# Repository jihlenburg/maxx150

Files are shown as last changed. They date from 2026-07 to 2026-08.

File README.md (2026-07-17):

# Belluna-Super-Fan-Adapter für den Challenger X150

Parametrisches FreeCAD-Modell eines 28-mm-Adapterrahmens für den Belluna Super
Fan im vorhandenen 400×400-mm-Dachausschnitt. Das Bauteil besteht aus vier
rotationsidentischen L-Segmenten und wird als ein Universalteil mit Stückzahl
vier bereitgestellt.

## Projektstatus

**Aktueller Parameterstand:** `8eb8b79f` · **GEOM_REV:** `10`
**Freigabestatus:** `PROTOTYPE_ONLY`

Geometrie-, DFM-, FEM-, analytische, Lastpfad- und digitale Passungsnachweise
sind Teil der Pipeline. Eine Produktionsfreigabe besteht trotzdem noch nicht:
Nicht verfügbare Werkstoff-/Haftversuche sind durch stark abgeminderte,
quellenbasierte Annahmen ersetzt (`PASS_ASSUMPTION_BASED`); endgültiger
Dachausschnitt, Doppelraupe und Holzrahmen bleiben beim Einbau zu
kontrollieren. Die acht seitlichen Dachrahmenschrauben sind eine physische,
aber mangels typgeprüftem Schraubgrund rechnerisch nicht angerechnete Reserve.
Die Dateien unter
[`release/current`](release/current/) sind daher ein nachvollziehbarer
Release Candidate, keine stillschweigende Serienfreigabe.

## Ein Einstiegspunkt

```sh
python3 -m pipeline doctor       # Werkzeugkette prüfen
python3 -m pipeline test         # komplette Testsuite
python3 -m pipeline engineering  # Konstruktion + DFM + FEM + Report + Export
python3 -m pipeline connections  # Klebe-, Schraub- und Dachsandwich-Lastpfade
python3 -m pipeline fit          # Belluna-Rekonstruktion gegen Adapter prüfen
python3 -m pipeline cfd          # aerodynamisches Hüllmodell + OpenFOAM
python3 -m pipeline render       # technische Konstruktionsansichten
python3 -m pipeline heatmap      # FEM-Heatmaps
python3 -m pipeline manual       # Montagebilder + PDF
python3 -m pipeline references   # Belluna-Referenzmodelle neu exportieren
python3 -m pipeline release      # verifizierten Stand paketieren
python3 -m pipeline all          # alle Stufen in Gate-Reihenfolge
```

Alle temporären Ergebnisse landen unter `build/<stufe>/<parameter-hash>/`.
Nur geordnete Herstellerreferenzen und der explizit paketierte Release
Candidate werden versioniert.

## Struktur

| Pfad | Verantwortung |
|---|---|
| `params.py` | einzige Quelle für Geometrie-, Last- und Materialparameter |
| `model/` | B-Rep-Rahmen, Segmentierung und DFM-Geometrie |
| `fem/` | Lastfälle, Materialmodell, CalculiX und analytische Nachweise |
| `analysis/` | Belluna-Passung sowie Klebe-, Schraub- und Sandwich-Lastpfade |
| `cfd/` | Belluna-Aerohüllmodell, OpenFOAM-Fall und Kräfteauswertung |
| `export/` | STEP/STL/3MF und technische Montagenotiz |
| `render/` | technische Blender-Ansichten und Heatmaps |
| `montage/` | Generator der illustrierten Montageanleitung |
| `pipeline/` | zentrale Orchestrierung und Release-Paketierung |
| `reference_models/` | parametrische Rekonstruktionen externer Schnittstellen |
| `references/` | Datenblätter, Belluna-Unterlagen und Referenzmodelle |
| `release/current/` | aktueller, manifestierter STL-/STEP-Stand |
| `docs/` | aktuelle Doku; historische Arbeitspläne nur unter `docs/archive/` |
| `tests/` | Suite inklusive Geometrie-, FEM-, Referenz- und Doku-Wächtern |
| `scripts/` | Bedienhelfer (Messwertübernahme nach `params.py`) |
| `bin/` | `fc`-Wrapper für headless FreeCAD |
| `project_paths.py` | zentrale Build-/Artefaktpfade für alle Stufen |
| `messwerte.json` | reale Messwerte (Eingabe für `scripts/apply_measurements.py`; kann uncommittete Nutzerdaten enthalten) |
| `messwerte.beispiel.json` | dokumentierte Feldvorlage des Messprotokolls |

### Ordnungsprinzipien

Die Struktur folgt vier Schichten — **Eingaben → Verwandlung → Wissen →
Ergebnisse** — mit fünf Regeln:

1. **Eine Quelle, ein Hash.** Alles beginnt bei `params.py`; der achtstellige
   Parameter-Hash steckt im Namen jedes Artefakts. Ein Artefakt ohne
   zugehörigen Report gilt als nicht nachvollziehbar.
2. **Code fließt in eine Richtung.** `model` baut Geometrie, `fem`/`analysis`/
   `cfd` beweisen sie, `export`/`render`/`montage` erzeugen Artefakte,
   `pipeline` orchestriert das als Gate-Kette. Kein Modul greift rückwärts.
3. **Versioniert wird Wissen, nicht Rechenergebnis.** `docs/` und der
   Quellenbestand unter `references/` sind nicht regenerierbar und daher
   getrackt; `build/` ist hash-segregierte Wegwerfware. Zwei getrackte Zonen
   schreibt die Pipeline selbst: `release/current/` (genau ein eingefrorener
   Stand, ausschließlich Release-Stufe) und `references/belluna/models/`
   (Belluna-Rekonstruktion, references-Stufe).
4. **Fremdes bleibt als Fremdes markiert.** Belluna-Modelle sind vermessene
   Rekonstruktionen; ihr Manifest pinnt sogar den SHA-256 der Quelldatei.
5. **Doku kann nicht veralten.** `tests/test_documentation.py` erzwingt
   intakte Links, aktuelle Einstiegspunkte und den aktuellen Parameterstand
   in README und Projektstatus.

Einsortierregel für neue Dateien: „Ist es Eingabe, Code, Wissen oder
Ergebnis?" beantwortet fast immer allein, wohin sie gehört.

## Offene Punkte und Historie

- Offene Arbeitspunkte: [`docs/project-status.md`](docs/project-status.md)
  (testgesichert aktuell; `TODO.md` in der Wurzel ist ein Symlink darauf).
- Projekthistorie: [`docs/archive/logbook.md`](docs/archive/logbook.md)
  sowie die SDD-Ledger unter `docs/archive/` (nicht normativ; `LOGBOOK.md`
  in der Wurzel ist ein Symlink darauf).

## Dokumentation

- [Dokumentationsindex](docs/README.md)
- [Aktuelles Design](docs/design.md)
- [Pipeline und Artefakte](docs/pipeline.md)
- [Nachweise und Freigabestatus](docs/verification.md)
- [Klebe-, Schraub- und Dachlastpfade](docs/load-paths.md)
- [CFD-Modell und Windlasten](docs/cfd.md)
- [Generator der Montageanleitung](docs/assembly-manual.md)
- [Referenz- und Datenblattkatalog](references/README.md)

## Grundregel

Jede geometriewirksame Änderung erhöht `Params.GEOM_REV`. Jede Änderung an
Parametern verändert den achtstelligen Parameter-Hash. Kein Fertigungsfile
gilt ohne zugehörigen Report und SHA-256-Manifest als nachvollziehbar.

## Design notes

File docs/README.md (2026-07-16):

# Dokumentation

Nur die folgenden Dateien beschreiben den aktuellen Projektstand:

- [`design.md`](design.md): Schnittstellen, Geometrie und Materialsystem.
- [`pipeline.md`](pipeline.md): Stufen, Werkzeuge, Verzeichnisse und Befehle.
- [`verification.md`](verification.md): Nachweise, Gates und Releasezustände.
- [`load-paths.md`](load-paths.md): konservative Klebe-, Schraub- und
  Dachsandwich-Abschätzung mit Quellen und Rechenannahmen.
- [`cfd.md`](cfd.md): Belluna-Aerohüllmodell, OpenFOAM-Fall und Modellgrenzen.
- [`assembly-manual.md`](assembly-manual.md): Aufbau des PDF-Generators.
- [`project-status.md`](project-status.md): offene physische und technische Punkte.
- [`measurements/`](measurements/): Messprotokoll und Messskizzen.

`archive/` enthält historische Implementierungspläne und Arbeitsnotizen. Sie
sind zur Nachvollziehbarkeit erhalten, aber nicht normativ. Bei Widersprüchen
gelten `params.py`, Tests und die aktuelle Dokumentation oben.

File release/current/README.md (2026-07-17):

# Aktueller Adapterstand

Parameterstand `8eb8b79f` · GEOM_REV `10` · Status `PROTOTYPE_ONLY`

- `Belluna_Adapter_Universal_x4_8eb8b79f.step`: ein Universalsegment in Einbaulage.
- `Belluna_Adapter_Universal_x4_PRINT_8eb8b79f.stl`: dasselbe Segment in Drucklage.
- Stückzahl: **4**, nur um Z drehen, nicht spiegeln.
- `verification_report_8eb8b79f.md`: zugehöriger rechnerischer Nachweis.
- `fit_summary_8eb8b79f.json`: digitaler Passungscheck gegen die Belluna-Rekonstruktion.
- `manifest.json`: Prüfsummen, Quellcommit, Werkzeugversionen und offene Gates.

`PROTOTYPE_ONLY` ist keine Produktionsfreigabe. Reale Einbaukontrollen und die Erkenntnisgrenze der annahmenbasierten Werkstoffpfade stehen in `docs/verification.md` und `docs/load-paths.md`.

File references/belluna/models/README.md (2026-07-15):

# Belluna-Referenzmodelle

Die Dateien in diesem Ordner sind eine **vermessene Projekt-Rekonstruktion**
der Belluna-Karosseriebefestigungsplatte einschließlich Metallclips und
Dichtring. Sie stammen nicht von Belluna und dürfen nicht als Hersteller-CAD
weitergegeben oder bezeichnet werden.

Quelle der Geometrie: `reference_models/belluna.py`.

Reproduzierbarer Export:

```sh
python3 -m pipeline references
```

`manifest.json` trennt gemessene von weiterhin angenommenen Abmessungen und
enthält die Prüfsummen sämtlicher STEP-/STL-Dateien.

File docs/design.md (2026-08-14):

# Design: 3D-gedruckter Adapterrahmen — Belluna Super Fan im Mini-Heki-Ausschnitt (Challenger X150 / Chausson X550)

Stand: 2026-07-16 · Parameterstand `8eb8b79f` · Status `PROTOTYPE_ONLY`

## 1. Ziel und Kontext

Der Belluna Super Fan Dachventilator soll den vorhandenen Mini-Heki im 400×400-mm-Dachausschnitt
eines Challenger X150 (baugleich Chausson X550) ersetzen. Das Dach dieser Fahrzeuge hat eine
umlaufende hohe Kante am Heck; die Lüfterhaube (Grundriss 593 mm lang, Überstand nach hinten)
würde beim Öffnen/Schließen mit dieser Kante kollidieren. Ein Adapterrahmen („Plinthe") hebt die
Lüfterbasis um **28 mm** an. Vorbild ist ein im X150-Forum dokumentierter, handgefertigter
Holzsockel; hier entsteht stattdessen ein **algorithmisch erzeugtes, 3D-gedrucktes, per FEM
verifiziertes** Bauteil.

Erzeugung und Verifikation laufen vollständig skriptiert über headless FreeCAD
mit Gmsh-Vernetzung und CalculiX-Solver aus dem FreeCAD-Bundle. Kein GUI-Schritt
ist Teil des reproduzierbaren Workflows.

## 2. Feste Eingangsdaten

### Aus der Belluna-Einbauanleitung (liegt vor, 22 S.)
| Größe | Wert |
|---|---|
| Lochgröße (Dachausschnitt) | 400 × 400 mm, Eckenradius R5 |
| Zulässige Einbauwandstärke | 27–80 mm |
| Vierkantwellen (mitgeliefert) | 120 mm ↔ 27–47 mm · 140 mm ↔ 48–67 mm · 160 mm ↔ 68–80 mm |
| Karosseriebefestigungsplatte | 593 × 420/450 mm, asymmetrischer Flansch (Überstand heckseitig) — Achtung, eigene Vermessung weicht ab: Flansch 450 × 450 voll symmetrisch, Kragen 397 (`reference_models/belluna.py`); 593 × 420 entspricht der Haube |
| Innenrahmen Lüfter | 445 × 445 mm |
| Haubenhöhe über Dach | 127 mm (zu) / 182 mm (offen) |
| Unterbau unter Dach | 31–47 mm |
| Befestigung laut Hersteller | Verklebung der Platte mit Carloflex (Ringklebenut); Verschraubung von oben nicht empfohlen (Wassereintritt); mechanische Option: seitliche Verschraubung in Holzrahmen |
| Schrauben | ST4.2×25 (Platte↔Karosserie, oben, nicht empfohlen) · ST3.9×40 (Lüfter↔Karosserie) · PT4.0×12 (Zwischen-↔Innenrahmen) |
| Masse Belluna | 5,0 kg |

### Fahrzeug (Challenger X150)
| Größe | Wert / Quelle |
|---|---|
| Dachstärke X-Modelle | **35 mm** (Hersteller-Diagramm: GFK-Außenhaut, XPS-Kern, Holzlage innen) |
| Dach am Ausschnitt | plan (Fotobefund), Mini-Heki in Dichtmittelbett verklebt |
| Reisegeschwindigkeit | bis 160 km/h |

### MaxxFan Deluxe (Hüllkurven-Lüfter für die Auslegung, Maßblatt liegt vor)
| Größe | Wert |
|---|---|
| Haube L × B | 586 × 408 mm |
| Höhe geschlossen / offen | 132 / 236 mm |
| Hecküberstand offen ab Dachausschnitt | 179 mm (123 mm bis Haubenknick) |
| Masse | 6,5 kg (Belluna: 5,0 kg) |

### Vermessene Belluna-Karosseriebefestigungsplatte
- Flanschoberseite plan, Schraublöcher verstöpselt; schwarze Dichtung umlaufend am Kragenfuß (Dichtebene Platte↔Lüftereinheit).
- Unterseite: Klebe-/Kontaktzone ist der **äußere Flanschbereich mit konzentrischen Ringrippen**
  (Ringklebenut); die Dreiecks-Gussets tauchen in den Ausschnitt und benötigen
  keine Deckflächenfreistellung.
- Unterer Einbaukragen: 397 mm außen, 1,5 mm Wand, 19 mm tief. Daraus folgen
  nominal 1,5 mm Radialluft je Seite in der 400-mm-Öffnung.
- Oben acht Federstahlclips als Schraubaufnahmen; schwarzer Dichtring 6 mm breit.
- Die versionierten STEP-/STL-Dateien unter `references/belluna/models/` sind
  eine Projekt-Rekonstruktion und ausdrücklich kein Hersteller-CAD.

### Abgeleitete Kerngröße
Effektive Einbauwandstärke = 35 mm Dach + 28 mm Adapter = **63 mm → 140er-Vierkantwelle**
(Bereich 48–67 mm, 4 mm Reserve zur Obergrenze). Die Pipeline berechnet die Wellenwahl aus den
Parametern und schreibt sie in die Montagenotiz.

## 3. Anforderungen

1. **Funktion:** Lüfterbasis um 28 mm anheben (`H_RAISE`, Parameter); Innenöffnung 400×400 mm
   fluchtend zum Dachausschnitt; Einbaukragen des Lüfters wird durchgesteckt wie durch ein 63-mm-Dach.
2. **Festigkeit:** Auslegungsanströmung 200 km/h (= 160 km/h Reise + Böen-/Gegenwindreserve),
   Schlechtweg ±4 g vertikal / ±2 g quer auf 6,5 kg Auslegungsmasse (Maxxfan-Hüllkurve; Belluna 5,0 kg).
3. **Temperatur:** Bauteiltemperatur −20 … **+85 °C** dauerhaft formstabil und tragfähig.
4. **Fertigung:** Druckservice, druckerunabhängig; Segment-Boundingbox ≤ 300 mm
   Kantenlänge (`SEG_MAX_BBOX` = 300 mm; Bambu H2D 350 mm verfügbar);
   stützenfrei druckbar. Das reale Segmentmaß ist ein automatisches DFM-Gate.
5. **Material & Prozess (§3.5):** **Würth ASA GF15 Verkehrsschwarz ähnlich
   RAL 9017, 1,75 mm, Art.-Nr. 4954641200** aus lokaler FDM-Fertigung
   (Plan-of-Record 2026-07-15). 15 % Glasfaser; gehärtete Düse und geschlossener,
   temperierter Bauraum sind Projektpflicht. Drucklage ist Deckfläche nach unten;
   47°-Kammerdächer, 47°-Entwässerungsfase und Ø4-Querkanäle sind supportfrei
   (47° zählen ab Horizontale = 43° Überhang aus der Senkrechten, konform zur
   45°-DFM-Grenze in §7).
   Brim ≥10 mm und langsames Abkühlen bleiben Pflicht. Würth nennt Dichte
   1,1 g/cm³ und HDT/B 99 °C bei 0,45 MPa, aber keinen HDT-Wert bei 1,82 MPa.
   Die publizierten mechanischen Werte stammen ausdrücklich aus Halbzeug, nicht
   aus FDM-Probekörpern. Deshalb bleiben E=3000 MPa, Zug=45 MPa, CTE=60e-6 1/K
   und Z-Faktor 0,5 konservative Projektannahmen. Da typgeprüfte XY-/Z-Coupons
   aktuell nicht realistisch verfügbar sind, werden diese Faktoren nicht
   hochgestuft; das Ergebnis bleibt `PASS_ASSUMPTION_BASED` (den Status
   `PROTOTYPE_ONLY` halten die offenen physischen Gates, s.
   `docs/verification.md`). Pauschales Tempern ist nicht freigegeben.
   Der schwarze Rohling wird vor dem Dacheinbau zwingend weiß beschichtet:
   Mipa 1K-Plastic-Grundierfiller-Spray (Art.-Nr. 213390000) plus Mipa PUR HS
   2K-PUR-Acryl-Fahrzeuglack RAL 9003 Signalweiß glänzend und Mipa 2K-MS-Härter
   MS 25 (2:1 Volumen). Weiß ist Teil der Thermikauslegung. ASA-GF steht nicht
   in der Primerliste; der Lack ist deshalb kein struktureller Lastpfad und
   wird jährlich kontrolliert.
6. **Befestigung:** Adapter ↔ Dach und Platte ↔ Adapter werden mit
   **Sikaflex-522 weiß** verklebt und abgedichtet (Elastikfuge bzw.
   Ringklebenut). **Carloflex 410 UV weiß** ist eine Belluna-konforme
   Alternative. Sein TDS nennt >1,8 MPa Zugfestigkeit, >450 % Dehnung und
   −40 bis +90 °C; die Lastpfadrechnung setzt daher für beide Produkte
   dieselben stark abgeminderten Grenzwerte von 0,030 MPa normal und
   0,050 MPa Schub an. 522 bleibt Standard, weil Sika den
   Vorbehandlungsprozess namentlich dokumentiert; das Carloflex-TDS nennt
   seinen Kunststoffprimer nicht. Je Baugruppe nur eines der beiden Systeme
   vollständig verwenden und nicht mischen. Die
   strukturellen Klebezonen bleiben lackfrei: ASA-GF/Belluna-Kunststoff sehr
   fein anschleifen, Sika Cleaner P und als ABS-Analogie Sika Primer-507;
   GFK-Gelcoat sehr fein anschleifen, Sika Cleaner P und Sika Aktivator-205
   gemäß jeweils aktuellem Produktdatenblatt. Acht Belluna-ST4.2×25 verbinden
   die äußeren Belluna-Seitenlöcher mit den lokalen Universalrippen; jede
   Seite hält ±140 und ±165 vor, ohne offene Vorratslöcher. Der Adapter wird
   zusätzlich mit acht seitlichen ST4.2×25 durch den Unterkragen im Holzrahmen
   gesichert. Diese Schrauben sind eine physische Rückfallebene; wegen der
   unbekannten Holz-, GFK- und Gewindetragfähigkeit werden sie rechnerisch
   nicht angerechnet. Der Primärnachweis wird allein von zwei getrennten,
   jeweils 10 mm breiten Sikaflex-Raupen geführt. Die äußere Raupe bleibt
   geschlossen und wasserdicht. Die innere besitzt acht 5-mm-Unterbrechungen
   zur trockenen Öffnungsseite, damit der dazwischenliegende 4-mm-Kanal
   Feuchte zur Durchhärtung nachführen kann. Die wirksame Fläche beträgt
   33.313 mm² bei 406 mm Innen- und 454 mm Außenmaß und liegt vollständig
   über dem nachgerüsteten 30-mm-Holzrahmen im XPS. Der Holzrahmen wird mit
   **SikaForce-710 L35 + SikaForce-010** (2K-PUR, 100:25 Volumen bzw.
   100:19 Gewicht) vollflächig eingesetzt. Das System ist ausdrücklich für
   Holz/GFK mit EPS/XPS-Sandwichkernen spezifiziert; Auftragsmenge und
   Pressprozess müssen gleichmäßig, hohlraumarm und unterhalb der
   Druckfestigkeit des Dachkerns bleiben. Er ist vollflächig verklebter
   Lastverteiler und Kompressionsschutz. Seine Schraubtragfähigkeit wird ohne
   Bauteilprüfung dennoch nicht als rechnerischer Lastpfad angesetzt. Verwendet werden
   trockene Nadelvollholz-Leisten mit ρk ≥ 350 kg/m³ und Faser längs zur
   jeweiligen Rahmenseite.
   Die zwei Belluna-Mittellöcher an den Segmentstößen bleiben frei. Keine Verschraubung
   von oben durch eine Dichtfläche.
   **Reale Einbausituation (User 2026-07-12): KEINE harte Klemmkette durchs Sandwich** —
   Lüfter geklebt + Kragen formschlüssig im Schacht, von unten nur die Zierblende.
   LF3 bleibt als bewusst konservative Hüllkurve (Montage-Grenzfälle). Die
   untere Doppelraupe trägt den Primärfall allein; die acht Seitenschrauben
   bleiben davon getrennte, unqualifizierte Reserve.
7. **Dichtheit:** 16 schmale Abstandspads definieren 3 mm Dachabstand; die
   0,6-mm-Applikationsführungen ergeben darin 3,6 mm wirksame Raupenhöhe.
   Geschlossene äußere Raupe und Kehlnaht bilden die Wassersperre. Die
   seitlichen Schrauben werden ausschließlich von der trockenen Öffnungsseite
   gesetzt und abgedichtet; sie durchdringen weder Dachaußenhaut noch äußere
   Wassersperre.

## 4. Bauteilgeometrie

**Grundform:** rechteckige Plinthe, Höhe `H_RAISE` = 28 mm, Innenöffnung 400×400 mm mit R5-Ecken.

**Querschnitt (umlaufend):**
- **Deckfläche:** plane Klebefläche unter der Ringklebenut-Zone der Platte; außerhalb
  des 450-mm-Flansches geht sie in eine 47°-Entwässerungsfase über. Breite je Seite
  einzeln parametrisierbar (`W_TOP_FRONT/REAR/LEFT/RIGHT`, Stand 50 mm), da der
  Plattenflansch asymmetrisch ist. Innen liegender Bereich mit parametrischer **Freistellung**
  (Tiefe `REC_GUSSET`) für die Dreiecks-Gussets der Plattenunterseite.
- **Innenwand:** 8 mm umlaufend; jede Seite besitzt an ±140 und ±165 mm
  lokale 10-mm-Vollmaterialrippen über den ganzen 25-mm-Schraubpfad. Acht
  der sechzehn möglichen Pfade werden durch die realen Belluna-Löcher genutzt.
  Die Rippen sind oben an die Deckplatte angebunden und laufen unten mit 45°
  aus; dadurch bleiben die 43-mm-Kammerzellen weitgehend erhalten und der
  Druck bleibt supportfrei. Kollidierende Ventkanäle werden innerhalb ihrer
  Zelle aus der Rippe verschoben.
- **Außenwand:** geschlossen, unten gefast für die Elastikfugen-Kehlnaht zum Dach.
- **Innenleben:** geschlossene Rippenkammern (zwei konzentrische Kammerringe je Seite,
  Zellenraster parametrisch, Wände/Platten voll dicht gedruckt). Kammerböden (in
§3.5 aus der anderen Bezugslage „Kammerdächer" genannt) als 47°-Chevron
  (stützenfrei in Druckorientierung), horizontale Ø4-Druckausgleichsbohrungen je Zelle
  zur Innenseite. Stoß- und Schraubzonen bleiben
  massiv. Die zwei 17-mm-Ringe füllen das kompakte 50-mm-Band, ohne es als
  28-mm-Massivquerschnitt zu drucken; die Außenwand bleibt 3 mm.
  Eckkammern (90°-Rotationsfortsetzung der Kammerringe um die vier Eckblöcke,
  Task 17) sind seit 2026-07-12 Default EIN (`CORNER_CHAMBERS = True`, Task 20;
  Verzugs-/Gewichtsnutzen, FEM-verifiziert — abschaltbar, die AUS-Variante bleibt
  volumen-anker-geprüft reproduzierbar). Damit ist die Festigkeit geometrie-definiert
  (druckprofil-unabhängig); die FEM rechnet auf der echten Kammergeometrie mit vollem
  E-Modul (INFILL_FACTOR = 1,0). [Entscheidung mit User 2026-07-12, ersetzt
  Slicer-Infill-Ansatz]
- **Unterseite:** 16 längliche Abstandspads (2,5×20×3 mm), jeweils innen und
  außen nahe den acht unteren Schraubachsen. Sie liegen vollständig in den
  trockenen 3-mm-Randstreifen über dem Holzrahmen und greifen nicht in die
  Klebefläche ein. Zwei umlaufende, nur 0,6 mm tiefe und 10 mm breite
  Applikationsführungen liegen ebenfalls vollständig über dem 30-mm-Holzrahmen.
  Die äußere Führung ist geschlossen; die innere besitzt acht modellierte
  5-mm-Brücken, welche den 4-mm-Mittelkanal zur trockenen Öffnungsseite
  entlüften. Gegenüber den früheren 68 Ø8-mm-Rundnoppen sinken harte
  Kontaktfläche und lokale Montagepressung deutlich.

**Segmentierung:** Standard **ein rotationsidentisches L-Ecksegment, 4× drucken**,
Stöße in den Seitenmitten (Spannungsmaxima liegen an den Ecken). Stoßverbindung: Halbüberlappung
(Toleranz `TOL_JOINT` = 0,25 mm, nach Probedruck justierbar) + eine
Durchsteckschraube M5 je Stoß + Klebefläche. Unter der vollständigen
konservativen 480-N-Stoßhülle liegt der einzelne M5 bei 62 %
Lochleibungsauslastung. Die Epoxidklebung wird getrennt mit 77 % nachgewiesen.
Die vier
Kopien werden nur um Z gedreht, nie gespiegelt; ein starker Geometrietest
prüft die Rotationsidentität über die symmetrische Differenz.

**Thermik konstruktiv:** ASA-GF α = 60 µm/(m·K), konservative
Datenblatt-Lückenannahme, vs. GFK ≈25. Der mit Epoxid und M5 vollständig
gefügte Rahmen wird thermisch als **500-mm-Baugruppe**, nicht als entkoppeltes
Drucksegment gerechnet. Von 20 °C Klebetemperatur bis 85 °C entstehen 1,14 mm
Differenzdehnung über die Kante; symmetrisch je Ende (0,57 mm) ergibt dies
rund 38 % des zulässigen Scherbewegungsgrenzwerts (50 % der konservativ mit
3 mm angesetzten Fugenhöhe = 1,5 mm); die reale Raupenhöhe in den
0,6-mm-Führungen beträgt 3,6 mm.
Die Lastaufnahme erfolgt ausschließlich durch die elastische Klebschicht.
Die Pads sind Montageanschläge, kein dauerhafter rechnerischer Lastpfad.

**Dichtheitskonzept (Mehrteiligkeit):** Dichtheit kommt von durchgehenden Elastomer-Ebenen,
nicht vom Druckteil — die Segmentstöße werden von diesen Ebenen überbrückt. Barrierenkette:
(1) erst nach vollständiger Durchhärtung der tragenden Dachraupen aufgebrachte,
zugängliche Sikaflex-522-Schutzkehle außen, umlaufend geschlossen über alle
Stöße; sie ist erneuerbare Wetter-/Kontrollfuge und erhält keine
Tragfähigkeitsgutschrift; (2) äußere
untere Raupe, geschlossen über die Stöße; die innere Raupe ergänzt Tragfläche,
bleibt aber an acht Trockenraum-Vents offen; (3) Ringklebenut der Belluna-Platte auf der
Deckfläche, ebenfalls geschlossen; (4) Stöße selbst: Halbüberlappungs-Labyrinth + vollflächige
2K-Epoxidverklebung der Fügeflächen (M5 = Verpressung/Redundanz, nicht Dichtung).

**Klebstoffwechsel 2026-08-14:** WEICON RK-1300 ist abgelöst. Der MMA-Klebstoff
war rechnerisch passend, hat am realen gedruckten ASA-GF aber nicht getragen.
Ausgewählt ist jetzt **UHU plus endfest 300**, ein 2K-Epoxid mit 90 min
Topfzeit, −40 bis +100 °C und 1:1 aus der Doppelkammerspritze mit statischem
Mischer. Es ist ohne Aktivator, Waage und Zeitdruck zu verarbeiten und deshalb
für die Laienmontage geeignet. Der Bemessungswert bleibt bewusst 0,50 MPa,
obwohl er nun aus 16,5 MPa nach DIN EN 1465 statt aus 6 MPa auf ABS abgeleitet
wird: der Wechsel soll die Nachweiskette nicht rechnerisch entlasten. Der
Abminderungsfaktor steigt damit von 12 auf 33. Der WEICON Epoxyd-Minutenkleber
bleibt trotzdem verworfen, sein TDS nennt nur 2,7 % Bruchdehnung und Tg 44,7 °C
(46,1 °C nach Tempern), also deutlich unter `T_MAX = 85 °C`. Dieselbe Grenze
schließt alle schnellen 5-Minuten-Epoxide aus. Die 0,25 mm `TOL_JOINT` bleiben
unverändert, denn sie liegen im gut verklebbaren Bereich des Epoxids. Damit ist
keine Geometrieänderung verbunden und `GEOM_REV` bleibt stehen.

Drei Punkte aus dem Merkblatt sind ausdrücklich nicht übernommen. Das Merkblatt
nennt Aceton zum Entfetten, das ASA angreift. Auf den Druckteilen wird deshalb
Isopropanol verwendet. Das Merkblatt erlaubt eine Warmhärtung zwischen 70 und
180 °C mit deutlich höheren Festigkeiten, etwa 20 N/mm² nach 45 min bei 70 °C.
Das bleibt ungenutzt, weil für ASA-GF kein pauschales Tempern freigegeben ist.
Die geprüften Klebstoffdicken liegen bei 0,1 und 0,2 mm und damit unter der
Passungsluft von 0,25 mm je Fügefläche, was in der Abminderung mit abgedeckt
ist. Verbindlich bleibt die Verarbeitung bei 18 bis 20 °C: unter 18 °C nennt
das Merkblatt ausdrücklich schlechte Bindefestigkeiten.
FDM-Mikroporosität: ≥4 Perimeter als dichte Haut; der festgelegte Mipa-Primer +
RAL-9003-2K-PUR-Decklack ist PFLICHT (Solarreflexion, Porenschluss, Wetterschutz).
Validierung praktisch (Flutungstest, dann Hochdruck aus
ISO-20653-9K-Abstand am verbauten Sockel); eine normative IP6K9K-Zertifizierung wäre
Prüfstandssache. Systemgrenze: der Belluna selbst ist nur IPX4 — Ziel ist die dichte
Dachdurchdringung, nicht ein dichter Lüfter.

## 5. Software-Architektur

```
maxx150/
├── params.py             # einzige Parameterquelle
├── model/                # B-Rep, Segmente und DFM
├── fem/                  # Lastfälle, Solver, Analytik und Report
├── analysis/             # digitale Passungsanalyse
├── export/               # STEP/STL/3MF und technische Notiz
├── render/               # technische Ansichten und Heatmaps
├── montage/              # Generator der Montageanleitung
├── pipeline/             # zentrale CLI und Release-Paketierung
├── reference_models/     # vermessene externe Schnittstellen
├── references/           # Datenblätter, Anleitungen und Referenz-CAD
├── build/                # generiert, hash-segregiert, gitignored
├── release/current/      # manifestierter Fertigungsstand
└── tests/                # Invarianten und Regressionen
```

**Datenfluss:** `params.py` → `frame.py` (ein wasserdichtes Solid) → (a) `segments.py` →
`export.py`; (b) `fem/`. Der Report verknüpft Parameterstand ↔ FEM-Ergebnis ↔ Datei-Hashes:
kein Druckfile ohne zugehörige Verifikation.

**FEM-Modellstrategie:** Globalnachweis am **ungeteilten** Rahmen (obere Steifigkeitsschranke),
Detailnachweis am Stoß-Submodell mit den Schnittkräften aus dem Globalmodell (untere Schranke).
Kein Vollkontaktmodell aller vier Segmente in CalculiX. Die globale Lagerung
liegt seit GEOM_REV 9 verteilt auf den Böden beider Kleberführungen. Sie
idealisiert Dach und ausgehärteten Klebstoff weiterhin starr, fixiert aber
nicht mehr die 16 Montagepads und vermeidet damit die früheren künstlichen
Punktspannungen an 68 Rundnoppen.

**Fehlerbehandlung:** Jeder Schritt validiert sein Ergebnis (Solid `isValid()` + geschlossene
Shell, Mindestwandstärke, Mesh-Qualität, CalculiX-Konvergenz) und bricht mit klarer Meldung ab,
statt fehlerhafte Artefakte zu exportieren.

## 6. FEM-Verifikation

**Lastfälle:**
| # | Lastfall | Ansatz |
|---|---|---|
| LF1 | Fahrtwind | 200 km/h → q ≈ 1,85 kPa; Haube offen (zulässig lt. Anleitung), Worst Case MaxxFan Deluxe: A = 0,408 m × (0,236 + 0,028) m ≈ 0,108 m² (Maßblatt), cd ≈ 1,2 → ~240 N horizontal, ×2 Sicherheit = **480 N** am Hebelarm der Haubenhöhe (Kippmoment auf Deckfläche) |
| LF2 | Schlechtweg | quasistatisch ±4 g vert. / ±2 g quer auf 6,5 kg → ±255 N / ±128 N |
| LF3 | Klemmung/Montage | Vorspannung Innenrahmen-Verschraubung (aus 0,7 Nm Anzugsmoment lt. Anleitung ≈ 400–600 N je Schraube, konservativ 600 N × 4) + Anzug der Seitenschrauben; Schraubenauszug/Flächenpressung Innenwand. **Konservative Hüllkurve: real keine harte Klemmung (s. §3.6)** |
| LF4 | Schnee/Stand | 0,75 kN/m² auf 0,25 m² Grundfläche = 187,5 N, konservativ 200 N angesetzt |
| LF5 | Thermik | Einsatzbereich −20…+85 °C; bemessungsrelevant ΔT 65 K ab 20 °C Klebetemperatur, CTE-Differenz ASA↔GFK; Nachweis Elastikfuge (analytisch, `fem/analytic.py`) |

**Materialabminderung Würth ASA GF15:** Projektbasis 45 MPa / E 3000 MPa;
keine Behauptung gedruckter Herstellerwerte, da Würth nur Halbzeugdaten nennt.
Faktoren: Temperatur 0,5 · Z-Schichthaftung 0,5 (konservative Annahme) ·
Kriechen 0,4. → zulässig **4,50 MPa dauerhaft**, **11,25 MPa kurzzeitig**.
Drucklage so, dass
Hauptspannungen in der XY-Ebene liegen (Z sieht überwiegend Druck).

**Bestehenskriterien (Pipeline-Gate, automatisch):**
1. σ_vMises ≤ zulässig je Lastfall (Sicherheiten enthalten)
2. Verformung der Deckfläche < 0,5 mm (Dichtheit der Klebefuge)
3. Elastische Klebfuge: 0,030 MPa normal / 0,050 MPa Schub als stark
   abgeminderte Projektwerte; Schraubengruppen separat mit vollständigem
   Lastfall und 1,5-facher Lastkonzentration
4. Flächenpressung/Auszug an der Innenwand ≤ zulässig
5. Optionale Eskalation bei FAIL: Rippen/Wände verstärken (Parameter) oder Material ASA-GF/PC.

## 7. Export, Fertigung, Tests

**Export:** STEP gesamt + genau eine Universal-Segmentdatei (`universal_segment_x4`)
als STEP, STL und 3MF; Dateinamen mit Parameter-Hash.
Auto-generierte Fertigungs-/Montagenotiz: Druckorientierung (liegend auf Deckfläche),
≥4 Perimeter, 100 % Infill (Kammern tragen die Gewichtsreduktion), kein
pauschales Tempern, Schraubenliste, exakte Kleb-/Dicht-/Lackprodukte und Dichtklebstoff-Bedarf (aus
Raupenlänge/-querschnitt berechnet), berechnete Wellenwahl (140 mm bei 35+28).

**DFM als Code-Invarianten:** Überhänge ≤ 45° aus der Senkrechten (stützenfrei;
die 47°-Chevronflächen zählen ab Horizontale = 43° Überhang und sind konform), Mindestwand 2,4 mm, Rippen 1,6 mm,
Nut-Feder-Toleranz parametrisch.

**Tests (headless in FreeCADCmd):**
1. Geometrie-Invarianten: wasserdicht/valide, Öffnung exakt 400×400, Höhe = `H_RAISE`, BBox-Bereich
2. Passung: Feder < Nut um exakt `TOL_JOINT`; boolesche Vereinigung der Segmente ≡ Rahmen − Fugenvolumen
3. DFM-Checks: Überhangwinkel-Scan, Wandstärken-Stichproben
4. FEM-Regression: Referenzparametersatz → erwartete max. Spannung/Verformung ±Toleranz
5. Toolchain-Smokes für Gmsh/CalculiX, Export und Referenzkatalog
6. Digitaler Belluna-Passungscheck: Kollision, Radialspiel, Auflage und Schraubpfade

**Freigabe-Workflow:** `pipeline test` → `pipeline engineering`
(einschließlich `pipeline connections`) → `pipeline fit`
→ reale Einbaukontrollen → `pipeline release`. Die nicht verfügbaren
Werkstoffversuche werden nicht als geschlossen behauptet; ihre Unsicherheit
bleibt über die Abminderungen und `PROTOTYPE_ONLY` sichtbar.

## 8. Offene reale Eingaben

Die Belluna-Plattenschnittstelle ist vermessen und in der Referenzrekonstruktion
dokumentiert. Am Fahrzeug bleiben offen:

1. Realmaß Dachausschnitt (Soll 400×400) + Eckenradius nach Mini-Heki-Demontage.
2. Abstand Ausschnitt-Hinterkante → hohe Dachkante und deren Höhe (**Verifikation der 28 mm**:
   geometrischer Haubenfreigang wird aus diesen Werten im Modell nachgerechnet)
3. Kontrollmessung der Dachstärke am Ausschnitt (Planstand 35 mm).
4. Zustand der Klebefläche und des XPS nach Demontage.
5. Abmessungen und Pressprozess des nachgerüsteten Holzrahmens.

Bis zur Messung bleiben die betreffenden Werte in `params.py` als dokumentierte
Defaults und erzwingen den Status `PROTOTYPE_ONLY`.

## 9. Entscheidungen (Log)

| Entscheidung | Wahl | Alternativen (verworfen) |
|---|---|---|
| Pipeline | A: vollparametrisch, headless FreeCAD + CalculiX | B: GUI+Spreadsheet (nicht reproduzierbar) · C: CadQuery-Stack (Werkzeugvorgabe FreeCAD) |
| Material | **Würth ASA GF15 Verkehrsschwarz, Art.-Nr. 4954641200 + Pflichtlackierung Mipa RAL 9003** | weißes Filament ist nicht verfügbar · PC/ABS erfordert neue UV-/CTE-/Klebe-/Lackqualifikation |
| Befestigung | oben Kleben + 8 seitliche Schrauben; unten 2×10-mm-Doppelraupe plus 8 unbewertete Seitenschrauben | ursprüngliche 8-mm-Einzelraupe (rechnerisch unzureichend) · 25-mm-Bond-only-Verbreiterung (größer/schwerer) · Klemmen (Kriechen der Klemmstelle) |
| Segmentierung | 1 rotationsidentisches L-Ecksegment ×4, Stoß in Seitenmitte | vier seitenspezifische Dateien (Logistik/Verwechslung) · Monolith (kein Bauraum) · 8 Teile (mehr Fugen) |
| Erhöhung | 28 mm (Forum-Vorbild), als Parameter | am realen Haubenfreigang zu verifizieren |
| Welle | 140 mm (aus 35+28 berechnet) | — Pipeline rechnet bei Parameteränderung neu |
| Dach-Befestigung | Zwei 10-mm-Sikaflex-522-Raupen mit 406/454-mm-Hüllmaß vollständig über dem vollflächig eingeklebten Holzrahmen; 16 schmale 2,5×20×3-mm-Abstandspads außerhalb der Klebeflächen, 0,6-mm-Applikationsführungen (drei 0,2-mm-Layer) und 3,6-mm-Raupenhöhe; äußere Raupe geschlossen, innerer Mittelkanal gezielt zur trockenen Seite belüftet; erst nach Primärhärtung eine zugängliche, nichttragende 7×7-mm-Schutzkehle außen; acht seitliche, abgedichtete ST4.2×25 als nicht angerechnete Reserve | 68 Ø8-mm-Rundnoppen mit 5-mm-Raupenhöhe und Punktlasten · ursprüngliche 8-mm-Fuge (unzureichend) · 25-mm-Bond-only-Verbreiterung je Seite (550-mm-Außenmaß und höheres Teilegewicht) · Schrauben durch nasse Dachfläche |

## 10. Risiken und Gegenmaßnahmen

| Risiko | Gegenmaßnahme |
|---|---|
| Kriechen unter Dauerklemmung bei Hitze | Dauerlast-Zulässigkeit 4,50 MPa; LF3-Hüllkurvenannahme: ein etwaiger Klemmpfad läuft über Dach+Adapter-Druckflächen (real keine harte Klemmkette, s. §3.6); FEM LF3 |
| Schichthaftung (Z) versagt | Drucklage: Lasten in XY; permanenter Knockdown 0,5; kein pauschales Tempern |
| Thermodehnung reißt Klebfuge | 16 Pads erzwingen 3 mm Dachabstand; in den flachen Führungen entstehen 3,6 mm Raupenhöhe. LF5 rechnet konservativ weiter mit 3 mm und erreicht 38 % des thermischen Scherbewegungsgrenzwerts. |
| Druckservice-Toleranzen an den Stößen | `TOL_JOINT` parametrisch, Probedruck eines Stoßpaars vor Vollbestellung (Montagenotiz) |
| 28 mm reichen nicht (Haube streift) | reale Fahrzeugmaße + geometrischer Freigang-Check vor Produktionsfreigabe |
| Schwarzer Rohling heizt sich solar auf / Lack löst sich | RAL-9003-Pflichtlackierung mit festgelegtem Mipa-System; Lack trägt keine Struktur; jährliche Kontrolle und sofortige Ausbesserung |
| Reale Grenzfläche schwächer als Datenblatt | `analysis/load_paths.py`: Sikaflex bis Faktor 60, Segmentstoß-Epoxid Faktor 33 und Sandwich auf 0,05 MPa abgemindert; Ergebnis bleibt `PASS_ASSUMPTION_BASED`, nicht zugelassen |
| Zyklische Ermüdung (Thermozyklen x Vibration) nicht im FEM-Kollektiv | Dokumentiertes Restrisiko (quasistatische LF + konservative Faktoren decken es nur indirekt); Gegenmaßnahme: jährliche Sichtprüfung der Nähte, Flutungstest nach 1. Saison [DA-Review] |
| Klemmkraft-Relaxation ASA bei 85 °C | Entschärft: real keine harte Klemmkette (§3.6) — Restrisiko nur seitliche Schrauben; Feder-/Sicherungselemente + Nachziehen bleiben empfohlen [DA-Review, aktualisiert] |
| Freigang-Gate läuft auf Defaults (`EDGE_DIST/EDGE_H`) | Report und Release bleiben `PROTOTYPE_ONLY`, bis reale Fahrzeugmaße vorliegen |

## 11. Erfolgskriterien

1. `python3 -m pipeline engineering` läuft fehlerfrei durch: Modell → DFM → FEM → Export → Report.
2. Alle Tests grün, inkl. Segmente-≡-Monolith und DFM-Checks.
3. Druckdateien: 1 Universal-Segment ×4, rotationsidentisch, stützenfrei,
   Boundingbox ≤ 300 mm.
4. Physisch: Segmente fügen sich passgenau, Lüfter mit 140er-Welle montierbar, Haube öffnet
   kollisionsfrei über der Dachkante, dicht nach Regenfahrt.

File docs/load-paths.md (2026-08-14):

# Abschätzung der Klebe-, Schraub- und Dachlastpfade

Stand: 2026-07-16 · Parameterstand `8eb8b79f` · **PASS_ASSUMPTION_BASED**

> Konservative Plausibilisierung, keine Bauteilzulassung. Die untere
> Doppelraupe trägt den Primärnachweis allein; acht seitliche Holzschrauben
> bleiben eine physische, aber unqualifizierte Reserve.

## Ergebnisübersicht

| Lastfall | obere Elastikfuge allein | 8 Schrauben oben | 2×10-mm-Dachraupe allein | erforderliche Kapazität je Rückfallschraube | Holz–Dach, eine Fläche | serieller Pfad |
|---|---:|---:|---:|---:|---:|---|
| Windhülle 480 N | 157 % | 74 % | 77 % | 144 N (nicht qualifiziert) | 35 % | PASS |
| Schlechtweg | 98 % | 43 % | 44 % | 81 N (nicht qualifiziert) | 18 % | PASS |
| Schnee/Druck | 0 % | 21 % | 0 % | 38 N (nicht qualifiziert) | 0 % | PASS |
| CFD offen, mittel ×1,5 | 71 % | 32 % | 29 % | 54 N (nicht qualifiziert) | 12 % | PASS |

Die obere Belluna-Verbindung bleibt hybrid: Kleber und die acht oberen
Plattenschrauben werden nicht addiert; die Schraubengruppe trägt den vollständigen Fall mit
Lastkonzentrationsfaktor 1,5. Unten müssen die beiden 10-mm-Raupen den
vollständigen Fall allein bestehen. Die acht Holzschrauben werden weder zur
Klebung addiert noch als PASS gewertet. Der Schubgrenzwert 0,050 MPa ist kein
TDS-Schubkennwert, sondern eine bewusst niedrige Projektannahme. Reale
Grenzflächenhaftung und Alterung bleiben unbekannt.

Die CFD-Zeile ist eine zusätzliche Sensitivität aus Matrix `a3a2de8c` und
bleibt nicht freigabewirksam. Die analytische 480-N-Windhülle wird dadurch
nicht reduziert.

## Maßgebende Festwerte

- Obere Ringfuge: 14.016 mm²; 0,030 MPa normal / 0,050 MPa Schub, nicht allein
  maßgebend.
- Untere Doppelraupe: 33.313 mm² wirksam, Innenmaß 406 mm, Außenmaß 454 mm;
  vollständig über dem 30-mm-Holzrahmen, acht innere Trockenraum-Vents,
  0,030/0,050 MPa. Fläche und Volumen folgen den echten gerundeten
  R5-Parallelkonturen; eine Quadratnäherung wird nicht verwendet. 3 mm
  Padabstand plus 0,6 mm Führungsvertiefung ergeben 3,6 mm Raupenhöhe und
  rund 120 ml Nennvolumen.
- Obere ST4.2×25 in ASA-GF: 178 N je Schraube nach Detailfaktor 0,5.
- Segmentstoß unter vollen 480 N: 2K-Epoxid 77 %; ein M5 62 %; beide getrennt PASS.
- Thermische Scherbewegung der 3-mm-Fuge: 38 % des 50-%-Grenzwerts; PASS.
- Obere Schraubengruppe: Eine fehlende Schraube ergibt 83–87 %. Zwei fehlende
  Schrauben bestehen nicht in jeder Anordnung. Alle acht Belluna-Schrauben
  bleiben Pflicht.

## Konstruktive Interpretation

- Der Adapter bleibt bei 500 mm Außenmaß. Zwei getrennte 10-mm-Raupen liefern
  trotz acht 5-mm-Ventunterbrechungen rund 33.313 mm² wirksame Klebefläche.
- 16 schmale Abstandspads mit 2,5×20 mm Kontaktmaß sitzen in den trockenen inneren und äußeren
  Randstreifen nahe den acht Dachschrauben. Sie definieren nur den
  Montagespalt und werden weder von der Klebefläche abgezogen noch als
  struktureller Lastpfad angerechnet.
- Die äußere Raupe bleibt als Wassersperre geschlossen. Nur die innere Raupe
  wird an acht Stellen zur trockenen Öffnungsseite unterbrochen, damit der
  4-mm-Mittelkanal Feuchte nachführen kann. Die Unterbrechungen und der Kanal
  dürfen bei der Montage nicht mit Dichtstoff überbrückt werden.
- Erst nach vollständiger Durchhärtung der tragenden Doppelraupe wird außen
  eine etwa 7×7-mm-Sikaflex-522-Schutzkehle ergänzt (nominal rund 48 ml).
  Sie bleibt sichtbar und erneuerbar und erhält keinerlei
  Tragfähigkeitsgutschrift.
- Acht seitliche ST4.2×25 sichern den Unterkragen im Holzrahmen. Ohne
  typgeprüften Schraubgrund wird nur der je Lastfall erforderliche Wert
  ausgewiesen; die Schrauben werden nicht angerechnet.
- Ein M5 je Stoß trägt die volle 480-N-Hülle allein. Das 2K-Epoxid bildet einen davon
  getrennt geprüften Fügepfad.
- Sikaflex-522 und Carloflex 410 UV werden nur mit den stark abgeminderten
  0,030/0,050-MPa-Werten angesetzt. Produkte innerhalb einer Baugruppe nicht
  mischen.

## Oberflächenannahme für Sikaflex-522

Die tragenden Klebezonen bleiben lackfrei. ASA-GF und Belluna-Kunststoff
werden sehr fein angeschliffen, mit Sika Cleaner P gereinigt und als
ABS-Analogie mit Sika Primer-507 vorbehandelt. GFK-Gelcoat wird sehr fein
angeschliffen, gereinigt und mit Sika Aktivator-205 vorbehandelt. ASA-GF ist
nicht ausdrücklich in der Sika-Tabelle genannt; die Rechnung ist daher keine
Herstellerfreigabe. Carloflex bleibt erst nach prozesssicherer Festlegung
seines im TDS nicht namentlich genannten Kunststoffprimers eine ausführbare
Alternative.

## Modellgrenzen

- Starrer Ring und linear-elastische Lastverteilung; lokale Peelspitzen und
  Gehäusenachgiebigkeit sind nicht aufgelöst.
- Die Rahmen-FEM fixiert die Böden beider Kleberführungen flächig. Das
  beseitigt die frühere künstliche Rundnoppen-Lagerkonzentration, bildet aber
  die reale Nachgiebigkeit des 3,6-mm-Klebstoffs und des GFK-Dachs noch nicht ab.
- Die zwei unteren 10-mm-Elastikraupen sind der allein angerechnete
  Adapter-Dach-Primärpfad. Die acht unteren Seitenschrauben sind mangels
  Holz-/Dachtest nur physische Reserve.
- Die acht oberen ST4.2×25 werden mit einem abgeminderten axialen Analogiewert
  auf den resultierenden Lastvektor geprüft.
- Der einzelne M5 je Segmentstoß wird mit der vollen 480-N-Hülle geprüft;
  expliziter Bolzenkontakt und Lochspiel sind nicht aufgelöst.
- Das reale X150-GFK/XPS-Sandwich ist nicht typgeprüft; deshalb werden nur eine
  Holz/GFK-Fläche und 0,050 MPa angerechnet.
- Werkstoffkriechen unter Dauerlast ist pauschal über `DERATE_CREEP` (0,4 auf
  die dauerhaft zulässige Spannung) abgedeckt. Nicht modelliert ist das
  Setzen/die Vorspannkraftrelaxation der oberen Schraubgruppe (Kunststoff im
  Klemmpaket, beschleunigt nahe `T_MAX`): Die Schraubnachweise sind
  Tragfähigkeits-, keine Reibschlussnachweise und bleiben davon unberührt;
  gegen Lockern unter Fahrvibration gilt die Setzkontrolle nach den ersten
  Fahrten und die jährliche Prüfung (`verification.md`).
- Thermozyklen sind nur als statische Extremfälle geprüft (LF5, ΔT 65 K).
  Tag/Nacht-Zyklen (ΔT ≈ 40 K, tausendfach über die Lebensdauer) erzeugen in
  der unteren Elastikfuge eine Schubverzerrungs-Amplitude von rund 60 % des
  statischen LF5-Werts — bei 38 % statischer Auslastung gegen die bereits
  stark abgeminderte Elastikfugen-Annahme wird das als abgedeckt eingestuft,
  bleibt aber eine dokumentierte Annahme ohne Ermüdungsversuch.
- CFD, FEM und Lastpfadrechnung sind Modellplausibilisierungen, keine
  Bauteilprüfung oder Herstellerfreigabe.

## Primärquellen

- [Sikaflex-522: 1,8 MPa Zugfestigkeit, 400 % Bruchdehnung, −50 bis +90 °C](https://industry.sika.com/en/home/transportation/sealants/adhesive-sealants/sikaflex-522.html)
- [Sika-Leitfaden: zusätzliche, zugängliche Schutzdichtung sowie verzögerte Durchhärtung bei zu frühem Schließen angrenzender Fugen](https://industry.sika.com/dam/dms/global-industry/4/bonding-and-sealingwith1-componentsikaflex.pdf)
- [Sika-Kompendium: Abminderung und typische zulässige thermische Scherverformung](https://industry.sika.com/dms/getdocument.get/8ffff4cd-c90d-4d24-969d-ee4db9093cf3_global-industry/compendium-elasticbonding.pdf)
- [Sika-STP-Vorbehandlungstabelle, Version 8, 02/2026](https://industry.sika.com/dms/getdocument.get/776a779a-10a6-413c-b20b-c46467315e33/pre-treatment-chartforsilanterminatedpolymersstp-sikaflex-500ser.pdf)
- [UHU plus endfest 300: Topfzeit, Temperaturbereich und Zugscherfestigkeit](../references/datasheets/adhesives/uhu-plus-endfest-300.pdf)
- [SikaForce-710 L35 für Holz/GFK-Sandwich mit EPS/XPS-Kern](https://deu.sika.com/dms/getdocument.get/41466f3f-1639-4fc4-8298-5c9a0a2d34e1/sikaforce-710-l35.pdf)
- [URSA-XPS-Vergleichswert TR 200; nicht das X150-Material](https://ursa.de/wp-content/uploads/2023/05/DB-xps.pdf)
- [Carloflex-410-UV-Quelldokument](../references/datasheets/adhesives/carloflex-410-uv-source.md)

Die maschinenlesbare Fassung wird mit `python3 -m pipeline connections` nach
`build/analysis/load_paths/<hash>/` geschrieben.

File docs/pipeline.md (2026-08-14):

# Pipeline und Artefakte

## Datenfluss

```text
params.py
   ├─ model/ ── DFM ── FEM + Analytik ── export/ ── build/engineering/<hash>/
   ├─ reference_models/ + model/ ── Passung ─────── build/analysis/fit/<hash>/
   ├─ Lasten + Verbindungsannahmen ─────────────── build/analysis/load_paths/<hash>/
   ├─ Belluna-Anleitung + Dach ── OpenFOAM ──────── build/analysis/cfd/<cfd-hash>/
   ├─ fem/ ── Spannungsfelder ── Blender ───────── build/analysis/heatmap/<hash>/
   ├─ model/ ── Blender ────────────────────────── build/render/<hash>/
   └─ model/ + Belluna + Dach ── Blender ── PDF ─ build/documentation/<hash>/
                                                        │
                               explizite Paketierung ───┴─ release/current/
```

## Kanonische Stufen

| Stufe | Inhalt | Gate/Ergebnis |
|---|---|---|
| `doctor` | FreeCAD, Blender, Chrome, pdfinfo und Pfade | bricht bei fehlendem Werkzeug ab |
| `test` | Geometrie-, FEM-, Export-, Referenz- und Toolchaintests | alle Tests müssen bestehen |
| `engineering` | Rahmen, Segmente, DFM, vier globale Lastfälle, Stoßmodell, Analytik, Export; ruft danach `connections` auf | Reports dürfen nicht `FAIL` sein |
| `connections` | obere Acht-Schrauben-Gruppe, 2×10-mm-Dachraupe, acht nicht angerechnete untere Seitenschrauben, 2K-Epoxid/ein M5 je Stoß und Holzrahmen–Dachsandwich | `PASS_ASSUMPTION_BASED`; JSON + Markdown |
| `fit` | Belluna-Rekonstruktion gegen Adapter | Kollision, Radialspiel, Auflage, Schraubpfade |
| `cfd` | Aerohüllmodell, `snappyHexMesh`, stationäres RANS und Kräfteauswertung | vorläufige Kräfte/Momente; derzeit kein Release-Gate |
| `render` | Standardansichten und Schnitte | PNG + Render-STL |
| `heatmap` | Knotenspannungen und Hotspots aller Lastfälle | PLY, JSON und PNG |
| `manual` | 15 Montageszenen, HTML und PDF | 15 PNGs in 1500×1125, aktueller Hash und exakt 12 A4-Seiten |
| `references` | Belluna-Rekonstruktion als STEP/STL | separates Provenienz-/Dateimanifest |
| `release` | geprüfte Universaldatei + Report + Fit-Summary nach `release/current` | aktueller Quellcommit, Report-SHA256 und Fit-PASS |

`python3 -m pipeline all` führt die Stufen in dieser Reihenfolge aus;
`connections` läuft dabei nicht als eigene Stufe, sondern wird von
`engineering` und `cfd` mit aufgerufen. Die
Heatmap berechnet die Lastfälle bewusst erneut, weil sie rohe Knotenspannungen
benötigt; der Engineering-Report verwendet aggregierte Ergebnisgrößen.
Die Release-Stufe akzeptiert keine Engineering-Dateien aus einem älteren
Commit und verifiziert STEP/STL erneut gegen das Dateimanifest im Report.

## Verzeichnisvertrag

Generierter Inhalt wird nie anhand eines „neuesten“ Dateinamens gesucht,
sondern stets über den Parameter-Hash:

```text
build/
├── engineering/<hash>/
├── analysis/fit/<hash>/
├── analysis/load_paths/<hash>/
├── analysis/cfd/<cfd-hash>/
├── analysis/heatmap/<hash>/
├── render/<hash>/
├── documentation/<hash>/
└── tests/
```

`MAXX150_BUILD_ROOT` kann für CI oder isolierte Versuche gesetzt werden. Der
frühere Ausgabeordner `out/` aus der Zeit vor der Konsolidierung wurde bei der
Repo-Aufräumung entfernt; der `.gitignore`-Eintrag bleibt als Schutz bestehen,
keine aktuelle Pipeline-Stufe liest oder schreibt ihn.

## Werkzeugversionen

Der aktuell geprüfte lokale Stack ist FreeCAD 1.1.1, Blender 5.1, OpenFOAM
v2606 und Google Chrome Headless. `bin/fc` akzeptiert über `FREECAD_BUNDLE`
eine alternative FreeCAD-App. `BLENDER_BIN` überschreibt den Blender-Pfad.
Die CFD-Stufe verwendet den `openfoam`-Wrapper aus `PATH`.

Die Release-Stufe erfasst die tatsächlich vorgefundenen Versionen
maschinenlesbar im `toolchain`-Block von `release/current/manifest.json`
(Manifest-Schema 3) und verweigert die Paketierung, wenn getrackte
Quelldateien uncommittete Änderungen tragen — sonst würde `source_commit`
einen Stand behaupten, dem der Code nicht entspricht. Nicht als Blocker
zählen untracked Dateien sowie die Pfade, die die Pipeline selbst schreibt
(`release/current/`, `references/belluna/models/`), und `messwerte.json`
(Nutzer-Messdaten, die kein Build liest).

## Messwertübernahme

Messwerte werden bewusst nicht automatisch während eines Builds angewendet:

```sh
python3 scripts/apply_measurements.py messwerte.json --dry-run
```

Eine tatsächliche Übernahme verändert `params.py` und erfordert anschließend
mindestens `pipeline test`, `pipeline engineering`, `pipeline fit` und eine
neue Release-Paketierung.

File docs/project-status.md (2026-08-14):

# Projektstatus

Stand: 17.07.2026 · GEOM_REV 10 · Parameterstand `8eb8b79f`

## Abgeschlossen

- Vier rotationsidentische Universal-L-Segmente statt vier Varianten.
- 28-mm-Erhöhung, 400-mm-Öffnung und supportfreie Kammergeometrie.
- Kompakter 500×500-mm-Hybridrahmen mit zwei getrennten 10-mm-Dachraupen
  vollständig über dem 30-mm-Holzrahmen: äußere Raupe geschlossen,
  4-mm-Mittelkanal und acht definierte Entlüftungen an der inneren Raupe.
- 16 längliche Abstandspads mit 2,5×20 mm Kontaktmaß statt 68 Rundnoppen.
  3 mm Dachabstand plus
  0,6-mm-Applikationsführung ergeben 3,6 mm wirksame Raupenhöhe und etwa
  120 ml Nennvolumen; kein Pad greift in die Klebefläche ein.
- Zwei 17-mm-Kammerringe statt eines massiven Außenbands; Universalteil rund
  530 g und 275×250×47 mm im theoretischen CAD-Modell.
- Acht Belluna-Plattenschrauben oben. Unten acht seitliche ST4.2×25 in den
  Holzrahmen als physische, mangels typgeprüftem Schraubgrund nicht
  angerechnete Rückfallebene; die Doppelraupe besteht den Primärnachweis allein.
- Ein M5 je Segmentstoß; sowohl dieser einzelne Bolzen als auch die Epoxidklebung
  bestehen die vollständige konservative 480-N-Stoßhülle getrennt.
- Digital vermessene Belluna-Rekonstruktion mit 397-mm-Unterkragen und
  1,5-mm-Wand; Metallclips und Dichtring als getrennte Referenzteile.
- DFM-, FEM-, analytische, Passungs-, Export- und Referenztests.
- Quellenbasierte Lastpfadabschätzung für Klebungen, obere Schraubengruppe,
  Segmentstöße und das Dachsandwich (`PASS_ASSUMPTION_BASED`).
- Definiertes Kleb-/Dicht-/Lacksystem und reproduzierbarer Montagegenerator.
- Einheitliche Pipeline und geordneter Build-/Release-/Referenzaufbau.
- Reproduzierbarer erster OpenFOAM-Grobfall für die geschlossene Belluna-
  Aerohülle bei 200 km/h; noch kein Freigabe-Gate.
- Deterministischer Toleranz-Sweep der Messkampagnen-Parameter durch alle
  analytischen Gates (`scripts/toleranz_sweep.py`). Kernbefunde: `W_TOP` hat
  beim aktuellen Parameterstand nach unten null Toleranz (50,0 mm liegt exakt
  auf der 2-mm-Mindestbreite der Entwässerungsfase — Messwerte darunter
  erfordern Nachparametrierung); die knappste freigabewirksame Grenzfläche
  (Epoxidstoß bzw. Doppelraupe) bleibt im gesamten Messtoleranzband bei
  77 % Auslastung; im Überlapp-Regime des Haubenfreigangs
  wäre `EDGE_H` ≤ 53 mm gefordert (Schätzwert 55 mm) — B1 entscheidet das
  Regime, B2/B4 dann das Gate.

## Offen vor Produktionsfreigabe

- Reale Fahrzeugmaße `B1a`, `B1b` und `B2` für das Haubenfreigang-Gate.
- Reales Ausschnittmaß und Zustand des Dachkerns bei Heki-Demontage.
- Ausführung und Dokumentation des wasserfesten Holzrahmens.
- Vollständiger Trocken-Fit und Dichtheitstest am Fahrzeug.

## Technische Weiterentwicklung, nicht Freigabeblocker

- FEM-Netzkonvergenz 20/10/5 mm automatisieren.
- Nachgiebige Klebstoff-/GFK-Federbettung statt der derzeit starren,
  flächigen FEM-Lagerung untersuchen.
- Stoßmodell um expliziten Bolzenkontakt und zyklische Lasten erweitern.
- Werkstoff-, Haft- und Sandwichcoupons nur dann nachholen, wenn später reale
  Originalsubstrate und ein sinnvoller Prüfaufbau verfügbar werden; bis dahin
  bleiben sie dokumentierte Modellunsicherheit, kein kurzfristiges Gate.
- CFD-Netzkonvergenz sowie offene Haube, Schräg- und Seitenwind ergänzen.
- Zusammenhängenden Massivquerschnitt als quantitative Warp-Metrik ergänzen.
- Günstige Validierungen ohne Gate-Charakter umsetzen (PLA-Lasttest mit
  Messuhr, Z-Zugstäbe, Dachtemperatur-Logging, Demontage-Haftprobe auf dem
  ausgebauten Dachausschnitt) — Plan und Akzeptanzkriterien in
  [`verification.md`](verification.md).

Historische Tasks, verworfene Materialien und frühere Parameterstände stehen
im [`archive/logbook.md`](archive/logbook.md) und sind nicht mehr normativ.

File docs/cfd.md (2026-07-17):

# CFD-Modell und Windlasten

## Zweck und Status

Die CFD-Stufe schätzt globale Kräfte und Momente auf den Belluna Super Fan.
Sie ergänzt den konservativen analytischen Windlastansatz, ersetzt ihn aber
nicht. Alle Ergebnisse tragen bis zur vollständigen Varianten- und
Konvergenzprüfung den Status `PRELIMINARY_CFD` und `INFORMATIONAL_ONLY`.

```sh
python3 -m pipeline cfd
```

Der Befehl erzeugt die Geometrie und drei Fälle neu, prüft die Oberflächen,
vernetzt mit `snappyHexMesh`, initialisiert mit `potentialFoam`, rechnet
stationär mit `simpleFoam`/k-ω-SST und schreibt je Fall `result.json` sowie
`report.md`. Danach entstehen eine gemeinsame Netzsensitivität und ein
separater, ausdrücklich nicht freigabewirksamer CalculiX-Strukturcheck.

## Geometrie und Provenienz

Quelle ist die maßstäbliche Produktdarstellung auf Seite 10 der
[Belluna-Einbauanleitung](../references/belluna/manuals/belluna-super-fan-installation.pdf):

| Größe | Dokumentierter Wert |
|---|---:|
| Haubenlänge | 593 mm |
| Haubenbreite | 420 mm |
| Montageplatte | 450 mm |
| Höhe geschlossen | 127 mm über Montageebene |
| Höhe vollständig geöffnet | 182 mm über Montageebene |

`reference_models/belluna_aero.py` loftet daraus eine glatte aerodynamische
Hülle. Die Zwischenquerschnitte sind visuell aus Seiten- und Draufsicht
rekonstruiert. Sicken, Antriebe, Schrauben und kleine Radien fehlen bewusst.
Die 28-mm-Plinthe und die 55-mm-Dachkante sind getrennte Oberflächen. Das
Modell ist als `AERODYNAMIC_ENVELOPE_RECONSTRUCTION` gekennzeichnet und kein
Belluna-Hersteller-CAD.

STEP bleibt in Millimetern; die OpenFOAM-STLs werden direkt in Metern
geschrieben. Ein separates Manifest bindet Anleitung, Quellcommit,
Modellklassifikation und SHA-256 aller Geometriedateien.

## Fallmatrix

Die reproduzierbare Matrix enthält:

| Fall | Haube | Nahfeld | Belluna-Oberfläche | Zweck |
|---|---|---:|---:|---|
| `closed_front_coarse` | geschlossen | 2 | 3–4 | Vergleichsbasis |
| `open_front_coarse` | vollständig offen | 2 | 3–4 | Zustandsvergleich |
| `open_front_medium` | vollständig offen | 3 | 4–5 | Netzsensitivität |

Alle Fälle verwenden:

- den jeweils in der Tabelle genannten Haubenzustand und den 28-mm-Adapter,
- 55-mm-Dachkante bei dem noch unbestätigten Abstand aus `params.py`,
- 200 km/h Frontalanströmung,
- Luftdichte 1,2 kg/m³ und kinematische Viskosität 1,5·10⁻⁵ m²/s,
- 5 % Turbulenzintensität und 0,1 m Längenskala,
- stationäres RANS mit k-ω-SST,
- keine Prismenschichten.

Der OpenFOAM-Lauf auf Quellcommit `4a9e437` und die korrigierte
Gesamtbaugruppen-Auswertung auf `59775a0` ergeben Matrix `a3a2de8c`. Die
äußere 500-mm-Aerogeometrie stimmt wieder mit dem aktuellen Hybridadapter
`8eb8b79f` überein. Doppelraupe, Abstandspads, Entlüftungen und seitliche Schraubpfade liegen
im Dachinterface und verändern die umströmte Hülle nicht. Der nachgeschaltete
CalculiX-Strukturcheck wurde für `8eb8b79f` neu gerechnet. Unabhängig davon
bleibt nur die analytische 480-N-Hülle freigabewirksam. Die Tabelle summiert
jeweils **Belluna plus direkt angeströmte Adapteroberfläche**; alle Momente
sind auf die Mitte der Adapterbasis `(0, 0, 0)` transformiert. Gemittelt werden
die letzten 20 Kraftausgaben (100 Solveriterationen):

| Fall | CFD-Hash | Zellen | Fx [N] | Fy [N] | Fz [N] | My [Nm] | Widerstands-CoV |
|---|---|---:|---:|---:|---:|---:|---:|
| geschlossen, grob | `826d6dae` | 148.448 | 30,92 | 0,03 | 167,74 | +9,99 | 0,01 % |
| offen, grob | `656cdb1a` | 204.572 | 51,67 | 2,50 | 178,62 | −1,02 | 0,95 % |
| offen, mittel | `6840c107` | 1.001.494 | 42,42 | 1,14 | 187,19 | −0,17 | 0,74 % |

Das um Faktor 4,90 größere offene Mittelnetz ändert den Widerstand gegenüber
dem Grobnetz noch um 21,8 % und den Auftrieb um 4,6 %. Das Basismoment `My`
wandert von −1,02 auf −0,17 Nm; seine große relative Änderung ist wegen der
Nähe zu null kein sinnvoller Konvergenzmaßstab. `Fy`, `Mx` und `Mz` sind bei
der symmetrischen Frontalanströmung ebenfalls klein. Die Hauptkomponenten
zeigen: Der Auftrieb ist vergleichsweise stabiler, der Widerstand noch nicht.

Keines der Netze besteht alle `checkMesh`-Prüfungen. Das offene Mittelnetz
senkt den Anteil konkaver Cut-Cells von 3,22 % auf 2,73 %, enthält aber 16
stark verzerrte Flächen und eine Zelle knapp unter dem Determinantenlimit.
Außerdem erreicht der stationäre Mittelnetzlauf bei Iteration 500 nicht alle
gesetzten Residualziele; die offene Ablöseströmung bleibt leicht
oszillierend. Globale Kraftgrößen sind damit als Vorabschätzung brauchbar,
lokale Druckspitzen oder Strömungsdetails nicht.

## Lastübergabe an CalculiX

Nur `open_front_medium` wird mit dem Modellfaktor 1,5 in einen zusätzlichen
kombinierten Rahmenlastfall übergeben. Die drei Kraftkomponenten wirken auf
der Adapter-Deckfläche; das Nickmoment `My` wird als vertikales Kräftepaar an
Front- und Heckaußenwand eingeleitet. `Mx` und `Mz` werden ausgewiesen, aber
noch nicht in das bestehende Selektormodell übertragen.

Die aktuelle Strukturkopplung enthält zusätzlich mittlere
Spannungsindikatoren für die Doppelraupe, den konservativen analytischen
Segmentstoßnachweis und eine ideale Gleichverteilung auf acht
Belluna-Schrauben. Die acht unteren Seitenschrauben werden auch hier bewusst
nicht als Tragfähigkeit angerechnet.

Der Lauf `a3a2de8c` übergibt nach Faktor 1,5:

| Komponente | Übergebene Last | Vergleich | Einordnung |
|---|---:|---:|---|
| horizontal, resultierend | 63,65 N | 480 N LF1-Hülle | 13,3 % |
| Auftrieb +z | 280,79 N | 255,06 N LF2-Vertikalbetrag | 110,1 %; Gegenrichtung, daher nicht als durch LF2 abgedeckt behauptet |
| Nickmoment `My` um Basis | −0,251 Nm | 88,8 Nm LF1-Hülle | 0,3 % |
| Roll-/Giermoment um Basis | 0,110 / 0,320 Nm | — | ausgewiesen; äquivalentes `Mx/Mz` im CalculiX-Fall nicht eingeleitet |

Der kombinierte Produktionsnetz-FEM-Fall ergibt 0,093 MPa von Mises bei
11,25 MPa Kurzzeitzulässigkeit und 0,0011 mm Deckflächenverformung bei
0,5 mm Grenzwert. Das ist nur 0,8 % Spannungs- und 0,22 %
Verformungsauslastung im idealisierten monolithischen Rahmenmodell.
Die Fixierung liegt verteilt auf den Böden beider Kleberführungen; die 16
Abstandspads werden nicht als Lager benutzt. Klebstoff- und Dachnachgiebigkeit
sind dadurch weiterhin nicht abgebildet.

Lastpfad-Indikatoren nach Modellfaktor:

- Doppelraupe 33.313 mm²: 0,00191 MPa mittlere Schubspannung und
  0,00843 MPa mittlere Zugspannung. Maßgebend bleiben die strengeren
  0,050/0,030-MPa-Projektwerte unter der analytischen 480-N-Hülle.
- Konservativ ein einzelner Segmentstoß unter der vollen Horizontallast:
  0,0509/5,625 MPa Schub und 0,926/11,25 MPa Lochleibung mit einem M5.
- Ideale Verteilung der Auftriebslast auf acht Belluna-Schrauben: 35,1 N je
  Schraube gegenüber 178 N qualifizierter Kapazität (356-N-Auszugreferenz ×
  Detailfaktor 0,5, s. [Lastpfade](load-paths.md)).
- Die zwei 10-mm-Raupen sind der allein angerechnete Adapter-Dach-Primärpfad.
  Acht seitliche ST4.2×25 sind physisch vorhanden, bleiben mangels geprüfter
  Holz-/GFK-/Gewindetragfähigkeit jedoch unbewertete Reserve. Der vollständige
  annahmenbasierte Nachweis steht in [Lastpfade](load-paths.md).

Die kleine Rahmenauslastung bedeutet deshalb nicht, dass die Gesamtmontage
mit demselben Sicherheitsfaktor freigegeben wäre. Die derzeit plausibel
schwächeren beziehungsweise unsichereren Glieder sind Haftung des gewählten
Dichtstoffs auf den lackfrei gehaltenen Kunststoff- und X150-GFK-Zonen, der nachgerüstete Holzrahmen, das lokale
GFK-Dach und die reale Lastverteilung in der Doppelraupe. Die bestehende
480-N-Horizontallast bleibt unverändert freigabewirksam.

## Nächste Gates

Vor einer **freigabewirksamen** Kopplung in die FEM sind mindestens
erforderlich:

1. Feinnetz ergänzen und Grob-/Mittel-/Feinnetz-Konvergenz für Kräfte und
   Momente bewerten.
2. Verbesserung oder begründete Akzeptanz der konkaven Cut-Cells.
3. Geschlossene und vollständig geöffnete Haube.
4. Frontal-, Heck-, ±30°- und 90°-Anströmung.
5. Sensitivität für Dachkantenabstand und vorgeschaltete Grenzschicht.
6. Plausibilisierung gegen eine einfache Kraft- oder Druckmessung.

Erst danach darf eine Lastkomponente freigabewirksam an CalculiX übergeben
werden; die bestehende automatische Übergabe des open_front_medium-Falls
bleibt bis dahin INFORMATIONAL_ONLY. Komponentenweise gilt mindestens die
bestehende analytische Hülllast; CFD darf sie nur erhöhen, nicht reduzieren.

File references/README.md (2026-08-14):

# Referenzen

Dieser Ordner enthält unveränderte Herstellerunterlagen, nachvollziehbare
Quellenprotokolle, Fahrzeugreferenzen und die projektseitige
Belluna-Rekonstruktion. Er ist **keine** Ablage für generierte
Projektartefakte; diese liegen unter `build/` beziehungsweise
`release/current/`.

## Klassifikation

- `belluna/manuals/`: unveränderte Belluna-Einbauanleitung.
- `belluna/models/`: aus Fotos und Messwerten rekonstruierte STEP-/STL-Modelle.
  Sie sind kein Hersteller-CAD. Erzeugung: `python3 -m pipeline references`.
- `vehicle/`: vom Fahrzeughalter bereitgestellte Referenzbilder.
- `datasheets/adhesives/`: eingesetzte oder qualifizierte Kleb-/Dichtstoffe.
  Wenn eine bereitgestellte Binärdatei nicht im Repo liegt, hält ein
  Quellenprotokoll Originalname, SHA-256 und die verwendeten Kennwerte fest.
- `datasheets/adhesives/evaluated-not-selected/`: bewertete, bewusst nicht
  gewählte sowie abgelöste Produkte. Der Status `evaluated_field_failure`
  kennzeichnet dabei ein Produkt, das nicht am Schreibtisch, sondern erst am
  realen Bauteil ausgeschieden ist.
- `datasheets/process/`: eingefrorene Hersteller-Prozessgrundlagen für
  Vorbehandlung, Aushärtung und Fugenbearbeitung.
- `datasheets/coatings/`: Primer und Decklack.
- `datasheets/materials/`: Materialherkunft und Herstellerlinks.

`catalog.json` dokumentiert Quelle, Projektstatus und SHA-256 der statischen
Dateien. Der Test `test_reference_catalog.py` schützt die Ablage gegen stille
Änderungen oder fehlende Unterlagen.

## Produktstatus

| Funktion | Produkt | Status |
|---|---|---|
| Segmentstöße | UHU plus endfest 300, 2K-Epoxid | ausgewählt; rechnerisch auf 0,50 MPa abgemindert (Faktor 33) |
| Segmentstöße | WEICON RK-1300 | am realen Bauteil gescheitert, 2026-08-14 durch UHU plus endfest 300 ersetzt |
| Dach/Belluna | Sikaflex-522 weiß | Standardweg; 0,030 MPa normal / 0,050 MPa Schub, Vorbehandlung namentlich dokumentiert |
| Äußere Schutzkehle | Sika Abglättmittel N | ausgewähltes, wasserbasiertes Sika-Glättmittel; Verträglichkeit am ausgehärteten Originallack vorprüfen |
| Dach/Belluna | Carloflex 410 UV weiß | Belluna-konforme Alternative mit denselben Projektgrenzwerten; erst einsetzen, wenn der im TDS nicht benannte Kunststoffprimer prozesssicher festgelegt ist |
| Holz/GFK/XPS | SikaForce-710 L35 + SikaForce-010 | ausgewählt; professioneller Misch-/Pressprozess |
| Segmentstöße | WEICON Epoxyd-Minutenkleber | bewertet, nicht gewählt; Tg 44,7 °C liegt unter `T_MAX`. Auch als 2K-Epoxid kein Ersatz für das ausgewählte UHU-Produkt |
| Dach/Belluna | Sikaflex-521 UV | bewertet, durch 522 abgelöst |
| Lackaufbau | Mipa Plastic-Grundierfiller + PUR HS | ausgewählt; Klebezonen bleiben lackfrei |

Sicherheitsdatenblätter werden wegen ihrer häufigeren Aktualisierung nicht als
eingefrorene Kopien gepflegt. Vor Verarbeitung ist stets die aktuelle Fassung
vom Hersteller abzurufen.

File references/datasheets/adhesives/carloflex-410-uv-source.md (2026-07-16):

# Carloflex 410 UV — Herstellerdatenblatt, Quellenprotokoll

Das zweitseitige technische Datenblatt wurde am 2026-07-16 vom Nutzer
bereitgestellt:

`/Users/jihlenburg/Downloads/40427 _ 40447 _ 40457 Carloflex - Carlofon.pdf`

- Hersteller: Carlofon GmbH
- Produkt: Carloflex 410 UV
- Artikelnummern: 40427, 40447, 40457
- SHA-256 des unveränderten PDFs:
  `b4dbd8213e0b37fe69204cb2b18fde1ef4012a4b50a6dd25a6b8006b5342a2a5`
- Dateigröße: 82.072 Byte

## Für das Projekt relevante Herstellerangaben

- 1K-Polyurethan-Dicht- und Klebmasse; grau, weiß oder schwarz.
- Gute UV-Stabilität, elastisch, feuchtigkeitshärtend.
- Anwendung unter anderem in Bus-, LKW-, Caravan- und Schiffbau.
- Genannte Untergründe: grundierte/lackierte Metalle, Hartplastik (GFK,
  Hart-PVC), Holz und Glas. Bei schwierigen Untergründen wird ein Haftungstest
  empfohlen; Spezialprimer für Kunststoff, Zink/Aluminium, Holz und Glas
  werden erwähnt, im Datenblatt aber nicht mit Produktnamen bezeichnet.
- Verarbeitung +5 bis +35 °C; Temperaturbelastung −40 bis +90 °C,
  kurzzeitig bis +120 °C.
- Hautbildung etwa 35–45 min; Durchhärtung 2,5–3 mm je 24 h bei
  23 °C / 50 % r. F.
- Shore A 45–50; Zugfestigkeit nach DIN 53504 >1,8 N/mm²;
  Dehnung >450 %; E-Modul bei 100 % Dehnung etwa 1,0 N/mm² nach 24 h.
- Beständig gegen Wasser, Seewasser, verdünnte Säuren/Laugen und wässrige
  Reiniger; kurzzeitig gegen Benzin, Fett und Mineralöl.

Diese Datei ist ein Projekt-Quellenprotokoll, nicht das originale
Hersteller-PDF. Für Verarbeitung und Sicherheit gilt das bereitgestellte
Original zusammen mit dem aktuellen Sicherheitsdatenblatt.

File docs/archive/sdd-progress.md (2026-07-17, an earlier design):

# SDD Progress Ledger — Belluna-Adapter-Pipeline
Plan: docs/superpowers/plans/2026-07-12-belluna-adapter-pipeline.md
Branch: main (User-Freigabe), Commits lokal pauschal freigegeben, NIEMALS push.

BASE Task 1: b7ca595
Task 1: complete (b7ca595..370dddd, review clean). Minors fürs Finalreview: run_tests.py ohne __main__-Guard (plan-mandated); Luftdichte 1.2 als Magic Number in wind_force; kein Immutability-Test für Params.
BASE Task 2: 370dddd
PENDING nach Task 2: Parameter-Amendment aus MaxxFan-Deluxe-Maßblatt (User-Upload): A_HOOD 0.10->0.108, HOOD_TIP_REACH 130->179, Windlast 444.4->488.9 N (test_windlast + Plan-Global-Constraints + Spec §6 LF1 anpassen). Zeichnungsdaten: 586 lang, 408 breit, 132 zu, 236 offen, Überstand offen 179 (123 bis Knick).
Task 2: complete (370dddd..0f23773, review clean, Reviewer bestätigte echten ccx-Lauf). Minors fürs Finalreview: closeDocument ohne try/finally im Toolchain-Test; fea.run()-Rückgabewert ungeprüft.
Amendment-Commit danach: MaxxFan-Maßblatt (A_HOOD 0.108, TIP_REACH 179, Wind 480 N) — Ledger-PENDING erledigt.
BASE Task 3: b47d4a8
Task 3: complete (b47d4a8..d601e67, Fix-Loop: Off-by-One rect_path_points [plan-geerbt] + Testlücke behoben, Re-Review Approved). Minors fürs Finalreview: mutable default origin in rounded_box; Docstrings rounded_box/_vertical_edges fehlen; isValid nur in einem Test; kein spacing-Guard.
BASE Task 4: d601e67
Task 4: complete (d601e67..4524460 + Plan-Sync, review Approved). Planfehler behoben: scharfer Öffnungs-Prüfkörper vs. R5-Fillets (jetzt R5.5-Probe), XLen->XLength (auch Task-6-Plantext vorab gefixt). Minors fürs Finalreview: test_deckflaeche-Schwelle 60000 nur 0.4% unter Istwert (fragil bei Parameteränderung).
BASE Task 5: siehe git log (Plan-Sync-Commit)
M5-Amendment-Commit 9c26a25 (JOINT_BOLT_D 5.5, CB 10.0/5.0, NUT 8.0/4.0) — Lochleibung mit 480 N sonst FAIL.
BASE Task 5: 9c26a25
Task 5: complete (9c26a25..f5c4e93, review Approved, Istwerte bestätigt: u=0.387, tau=0.384, Lochleibung=6.98, Auszug=266N). Minors fürs Finalreview: import math in Funktion; sig_lang ungenutzt in joint_checks; M4-Kommentar veraltet (ist M5); 130mm-Kommentar veraltet (ist 179); Auszugstest prüft nur Schwelle nicht Sollwert.
BASE Task 6: f5c4e93
Task 6: complete (f5c4e93..b9c2228, review Approved; Implementer fixte 2 Plan-Geometriebugs: lap_cut-Toleranz, Achsen-Noppen-Split; Reviewer verifizierte beide numerisch). Minors fürs Finalreview: kein isValid-Guard nach Bolzen-Cuts in build_segments; Asymmetrie-Behauptung im Docstring ungetestet; kein Kollisionstest Bolzen/Rille.
Doku-Amendment: Dichtheitskonzept in Spec §4 + Montagenotiz (Commit siehe git log).
BASE Task 7: b9c2228+Doku-Commit (git log)
Task 7: complete (c1d41ec..5d0ffa3, Fix-Loop: 4. Brückenzone Stoßstufe dokumentiert+eingerechnet [35581.86], _facet_area getestet, Import bereinigt; Re-Review Approved). Minors fürs Finalreview: Begriff Brücke vs Kragarm in dfm-Docstring; LinearDeflection-Kommentar; band=min(W_TOP) global konservativ.
BASE Task 14 (Rippenkammern): 87d8b71
Task 14: complete (87d8b71..79dadf3, review Approved; Volumenbilanz exakt reproduziert, 48 Kammern/24 Slots). WICHTIG für Task 8: INFILL_FACTOR/E_BASE erst dort verdrahten+prüfen (Reviewer-Befund: aktuell Leerlauf). Rename-Fix chamber_cell_count->chamber_slot_count folgt. Minors fürs Finalreview: side_half min() global; _rot dupliziert (frame/segments); Zwischen-Guards nur nach Kammern; DFM-Vent-Formel konservativ; kein Guard in _chamber_profile_face.
Rename-Fix committet; volle Suite 29/29 (Laufzeit jetzt einige Minuten wegen Kammer-Booleans).
BASE Task 8: siehe git log (Rename-Commit)
Task 8: complete (68a9e77..e25db91, Fix-Loop: Critical Face-Selektor-Kontamination + couple-Magic-Number behoben, Re-Review Approved mit Live-Reproduktion). Minors fürs Finalreview: LF1-Moment ~12-15% konservativ doppelt angesetzt; Testlücke Asymmetrie W_TOP (Vertauschung unentdeckbar bei symmetrischen Defaults); build_frame min()-Kammerraster blockiert asymmetrische Livetests.
BASE Task 9: e25db91
Task 9: implementiert (183e1c9), Review läuft. Erste FEM-Istwerte LF4 Grobnetz: vm 0.177 MPa (2% von 8.4), defl 0.87 µm, 85k Knoten, 17.7 s. Root-Cause-Fixes des Implementers: SecondOrderLinear=True (Jacobian an Kleinradien), FemMesh.Nodes-Hebung (O(n²)-Property-Falle — erklärt früheren Hänger).
Task 9: complete (e25db91..183e1c9, review Approved, Plausibilität bestätigt). AUFTRAG an Task 13: am 10-mm-Produktionsnetz prüfen ob SecondOrderLinear=True noch nötig (Reviewer-Important). Minors fürs Finalreview: _ensure_binary_paths dupliziert (toolchain-Test/run_fem); Magic 0.5 z-Toleranz defl_top.
BASE Task 10: 183e1c9
Task 10: complete (183e1c9..0e488bd, review Approved; Reviewer korrigierte Handrechnungs-Hebelarm auf lap_h/2, FEM 3.37-3.40 MPa plausibel). Minors fürs Finalreview: defl_top-Fallback semantisch irreführend im Submodell; Face-Filter-Duplikat.
BASE Task 11: siehe git log (Plan-Task-11-Commit)
Task 11: complete (9016d2a..a44ad4b, review Approved). Minor fürs Finalreview: PASS-Berechnungs-Asymmetrie in analytic.py-API (2 Checks ohne PASS-Feld).
BASE Task 12: a44ad4b
Task 12: complete (a44ad4b..6b87954, review Approved). Minors fürs Finalreview: M5x31 auf Normlänge runden; Teststrings PFLICHT/ISO-20653/Kernloch/M5 ungeprüft; Testreihenfolge-Abhängigkeit export; GLUE_GAP-Format; list[Path]-Annotation; encoding utf-8.
BASE Task 13: 6b87954
Task 13: complete (6b87954..9f5bd47, review Approved). Produktionslauf: LF1 0.85, LF2 0.44, LF3 2.13/3.36 (engster Fall, Dauerlast), LF4 0.18, Stoß 3.37; 128 s; PASS mit Vorbehalt (Freigang). Minors fürs Finalreview: Netz-Nichtdeterminismus vs. Netzkonvergenz im Wording vermischt; Banner-Erkennung textbasiert; Grobnetz-Referenzlog nicht archiviert.
ALLE 14 TASKS COMPLETE. Finales Whole-Branch-Review folgt.
Final-Review-Fixes complete (dc9364d: validate-Gate + M5-Kommentare + Normlänge M5x35). Doku b252c12/f7b0504. Herstellbarkeits-Pflichtblock in Montagenotiz (dieser Commit), Ledger-36-Strings erledigt. Suite 45/45.
BASE Task 15: 7524cda (Vor-Messkampagnen-Paket, User-Auftrag)
Task 15: complete (7524cda..138e82e inkl. Critical-Fix Achsen-Fehlbezug [aus Controller-Brief geerbt!], Re-Review Approved mit unabhängiger Skript-Verifikation). Hash neu 88bacca5, LF-Werte: 0.79/0.43/2.24/0.19, Stoß 3.37. Bonus-Fix: nopple_faces Planaritätscheck (latenter Bug durch Kegel aufgedeckt). Minors fürs nächste Review: Herleitungs-Redundanz 6-fach; P_ASYM ohne _side_neighbor_bounds-Unit-Check; logbook.md-Doku-Ungenauigkeit.
Task 18: complete (138e82e..d348e91, review Approved). 16 Artefakte: render/-Paket, fem/heatmap.py, scripts/messkampagne.py+JSON, 3 Skills, CLAUDE.md. Minors: run_capture-Duplikat (M1-Familie); pipefail fehlt in scripts/*.sh; blender-Pfad hart; _SIMPLE-Kommentar.
BASE Task 17: d348e91
Task 17: complete (d348e91..ff14e9a inkl. Critical-Fix Referenzradius/Keepout, Re-Review Approved, Anker live Δ0). Eckkammern CORNER_CHAMBERS default False, Delta EIN 41247.58 mm³. Minors: Report §2.3/§3 (gitignored) veraltet ohne Verweis; Konsistenztest slot_count für CORNER_CHAMBERS+CELL_L-Filter fehlt → Task 16.
BASE Task 16: ff14e9a
Task 16: complete (ff14e9a..32e0a6c, review Approved; 4 begründete Abweichungen bestätigt, Anker bitidentisch). Minors: manifest liest GEOM_REV von PRM.P statt p; doppeltes load_results (vorbestehend). VOR-MESSKAMPAGNEN-PAKET KOMPLETT: Tasks 15-18 + Fixes, 75/75 Tests, Hash da0d8553.
Task 19: complete (32e0a6c..2fb2a3d + Doku-Drift-Fix, review Approved; Zahlenkette unabhängig bestätigt). Material-Default = Bambu ASA-CF, Hash 5f063cc3, Auslastungen LF1 5.9/LF2 3.0/LF3 41.7/LF4 1.4/Stoß 25.0 %, Fuge 21 %. Offen: CTE-Herstelleranfrage (todo).
Task 20: complete (3be4b64..b3123da, review Approved, alle Zahlen unabhängig verifiziert). Eckkammern Default EIN, Hash 5ba1ea4b, LF3 42.1 %, Segment 430.7 g. AUS-Variante beweisbar == 5f063cc3. Minors: 4·slots+16 dreifach dupliziert; DFM-Seg-Asymmetrie (8972 vs 8959) unkommentiert (Mesh-Rauschen).
OFFEN: Materialfrage Bambu-NRND (User entscheidet: Bambu-Restbestand / Fiberon ASA-CF08 / Extrudr ASA-GF+Coupons).
Task 21: complete (b3123da..26dec46, review Approved). Material-Default = Würth ASA GF15 weiß RAL 9003, Hash 12ffab2a, Annahmenkette dokumentiert (E 3000/σ 45 ANNAHME, Z 0.5 GESCHÄTZT, CTE 60e-6 Obergrenze), zulässig 4.50/11.25, LF3 50.0 %, Segment 464.5 g (4x750g-Spulen). Geometrie SHA256-identisch zu 5ba1ea4b. Offen: Würth/OEM-Anfrage gedruckte Kennwerte XY+Z+CTE (todo).

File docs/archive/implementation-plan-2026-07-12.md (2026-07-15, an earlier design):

# Belluna-Adapterrahmen: Parametrische FreeCAD+FEM-Pipeline — Implementierungsplan

> **Archiv:** Dieser Implementierungsplan beschreibt den Aufbau vom 12.07.2026
> und enthält bewusst alte Pfade, Produkte und Zwischenstände. Er ist nicht
> normativ. Aktuell gelten `README.md`, `docs/design.md` und `docs/pipeline.md`.

> **For agentic workers:** REQUIRED SUB-SKILL: Use superpowers:subagent-driven-development (recommended) or superpowers:executing-plans to implement this plan task-by-task. Steps use checkbox (`- [ ]`) syntax for tracking.

**Goal:** Vollständig skriptierte Pipeline, die den 28-mm-Adapterrahmen für den Belluna Super Fan
parametrisch erzeugt, per CalculiX-FEM verifiziert und als Drucksegmente (STEP/STL/3MF) samt
Montagenotiz exportiert.

**Architecture:** Headless FreeCAD (`freecadcmd`) führt reine Python-Module aus: `params.py` →
`model/` (B-Rep-Geometrie) → `fem/` (Gmsh-Mesh, CalculiX, Analytik) → `export/` (Druckdateien,
Report). Eigener minimaler Testrunner (kein pytest im FreeCAD-Python). Spec:
`docs/superpowers/specs/2026-07-12-belluna-adapter-design.md`.

**Tech Stack:** FreeCAD 1.1.1 (Part, ObjectsFem, femmesh.gmshtools, femtools.ccxtools, MeshPart),
gebündeltes `ccx` und `gmsh`, Python 3.11 (FreeCAD-intern).

## Global Constraints

- FreeCAD headless: `/Applications/FreeCAD.app/Contents/Resources/bin/freecadcmd` (verifiziert: Version 1.1.1; `ccx` und `gmsh` im Bundle unter `Contents/Resources/bin/`; **kein** Netgen-Python-Modul → Vernetzung ausschließlich Gmsh).
- Alle Ausführungen über den Wrapper `bin/fc` (Task 1). Tests: `bin/fc tests/run_tests.py`; Einzelfilter über Umgebungsvariable `TEST_FILTER=<substring>`.
- Einheiten: mm, N, MPa, °C. Koordinaten: Öffnung zentriert um (0,0); +x = Fahrtrichtung hinten (heckseitig); z=0 = Unterkante des Rahmenkörpers; Klebenoppen ragen bis z=−`GLUE_GAP`; Deckfläche bei z=`H_RAISE`−`GLUE_GAP`.
- Kennzahlen aus der Spec (müssen in Tests exakt so herauskommen): effektive Wandstärke 35+28=63 mm → 140er-Welle; Windlast 200 km/h → **480 N** (A_HOOD 0,108 m² aus MaxxFan-Deluxe-Maßblatt, mit SF 2; Amendment nach Task 2); Zulässigkeiten ASA bei 85 °C: 3,36 MPa dauerhaft / 8,4 MPa kurzzeitig (Kette 40 × 0,35 × 0,6 [× 0,4]).
- Keine externen Python-Pakete (kein pip, kein pytest) — nur FreeCAD-Bundle-Module + Stdlib.
- **Git: NIEMALS automatisch committen.** Globale User-Regel, überschreibt jede Skill-Vorgabe. Jeder Task endet mit „Checkpoint": Ergebnis melden, Commit-Freigabe des Users abwarten (Vorschlag für Commit-Message angeben).
- `out/` ist gitignored (generierte Artefakte).
- Zwischen `AskUserQuestion`-tauglichen Entscheidungen und Defaults: Defaults aus `params.py` verwenden, niemals blockieren — Messkampagnen-Werte ersetzt der User später selbst.

---

### Task 1: Projektgerüst, Parameter, Testrunner

**Files:**
- Create: `bin/fc`, `.gitignore`, `params.py`, `tests/run_tests.py`, `tests/test_params.py`

**Interfaces:**
- Produces: `params.Params` (frozen dataclass), Modul-Konstante `params.P`, Funktionen
  `effective_wall(p) -> float`, `select_shaft(p) -> float`, `outer_dims(p) -> (float, float)`,
  `wind_force(p) -> float`, `allowables(p) -> (float, float)`, `params_hash(p) -> str`.
  Alle späteren Tasks importieren `params` als `import params as PRM`.

- [ ] **Step 1: Wrapper + gitignore anlegen**

`bin/fc`:
```sh
#!/bin/sh
exec /Applications/FreeCAD.app/Contents/Resources/bin/freecadcmd "$@"
```

`.gitignore`:
```
out/
__pycache__/
*.FCStd1
```

Dann: `chmod +x bin/fc`

- [ ] **Step 2: Failing Test schreiben**

`tests/run_tests.py`:
```python
"""Minimaler Testrunner für freecadcmd (kein pytest im FreeCAD-Python).
Aufruf:  bin/fc tests/run_tests.py          — alle Tests
         TEST_FILTER=params bin/fc tests/run_tests.py — nur Dateien mit 'params'."""
import importlib.util
import os
import sys
import traceback
from pathlib import Path

ROOT = Path(__file__).resolve().parent.parent
sys.path.insert(0, str(ROOT))

def main():
    flt = os.environ.get("TEST_FILTER", "")
    passed, failed = 0, 0
    for tf in sorted((ROOT / "tests").glob("test_*.py")):
        if flt and flt not in tf.name:
            continue
        spec = importlib.util.spec_from_file_location(tf.stem, tf)
        mod = importlib.util.module_from_spec(spec)
        try:
            spec.loader.exec_module(mod)
        except Exception:
            print(f"LADEFEHLER {tf.name}")
            traceback.print_exc()
            failed += 1
            continue
        for name in sorted(dir(mod)):
            if name.startswith("test_") and callable(getattr(mod, name)):
                try:
                    getattr(mod, name)()
                    print(f"PASS {tf.stem}.{name}")
                    passed += 1
                except Exception:
                    print(f"FAIL {tf.stem}.{name}")
                    traceback.print_exc()
                    failed += 1
    print(f"\n{passed} bestanden, {failed} fehlgeschlagen")
    sys.exit(1 if failed else 0)

main()
```

`tests/test_params.py`:
```python
import params as PRM

def test_effective_wall_und_wellenwahl():
    assert PRM.effective_wall() == 63.0          # 35 Dach + 28 Adapter
    assert PRM.select_shaft() == 140.0           # Bereich 48-67 mm

def test_wellenwahl_grenzen():
    p = PRM.Params(ROOF_T=19.0)                  # 19+28=47 -> 120er (Obergrenze)
    assert PRM.select_shaft(p) == 120.0
    p = PRM.Params(ROOF_T=55.0)                  # 55+28=83 -> außerhalb
    try:
        PRM.select_shaft(p)
        assert False, "erwartete ValueError"
    except ValueError:
        pass

def test_windlast():
    assert abs(PRM.wind_force() - 444.4) < 1.0   # 200 km/h, cd 1.2, A 0.1, SF 2

def test_zulaessigkeiten():
    lang, kurz = PRM.allowables()
    assert abs(lang - 3.36) < 0.01               # 40*0.35*0.6*0.4
    assert abs(kurz - 8.40) < 0.01               # 40*0.35*0.6

def test_aussenmasse_und_hash():
    L, W = PRM.outer_dims()
    assert L == 500.0 and W == 500.0
    h1 = PRM.params_hash()
    h2 = PRM.params_hash(PRM.Params(H_RAISE=30.0))
    assert len(h1) == 8 and h1 != h2
```

- [ ] **Step 3: Test laufen lassen — muss fehlschlagen**

Run: `bin/fc tests/run_tests.py`
Expected: `LADEFEHLER test_params.py` (ModuleNotFoundError: params), Exit-Code 1.

- [ ] **Step 4: params.py implementieren**

`params.py`:
```python
"""Zentrale Parameterdatei — einzige Quelle der Wahrheit.
Längen mm, Kräfte N, Spannungen MPa, Temperaturen °C.
Quellen: Belluna-Anleitung (22 S.), Challenger-Dachdiagramm (35 mm X-Modelle),
Spec docs/superpowers/specs/2026-07-12-belluna-adapter-design.md.
Mit 'Messkampagne N' markierte Defaults sind Schätzwerte, die der User
per Messschieber ersetzt (Spec §8)."""
import hashlib
from dataclasses import dataclass, asdict

@dataclass(frozen=True)
class Params:
    # --- Dachausschnitt / Fahrzeug ---
    CUTOUT_W: float = 400.0      # Sollmaß Ausschnitt (Anleitung, Messkampagne 6)
    CUTOUT_R: float = 5.0        # Eckenradius R5
    ROOF_T: float = 35.0         # Dachstärke X-Modelle (Messkampagne 8)
    EDGE_DIST: float = 250.0     # Ausschnitt-Hinterkante -> Dachkante (Messkampagne 7)
    EDGE_H: float = 55.0         # Höhe Dachkante über Dachebene (Messkampagne 7)
    # --- Haubengeometrie für Freigang-Check (Messkampagne 7) ---
    HOOD_TIP_REACH: float = 130.0   # horizontaler Haubenüberstand über Ausschnitt-Hinterkante
    HOOD_UNDERSIDE_H: float = 30.0  # Haubenunterkante am Überstand über Plattensitz
    CLEAR_MIN: float = 5.0          # geforderter Freigang
    H_CG: float = 160.0             # Angriffshöhe Windlast über Deckfläche
    # --- Erhöhung / Klebefuge ---
    H_RAISE: float = 28.0        # Zielerhöhung inkl. Klebespalt
    GLUE_GAP: float = 3.0        # Elastikfuge unten = Noppenhöhe (Thermik!)
    GLUE_SHEAR_CAP: float = 0.5  # zulässige Schubverzerrung der Fuge (50 %, Sika-Klasse)
    T_CURE: float = 20.0         # Verklebetemperatur
    # --- Deckflächenbreiten je Seite (Messkampagne 1/2) ---
    W_TOP_FRONT: float = 50.0
    W_TOP_REAR: float = 50.0
    W_TOP_LEFT: float = 50.0
    W_TOP_RIGHT: float = 50.0
    R_OUT: float = 12.0          # Außeneckenradius
    # --- Freistellung Gussets oben innen (Messkampagne 4) ---
    REC_GUSSET_W: float = 18.0
    REC_GUSSET_D: float = 3.0
    # --- Unterseite: Kleberille + Noppen ---
    GROOVE_OFF: float = 15.0     # Rillenbeginn ab Öffnungskante
    GROOVE_W: float = 8.0
    GROOVE_D: float = 2.0
    NOPPLE_R: float = 4.0
    NOPPLE_SPACING: float = 60.0
    CHAMFER_OUT: float = 4.0     # Fase Außenkante unten (Sika-Kehle)
    # --- Segmentierung ---
    N_SEGMENTS: int = 4          # nur 4 unterstützt (Quadranten)
    LAP_L: float = 25.0          # Halbüberlappung am Stoß
    TOL_JOINT: float = 0.25      # Passungsluft je Fügefläche
    JOINT_BOLT_D: float = 4.5    # M4-Durchgang
    JOINT_BOLT_OFF: float = 35.0 # Bolzenlage ab Öffnungskante (kollidiert nicht mit Rille)
    JOINT_CB_D: float = 8.5     # Zylindersenkung Kopf (DIN912 M4)
    JOINT_CB_T: float = 4.5
    JOINT_NUT_AF: float = 7.4    # Sechskant-Schlüsselweite Muttertasche
    JOINT_NUT_T: float = 3.5
    SEG_MAX_BBOX: float = 300.0  # zulässige Segment-Boundingbox (Druckservice)
    # --- Lüfter / Lasten (Spec §3/§6) ---
    FAN_MASS: float = 6.5        # kg (Maxxfan-Hüllkurve; Belluna 5.0)
    V_DESIGN_KMH: float = 200.0  # 160 Reise + Böenreserve
    CD_HOOD: float = 1.2
    A_HOOD: float = 0.10         # m² projiziert, Haube offen
    SF_WIND: float = 2.0
    G_VERT: float = 4.0          # Schlechtweg vertikal
    G_LAT: float = 2.0           # Schlechtweg quer
    CLAMP_FORCE: float = 2400.0  # 4 x 600 N aus 0,7 Nm (Anleitung), konservativ
    SNOW_LOAD: float = 200.0     # N auf Grundfläche
    T_MIN: float = -20.0
    T_MAX: float = 85.0
    # --- Material ASA (23 °C Basiswerte) + Abminderung (Spec §6) ---
    E_BASE: float = 2000.0
    SIGMA_BASE: float = 40.0
    NU: float = 0.35
    RHO: float = 1070.0          # kg/m^3
    CTE_ASA: float = 90e-6       # 1/K
    CTE_ROOF: float = 25e-6      # 1/K (GFK)
    DERATE_TEMP: float = 0.35    # bei 85 °C
    DERATE_Z: float = 0.6        # FDM-Schichthaftung
    DERATE_CREEP: float = 0.4    # Dauerlast
    INFILL_FACTOR: float = 0.5   # Homogenisierung >=4 Perimeter + 40 % Gyroid
    # --- FEM-Steuerung ---
    MESH_MM: float = 10.0        # Produktionsnetz
    MESH_MM_TEST: float = 20.0   # Grobnetz für Tests
    DEFL_TOP_MAX: float = 0.5    # zulässige Deckflächenverformung (Dichtheit)

P = Params()

# Vierkantwellen laut Anleitung: (Länge, Wandstärke min, max)
SHAFT_TABLE = ((120.0, 27.0, 47.0), (140.0, 48.0, 67.0), (160.0, 68.0, 80.0))

def effective_wall(p: Params = P) -> float:
    """Einbauwandstärke aus Lüftersicht: Dach + Adapter (inkl. Klebefuge)."""
    return p.ROOF_T + p.H_RAISE

def select_shaft(p: Params = P) -> float:
    t = effective_wall(p)
    for length, lo, hi in SHAFT_TABLE:
        if lo <= t <= hi:
            return length
    raise ValueError(f"Effektive Wandstärke {t} mm außerhalb 27-80 mm")

def outer_dims(p: Params = P):
    """(Länge in x = Fahrtrichtung, Breite in y)."""
    return (p.CUTOUT_W + p.W_TOP_FRONT + p.W_TOP_REAR,
            p.CUTOUT_W + p.W_TOP_LEFT + p.W_TOP_RIGHT)

def wind_force(p: Params = P) -> float:
    """Horizontale Auslegungswindlast inkl. Sicherheitsfaktor (N)."""
    v = p.V_DESIGN_KMH / 3.6
    q = 0.5 * 1.2 * v * v            # Staudruck, rho_Luft 1.2 kg/m^3
    return q * p.A_HOOD * p.CD_HOOD * p.SF_WIND

def allowables(p: Params = P):
    """(dauerhaft, kurzzeitig) zulässige von-Mises-Spannung in MPa."""
    kurz = p.SIGMA_BASE * p.DERATE_TEMP * p.DERATE_Z
    return kurz * p.DERATE_CREEP, kurz

def params_hash(p: Params = P) -> str:
    """8-Zeichen-Hash über alle Parameter (verknüpft Report <-> Druckdateien)."""
    blob = repr(sorted(asdict(p).items())).encode()
    return hashlib.sha256(blob).hexdigest()[:8]
```

- [ ] **Step 5: Tests laufen lassen — müssen bestehen**

Run: `bin/fc tests/run_tests.py`
Expected: `5 bestanden, 0 fehlgeschlagen`, Exit-Code 0.

- [ ] **Step 6: Checkpoint** — Ergebnis melden, User um Commit-Freigabe fragen.
Vorschlag: `feat: Projektgerüst mit params.py und Testrunner`

---

### Task 2: FEM-Toolchain-Smoke (Gmsh + CalculiX headless)

**Files:**
- Create: `tests/test_toolchain.py`

**Interfaces:**
- Produces: Gewissheit, dass Gmsh-Mesh + ccx-Lauf + Ergebnislesen headless funktionieren.
  Das hier etablierte Muster (Binärpfade setzen, `GmshTools`, `ccxtools.FemToolsCcx`,
  Result-Objekt) wird in Task 8/9 wiederverwendet.

- [ ] **Step 1: Failing Test schreiben**

`tests/test_toolchain.py`:
```python
"""Beweist die komplette FEM-Kette am gebündelten Cantilever-Beispiel,
bevor eigenes CAD existiert. Nutzt femexamples aus dem FreeCAD-Bundle."""
import tempfile

import FreeCAD

BUNDLE_BIN = "/Applications/FreeCAD.app/Contents/Resources/bin"

def _ensure_binary_paths():
    g = FreeCAD.ParamGet("User parameter:BaseApp/Preferences/Mod/Fem/Gmsh")
    if not g.GetString("gmshBinaryPath"):
        g.SetString("gmshBinaryPath", BUNDLE_BIN + "/gmsh")
    c = FreeCAD.ParamGet("User parameter:BaseApp/Preferences/Mod/Fem/Ccx")
    if not c.GetString("ccxBinaryPath"):
        c.SetString("ccxBinaryPath", BUNDLE_BIN + "/ccx")

def test_cantilever_durch_gmsh_und_ccx():
    from femexamples.ccx_cantilever_faceload import setup
    from femmesh.gmshtools import GmshTools
    from femtools import ccxtools

    _ensure_binary_paths()
    doc = setup()
    mesh = doc.getObject("FEMMeshGmsh")
    assert mesh is not None, "Beispiel liefert kein Gmsh-Mesh-Objekt"
    err = GmshTools(mesh).create_mesh()
    assert not err, f"Gmsh-Fehler: {err}"

    analysis = doc.getObject("Analysis")
    solver = doc.getObject("SolverCcxTools") or doc.getObject("CalculiXCcxTools")
    fea = ccxtools.FemToolsCcx(analysis, solver)
    fea.update_objects()
    fea.setup_working_dir(tempfile.mkdtemp(prefix="fc_smoke_"))
    fea.setup_ccx()
    msg = fea.check_prerequisites()
    assert not msg, f"Voraussetzungen fehlen: {msg}"
    fea.purge_results()
    fea.run()
    fea.load_results()

    results = [o for o in doc.Objects if o.isDerivedFrom("Fem::FemResultObject")]
    assert results, "kein Ergebnisobjekt geladen"
    vm_max = max(results[0].vonMises)
    assert vm_max > 0.0 and vm_max < 1e6, f"unplausibles vonMises-Maximum {vm_max}"
    FreeCAD.closeDocument(doc.Name)
```

- [ ] **Step 2: Test laufen lassen**

Run: `TEST_FILTER=toolchain bin/fc tests/run_tests.py`
Expected: PASS in < 2 min. Falls FAIL wegen Objektnamen (`SolverCcxTools` vs. andere):
Objektliste mit `print([o.Name for o in doc.Objects])` prüfen und Namen anpassen —
das ist der Zweck dieses Tasks: API-Drift HIER auffangen, nicht in Task 9.

- [ ] **Step 3: Checkpoint** — melden (inkl. gemessener Laufzeit), Commit-Freigabe erfragen.
Vorschlag: `test: FEM-Toolchain-Smoke (Gmsh+CalculiX headless)`

---

### Task 3: Geometrie-Helfer `model/features.py`

**Files:**
- Create: `model/__init__.py` (leer), `model/features.py`, `tests/test_features.py`

**Interfaces:**
- Produces: `rounded_box(l, w, h, r, origin=Vector(0,0,0)) -> Part.Shape`,
  `ring(outer_l, outer_w, r_out, inner_l, inner_w, r_in, h) -> Part.Shape` (zentriert um 0,0, z ab 0),
  `hex_prism(af, h, center_xy, z0) -> Part.Shape` (af = Schlüsselweite),
  `rect_path_points(half_x, half_y, spacing) -> list[(x, y)]` (Punkte auf Rechteckumfang).
  Konsumiert von `frame.py` und `segments.py`.

- [ ] **Step 1: Failing Test schreiben**

`tests/test_features.py`:
```python
import math

from model import features as F

def test_rounded_box_volumen():
    s = F.rounded_box(100, 60, 20, 10)
    v_erw = 100 * 60 * 20 - (4 - math.pi) * 10**2 * 20   # Eckenabzug
    assert s.isValid()
    assert abs(s.Volume - v_erw) < 1.0

def test_ring_volumen_und_zentrierung():
    s = F.ring(500, 500, 12, 400, 400, 5, 25)
    a_out = 500 * 500 - (4 - math.pi) * 12**2
    a_in = 400 * 400 - (4 - math.pi) * 5**2
    assert abs(s.Volume - (a_out - a_in) * 25) < 5.0
    bb = s.BoundBox
    assert abs(bb.XMin + 250) < 1e-6 and abs(bb.XMax - 250) < 1e-6
    assert abs(bb.ZMin) < 1e-9 and abs(bb.ZMax - 25) < 1e-9

def test_hex_prism():
    s = F.hex_prism(7.4, 3.5, (10, 20), 0)
    a_hex = 2 * math.sqrt(3) * (7.4 / 2) ** 2             # Fläche über Schlüsselweite
    assert abs(s.Volume - a_hex * 3.5) < 0.5
    assert abs(s.BoundBox.Center.x - 10) < 0.01

def test_rect_path_points():
    pts = F.rect_path_points(100, 100, 60)
    assert len(pts) >= 12                                  # Umfang 800 / 60 aufgerundet je Seite
    for x, y in pts:
        assert abs(abs(x) - 100) < 1e-6 or abs(abs(y) - 100) < 1e-6
```

- [ ] **Step 2: Run — Expected FAIL** (`ModuleNotFoundError: model`):
`TEST_FILTER=features bin/fc tests/run_tests.py`

- [ ] **Step 3: Implementieren**

`model/features.py`:
```python
"""Wiederverwendbare Geometrie-Bausteine (reines Part-API, kein Dokument nötig)."""
import math

import Part
from FreeCAD import Vector

def _vertical_edges(solid, tol=1e-7):
    out = []
    for e in solid.Edges:
        vs = e.Vertexes
        if (len(vs) == 2 and abs(vs[0].X - vs[1].X) < tol
                and abs(vs[0].Y - vs[1].Y) < tol):
            out.append(e)
    return out

def rounded_box(l, w, h, r, origin=Vector(0, 0, 0)):
    box = Part.makeBox(l, w, h, origin)
    if r > 0:
        box = box.makeFillet(r, _vertical_edges(box))
    return box

def ring(outer_l, outer_w, r_out, inner_l, inner_w, r_in, h):
    """Rechteckring, zentriert um (0,0), z von 0 bis h."""
    outer = rounded_box(outer_l, outer_w, h, r_out,
                        Vector(-outer_l / 2, -outer_w / 2, 0))
    inner = rounded_box(inner_l, inner_w, h + 2, r_in,
                        Vector(-inner_l / 2, -inner_w / 2, -1))
    return outer.cut(inner)

def hex_prism(af, h, center_xy, z0):
    """Sechskantprisma (Muttertasche); af = Schlüsselweite."""
    r = af / 2 / math.cos(math.pi / 6)      # Umkreisradius
    cx, cy = center_xy
    pts = [Vector(cx + r * math.cos(a), cy + r * math.sin(a), z0)
           for a in [math.pi / 6 + i * math.pi / 3 for i in range(6)]]
    wire = Part.makePolygon(pts + [pts[0]])
    return Part.Face(wire).extrude(Vector(0, 0, h))

def rect_path_points(half_x, half_y, spacing):
    """Punkte auf dem Umfang eines Rechtecks (±half_x, ±half_y), von den Ecken
    um spacing/3 zurückgezogen, Abstand <= spacing."""
    pts = []

    def line(p0, p1):
        dx, dy = p1[0] - p0[0], p1[1] - p0[1]
        length = math.hypot(dx, dy)
        n = max(2, math.ceil(length / spacing) + 1)   # ceil: sonst Abstand > spacing
        for i in range(n):
            t = i / (n - 1)
            pts.append((p0[0] + t * dx, p0[1] + t * dy))

    m = spacing / 3
    line((-half_x + m, -half_y), (half_x - m, -half_y))
    line((-half_x + m, half_y), (half_x - m, half_y))
    line((-half_x, -half_y + m), (-half_x, half_y - m))
    line((half_x, -half_y + m), (half_x, half_y - m))
    return pts
```

`model/__init__.py`: leere Datei.

- [ ] **Step 4: Run — Expected PASS**: `TEST_FILTER=features bin/fc tests/run_tests.py`
→ `4 bestanden, 0 fehlgeschlagen`

- [ ] **Step 5: Checkpoint** — Commit-Freigabe erfragen.
Vorschlag: `feat: Geometrie-Helfer (rounded_box, ring, hex_prism, rect_path_points)`

---

### Task 4: Monolith-Rahmen `model/frame.py`

**Files:**
- Create: `model/frame.py`, `tests/test_frame.py`

**Interfaces:**
- Consumes: `params`, `model.features`
- Produces: `build_frame(p=PRM.P) -> Part.Shape` — wasserdichter Volumenkörper:
  Ring 500×500/400×400, Körper z 0..25, Noppen z −3..0, Gusset-Freistellung oben innen,
  Kleberille unten, Außenfase unten. Konsumiert von `segments.py`, `fem/`, `export/`.
  Außerdem `top_z(p) -> float` (= `H_RAISE - GLUE_GAP`).

- [ ] **Step 1: Failing Test schreiben**

`tests/test_frame.py`:
```python
import params as PRM
from model.frame import build_frame, top_z

def _frame():
    global _CACHED
    try:
        return _CACHED
    except NameError:
        _CACHED = build_frame()
        return _CACHED

def test_valide_und_wasserdicht():
    s = _frame()
    assert s.isValid()
    assert len(s.Shells) == 1 and s.Shells[0].isClosed()

def test_hauptmasse():
    s = _frame()
    bb = s.BoundBox
    assert abs(bb.XLength - 500.0) < 0.01 and abs(bb.YLength - 500.0) < 0.01
    assert abs(bb.ZMin + PRM.P.GLUE_GAP) < 1e-6          # Noppen bis -3
    assert abs(bb.ZMax - top_z()) < 1e-6                 # Deckfläche bei 25

def test_oeffnung_bleibt_400():
    s = _frame()
    # Prüfkörper in der Öffnung darf den Rahmen nicht schneiden. Die Öffnung
    # hat R5-Ecken, daher gerundeter Prüfkörper (R5.5 > R5 bei 0.1 mm Inset):
    from FreeCAD import Vector
    from model import features as F
    probe = F.rounded_box(399.8, 399.8, 40, 5.5, Vector(-199.9, -199.9, -5))
    assert s.common(probe).Volume < 1e-6

def test_volumen_plausibel():
    v = _frame().Volume
    assert 1.9e6 < v < 2.4e6, f"Volumen {v/1e6:.2f} l unplausibel"

def test_deckflaeche_vorhanden():
    s = _frame()
    zt = top_z()
    top_area = sum(f.Area for f in s.Faces
                   if abs(f.CenterOfMass.z - zt) < 1e-4)
    assert top_area > 60000, "zu wenig plane Klebefläche oben"
```

- [ ] **Step 2: Run — Expected FAIL**: `TEST_FILTER=frame bin/fc tests/run_tests.py`
(ModuleNotFoundError: model.frame)

- [ ] **Step 3: Implementieren**

`model/frame.py`:
```python
"""Monolithischer Adapterrahmen (vor Segmentierung)."""
import Part
from FreeCAD import Vector

import params as PRM
from model import features as F

def top_z(p: PRM.Params = PRM.P) -> float:
    return p.H_RAISE - p.GLUE_GAP

def _nopple_positions(p):
    """Zwei Noppenringe: innen (zwischen Öffnung und Rille) und außen
    (zwischen Rille und Außenkante)."""
    inner_r = p.CUTOUT_W / 2 + p.GROOVE_OFF / 2                       # ~207.5
    outer_r = p.CUTOUT_W / 2 + p.GROOVE_OFF + p.GROOVE_W + 12         # ~235
    pts = F.rect_path_points(inner_r, inner_r, p.NOPPLE_SPACING)
    pts += F.rect_path_points(outer_r, outer_r, p.NOPPLE_SPACING)
    return pts

def build_frame(p: PRM.Params = PRM.P) -> Part.Shape:
    L, W = PRM.outer_dims(p)
    h = top_z(p)
    x0 = -(p.CUTOUT_W / 2 + p.W_TOP_FRONT)
    y0 = -(p.CUTOUT_W / 2 + p.W_TOP_LEFT)

    outer = F.rounded_box(L, W, h, p.R_OUT, Vector(x0, y0, 0))
    inner = F.rounded_box(p.CUTOUT_W, p.CUTOUT_W, h + 2, p.CUTOUT_R,
                          Vector(-p.CUTOUT_W / 2, -p.CUTOUT_W / 2, -1))
    body = outer.cut(inner)

    # Freistellung für die Gussets der Karosseriebefestigungsplatte (oben, innen)
    rec = F.ring(p.CUTOUT_W + 2 * p.REC_GUSSET_W, p.CUTOUT_W + 2 * p.REC_GUSSET_W,
                 p.CUTOUT_R + p.REC_GUSSET_W,
                 p.CUTOUT_W, p.CUTOUT_W, p.CUTOUT_R,
                 p.REC_GUSSET_D + 1)
    rec.translate(Vector(0, 0, h - p.REC_GUSSET_D))
    body = body.cut(rec)

    # Kleberille unten
    g_in = p.CUTOUT_W + 2 * p.GROOVE_OFF
    groove = F.ring(g_in + 2 * p.GROOVE_W, g_in + 2 * p.GROOVE_W,
                    p.CUTOUT_R + p.GROOVE_OFF + p.GROOVE_W,
                    g_in, g_in, p.CUTOUT_R + p.GROOVE_OFF,
                    p.GROOVE_D + 1)
    groove.translate(Vector(0, 0, -1))
    body = body.cut(groove)

    # Außenfase unten (Sika-Kehlnaht): alle z=0-Kanten nahe der Außenkontur
    def _on_outer(e):
        c = e.CenterOfMass
        near_x = min(abs(c.x - x0), abs(c.x - (x0 + L))) < p.R_OUT + 1
        near_y = min(abs(c.y - y0), abs(c.y - (y0 + W))) < p.R_OUT + 1
        return abs(c.z) < 1e-6 and (near_x or near_y)
    fase_edges = [e for e in body.Edges if _on_outer(e)]
    if fase_edges:
        body = body.makeChamfer(p.CHAMFER_OUT, fase_edges)

    # Klebespalt-Noppen (definierte Elastikfugen-Dicke)
    nops = [Part.makeCylinder(p.NOPPLE_R, p.GLUE_GAP, Vector(x, y, -p.GLUE_GAP))
            for x, y in _nopple_positions(p)]
    body = body.fuse(nops)
    body = body.removeSplitter()
    if not body.isValid():
        raise RuntimeError("frame: Boolesche Operationen ergaben ungültigen Körper")
    return body
```

- [ ] **Step 4: Run — Expected PASS**: `TEST_FILTER=frame bin/fc tests/run_tests.py`
→ `5 bestanden, 0 fehlgeschlagen` (Laufzeit < 60 s)

- [ ] **Step 5: Sichtprüfung erzeugen** (kein Test, einmalige Kontrolle):

`bin/fc` mit Inline-Skript ist unzuverlässig — Mini-Skript `out/` nutzen:
```python
# scratch: preview.py (nicht committen, nach Nutzung löschen)
import Part
from model.frame import build_frame
import pathlib
pathlib.Path("out").mkdir(exist_ok=True)
build_frame().exportStep("out/frame_preview.step")
print("out/frame_preview.step geschrieben")
```
Run: `bin/fc preview.py` — dann STEP in FreeCAD-GUI öffnen und Deckfläche,
Rille, Noppen, Fase visuell prüfen. `preview.py` danach löschen.

- [ ] **Step 6: Checkpoint** — Screenshot/Befund melden, Commit-Freigabe erfragen.
Vorschlag: `feat: Monolith-Adapterrahmen (build_frame)`

---

### Task 5: Analytik `fem/analytic.py` (Haubenfreigang, Thermik, Stoß, Welle)

**Files:**
- Create: `fem/__init__.py` (leer), `fem/analytic.py`, `tests/test_analytic.py`

**Interfaces:**
- Consumes: `params`
- Produces: `hood_clearance(p) -> float` (mm Freigang; `float('inf')` wenn kein
  horizontaler Überlapp), `glue_shear_utilization(p) -> float` (0..1, Auslastung der
  Elastikfuge durch Thermik), `glue_load_shear(p, f_inplane) -> dict` (lastinduzierter
  Klebfugen-Schub, Spec-Kriterium 3), `side_screw_pullout(p) -> dict` (Auszug der
  Seitenschrauben aus der Adapter-Innenwand, Spec-Kriterium 4),
  `joint_checks(p, f_inplane) -> dict` (Schub/Lochleibung am Stoß),
  alle konsumiert von `fem/report.py`.

- [ ] **Step 1: Failing Test schreiben**

`tests/test_analytic.py`:
```python
import params as PRM
from fem import analytic as A

def test_haubenfreigang_default_kein_ueberlapp():
    # Default: Haube ragt 130 mm über den Ausschnitt, Kante erst bei 250 mm
    assert A.hood_clearance() == float("inf")

def test_haubenfreigang_mit_ueberlapp():
    p = PRM.Params(HOOD_TIP_REACH=300.0)        # ragt über die Kante
    c = A.hood_clearance(p)
    # 28 + 30 - 55 = 3 mm Freigang
    assert abs(c - 3.0) < 1e-9

def test_fugenauslastung():
    u = A.glue_shear_utilization()
    # Segmentlänge ~275 mm, dT = 85-20 = 65 K, dAlpha 65e-6:
    # delta = 65e-6*275*65 = 1.162 mm; je Ende 0.581; gamma = 0.194; /0.5 = 0.39
    assert 0.30 < u < 0.50

def test_stossnachweis_traegt_windlast():
    r = A.joint_checks(PRM.P, PRM.wind_force())
    assert r["tau_MPa"] < r["tau_zul_MPa"]
    assert r["lochleibung_MPa"] < r["lochleibung_zul_MPa"]
    assert r["PASS"]

def test_klebfugen_schub_aus_last():
    r = A.glue_load_shear(PRM.P, PRM.wind_force())
    # Rillenfläche ~14e3 mm² -> 444 N ergeben ~0.03 MPa, weit unter 0.1
    assert r["tau_MPa"] < 0.05
    assert r["PASS"]

def test_seitenschrauben_auszug():
    r = A.side_screw_pullout(PRM.P)
    assert r["F_zul_N"] > 150.0            # je Schraube, dauerfest
    assert r["PASS"]
```

- [ ] **Step 2: Run — Expected FAIL**: `TEST_FILTER=analytic bin/fc tests/run_tests.py`

- [ ] **Step 3: Implementieren**

`fem/analytic.py`:
```python
"""Analytische Nachweise, die keine FEM brauchen (Spec §6 LF5, Stoß, Freigang)."""
import params as PRM

def hood_clearance(p: PRM.Params = PRM.P) -> float:
    """Vertikaler Freigang Haubenunterkante über der Dachkante (mm).
    inf, wenn die Haube die Kante horizontal gar nicht erreicht."""
    if p.HOOD_TIP_REACH < p.EDGE_DIST:
        return float("inf")
    return p.H_RAISE + p.HOOD_UNDERSIDE_H - p.EDGE_H

def _segment_length(p: PRM.Params) -> float:
    L, W = PRM.outer_dims(p)
    return max(L, W) / 2 + p.LAP_L        # längster Schenkel eines L-Segments

def glue_shear_utilization(p: PRM.Params = PRM.P) -> float:
    """Auslastung der unteren Elastikfuge durch CTE-Differenz ASA<->GFK.
    Bezugslänge ist das SEGMENT (Segmentierung entkoppelt die Gesamtlänge!)."""
    dT = max(p.T_MAX - p.T_CURE, p.T_CURE - p.T_MIN)
    delta = (p.CTE_ASA - p.CTE_ROOF) * _segment_length(p) * dT   # mm gesamt
    gamma = (delta / 2) / p.GLUE_GAP                             # Schubverzerrung je Ende
    return gamma / p.GLUE_SHEAR_CAP

def glue_load_shear(p: PRM.Params, f_inplane: float) -> dict:
    """Spec-Kriterium 3: lastinduzierter Schub in der unteren Klebfuge
    <= 0.1 N/mm² dauerhaft. Tragend nur die Rillenraupe (konservativ)."""
    groove_len = 4 * (p.CUTOUT_W + 2 * p.GROOVE_OFF + p.GROOVE_W)
    a_bond = groove_len * p.GROOVE_W
    tau = f_inplane / a_bond
    return {"tau_MPa": tau, "tau_zul_MPa": 0.1, "PASS": tau <= 0.1}

def side_screw_pullout(p: PRM.Params) -> dict:
    """Spec-Kriterium 4: Auszugstragfähigkeit einer Seitenschraube (ST4.2)
    in der Adapter-Innenwand. Gewindeeingriff = Bandbreite, konservativ nur
    12 mm angesetzt; Scherfestigkeit = 0.5 * Dauerzulässigkeit."""
    d, l_e = 4.2, 12.0
    import math
    sig_lang, _ = PRM.allowables(p)
    f_zul = math.pi * d * l_e * 0.5 * sig_lang
    f_erf = 100.0        # Anpresssicherung der Platte, real winzig
    return {"F_zul_N": f_zul, "F_erf_N": f_erf, "PASS": f_zul >= f_erf}

def joint_checks(p: PRM.Params, f_inplane: float) -> dict:
    """Konservativer Stoßnachweis: die volle horizontale Last geht durch
    EINEN Stoß (real verteilt sie sich auf vier)."""
    lap_h = (p.H_RAISE - p.GLUE_GAP) / 2
    band = min(p.W_TOP_FRONT, p.W_TOP_REAR, p.W_TOP_LEFT, p.W_TOP_RIGHT)
    a_lap = p.LAP_L * band                       # Scherfläche der Überlappung
    tau = f_inplane / a_lap
    sig_lang, sig_kurz = PRM.allowables(p)
    tau_zul = 0.5 * sig_kurz                     # Schub ~ 0.5 * sigma (v. Mises)
    # Lochleibung der M4-Schraube im ASA (Kurzzeitfall):
    lochleibung = f_inplane / (p.JOINT_BOLT_D * lap_h)
    lochleibung_zul = sig_kurz
    return {
        "tau_MPa": tau, "tau_zul_MPa": tau_zul,
        "lochleibung_MPa": lochleibung, "lochleibung_zul_MPa": lochleibung_zul,
        "PASS": tau < tau_zul and lochleibung < lochleibung_zul,
    }
```

`fem/__init__.py`: leere Datei.

- [ ] **Step 4: Run — Expected PASS**: `TEST_FILTER=analytic bin/fc tests/run_tests.py`
→ `4 bestanden, 0 fehlgeschlagen`

- [ ] **Step 5: Checkpoint** — Commit-Freigabe erfragen.
Vorschlag: `feat: analytische Nachweise (Freigang, Thermikfuge, Stoß)`

---
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

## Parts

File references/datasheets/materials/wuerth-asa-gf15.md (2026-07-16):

# Würth ASA GF15 – Herstellerreferenz

Planstand ist Würth ASA GF15, 1,75 mm, Verkehrsschwarz ähnlich RAL 9017,
Art.-Nr. 4954641200. Würth stellt die technischen Angaben artikelabhängig im
Onlinekatalog bereit; ein frei zugängliches, stabiles PDF war beim Abruf am
15.07.2026 nicht verfügbar.

Herstellerquelle:
<https://eshop.wuerth.de/Product-categories/Filament-ASA-GF/140120024201115.cyid/1401.cgid/en/US/EUR/>

Für die Berechnung sind ausschließlich die konservativen Projektwerte in
`params.py` verbindlich. Der Hersteller weist darauf hin, dass die publizierten
mechanischen Werte von Halbzeugproben und nicht von gedruckten Prüfkörpern
stammen. Da XY-/Z-Coupons derzeit nicht realistisch verfügbar sind, gelten
dauerhaft die konservativen Projektwerte in `params.py`; das Projekt
behauptet deshalb keine Serienfreigabe.

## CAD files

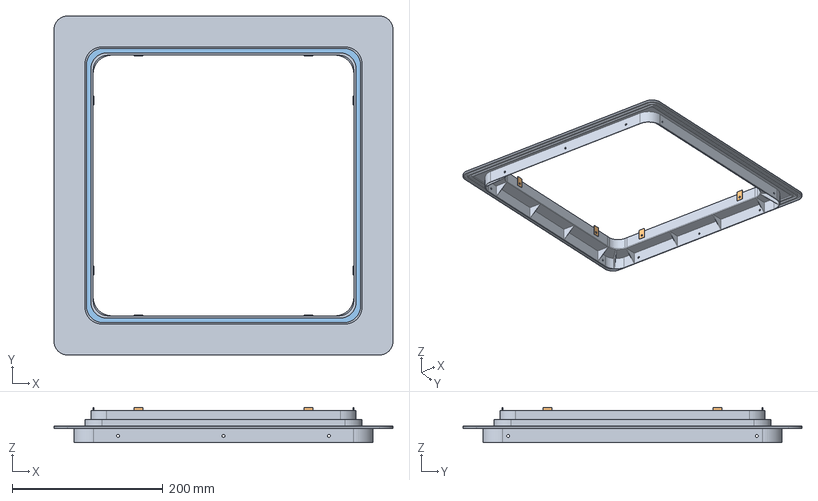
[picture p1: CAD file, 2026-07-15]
references/belluna/models/belluna_baugruppe.step
450.0 x 450.0 x 47.0 mm

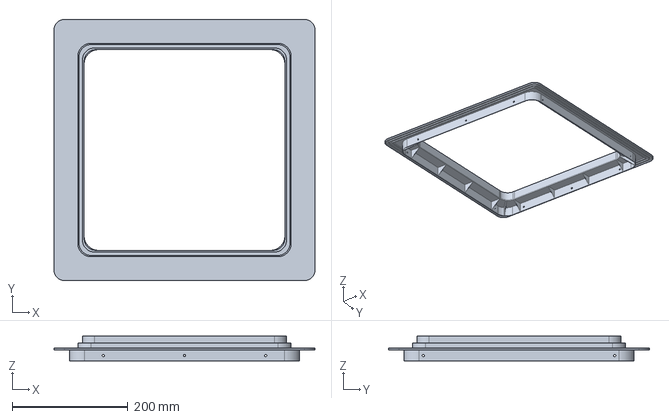
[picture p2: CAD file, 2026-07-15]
references/belluna/models/belluna_platte.step
450.0 x 450.0 x 42.5 mm

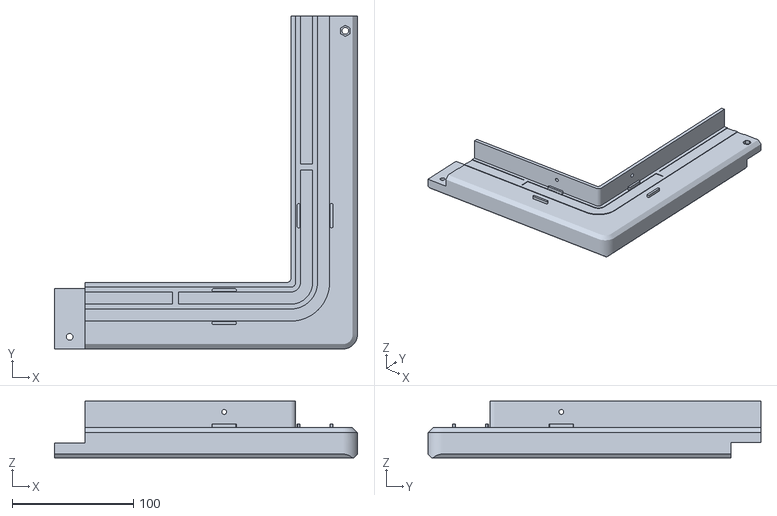
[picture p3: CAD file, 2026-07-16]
release/current/Belluna_Adapter_Universal_x4_PRINT_8eb8b79f.stl
250.0 x 274.8 x 47.0

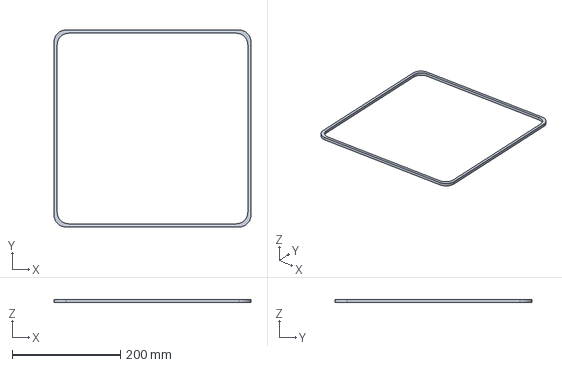
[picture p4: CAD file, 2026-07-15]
references/belluna/models/belluna_dichtring.step
364.0 x 364.0 x 6.00 mm

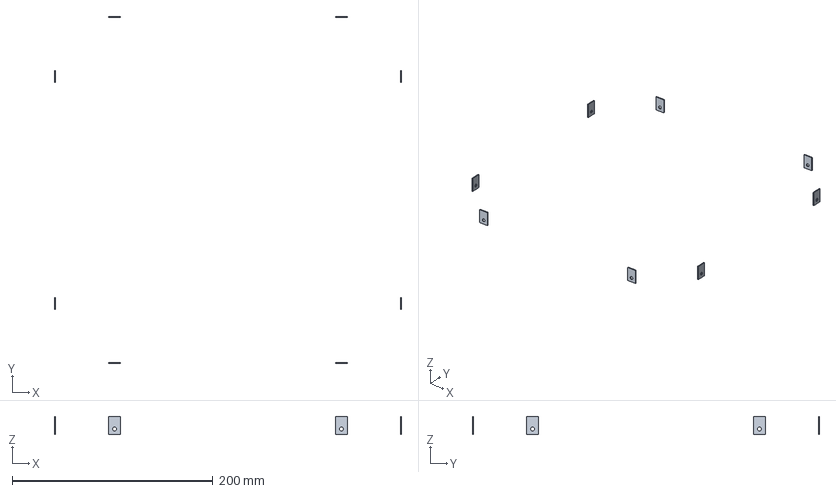
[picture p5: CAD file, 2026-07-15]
references/belluna/models/belluna_metallclips.step
346.0 x 346.0 x 18.0 mm

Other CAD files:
release/current/Belluna_Adapter_Universal_x4_8eb8b79f.step
release/current/Belluna_Adapter_Universal_x4_8029252d.step
references/belluna/models/belluna_baugruppe.stl
references/belluna/models/belluna_dichtring.stl
references/belluna/models/belluna_metallclips.stl
references/belluna/models/belluna_platte.stl

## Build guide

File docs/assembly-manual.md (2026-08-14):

# Generator der illustrierten Montageanleitung

Reproduzierbarer Generator für eine gedruckte, bebilderte **Montageanleitung**
des Belluna-Adapterrahmens. Drei Stufen, wie im übrigen Repo strikt getrennt
(FreeCAD baut Geometrie, Blender rendert, python3/Chrome setzt das PDF):

```
params.py ──► build_stls.py (FreeCAD) ──► build/documentation/<hash>/stl + manifest
                                                   │
                            render_steps.py (Blender) ──► img/*.png
                                                   │
                              build_pdf.py (Chrome) ──► montageanleitung_<hash>.pdf
```

## Aufruf

Komplette Pipeline über den Orchestrator:

```sh
python3 -m pipeline manual
```

Das ist die Regel. Für Iterationen einzelne Stufen:

```sh
bin/fc montage/build_stls.py

blender -b -P montage/render_steps.py -- build/documentation/<hash>/stl build/documentation/<hash>/img
# jedes Bild zusätzlich: ~/Downloads/Belluna-Render-Zwischenstand/
ONLY_IMG=04,09 blender -b -P montage/render_steps.py -- build/documentation/<hash>/stl build/documentation/<hash>/img

python3 montage/build_pdf.py --manifest build/documentation/<hash>/manifest.json
python3 montage/build_pdf.py --manifest build/documentation/<hash>/manifest.json --no-pdf
```

Alle Stufen sind **idempotent** — erneuter Aufruf überschreibt sauber.

Ein vollständiger Lauf kann mehrere Minuten dauern. Für automatisierte Läufe
sollte die CLI mit dauerhaftem Log betrieben werden; ein abgebrochener Blender-
Prozess erzeugt bewusst kein scheinbar vollständiges PDF.

## Dateien

| Datei | Stufe | Zweck |
|---|---|---|
| `build_stls.py` | FreeCAD (`bin/fc`) | Baut Segmente, vermessene Belluna-Rekonstruktion und Dach-Sandwich; schreibt `build/documentation/<hash>/stl/` + Manifest. |
| `render_steps.py` | Blender | Rendert die 15 Schrittbilder nach `build/documentation/<hash>/img/`. Liest nur das Manifest. |
| `build_pdf.py` | python3 | HTML aus `STEPS`-Datenstruktur + Chrome-Headless-PDF. Liest **nur** das Manifest. |
| `docs/assembly-manual.md` | — | Dieses Dokument. |

## Single Source of Truth: das Manifest

`build/documentation/<hash>/manifest.json` ist die einzige Schnittstelle zwischen den Stufen.
`build_stls.py` zieht **alle** Werte zur Laufzeit aus `params.py` bzw. den
`export`-Helpern (`_m5_bolt_length`, `PRM.select_shaft`,
`PRM.groove_centerline_len`, `PRM.bot_kragen_hole_count` …) und legt sie ab:

- `params_hash`, `geom_rev`, `erzeugt` (Datum);
- `geometrie` — abgeleitete Maße für die Blender-Polygon-Filter (Deckhöhe
  `top_z`, Lap-Ebene, Kleberführungen, Padabmessungen, Maskierzone, Holzrahmen);
- `marker` — Markerachsen als Endpunktpaare: `m5` (4×), `dach_screws` (8×)
  und `plate_screws` (16 mögliche Positionen), jeweils exakt aus den
  `params`-Positionen und dem
  gleichen 90°-Rotationsschema wie `model/segments.py`/`model/frame.py`;
- `explosion` — Explosions-Offsets;
- `text` — Textwerte für die Anleitung (M5-Länge, Klebstoff-ml, Wellenlänge,
  Schraubenzahlen/-durchmesser, Materialname, HDT/T_MAX …).

**Keine hartkodierten Geometriemaße** in Bild-/Textlogik. Produktbezogene
Prozesswerte (beispielsweise die 90 min Topfzeit des Epoxids, Lackschichtdicke
und RAL 9003) stehen bewusst als Fixtext in `build_pdf.py::build_model`, weil
sie aus den jeweiligen Produktdatenblättern und nicht aus `params.py` stammen.

## Festgelegtes Materialsystem

Die folgende Tabelle ist interne Fertigungs- und Entwicklungsdokumentation.
Die erzeugte Montageanleitung beginnt dagegen bewusst mit vier fertig
gedruckt gelieferten Segmenten: Druckmaterial, Spulenlogistik, Charge und
Druckparameter werden dort nicht genannt und dürfen nicht wieder in die
Materialliste oder die Montageschritte aufgenommen werden.

| Funktion | Exaktes Produkt | Warum dieses Produkt |
|---|---|---|
| Druckteil | Würth ASA GF15, Verkehrsschwarz ähnlich RAL 9017, 1,75 mm, Art.-Nr. 4954641200 | 15 % GF, UV-/Witterungseignung, hohe Steifigkeit und geringerer Verzug; mechanische Werte sind jedoch nur Halbzeugwerte, daher bleiben permanente FDM-Abminderungen und `PROTOTYPE_ONLY`. |
| Segmentstöße | UHU plus endfest 300, 2K-Epoxid mit 90 min Topfzeit, Doppelkammerspritze inkl. statischem Mischer | Ersetzt seit 2026-08-14 WEICON RK-1300, das am realen Bauteil nicht getragen hat. Laientauglich, weil der Mischer 1:1 selbst dosiert und weder Waage noch Aktivator nötig sind. −40 bis +100 °C decken `T_MAX` ab. Für ASA-GF wird rechnerisch nur 0,50 statt der 16,5 MPa nach DIN EN 1465 angesetzt (Faktor 33). Verarbeitung zwingend bei 18 bis 20 °C, darunter nennt das Merkblatt schlechte Bindefestigkeiten. |
| Dach-, Belluna- und Wetterschutzfugen | Sikaflex-522 weiß, 2× 300 ml (Standard); Carloflex 410 UV weiß als Belluna-konforme Alternative | Beide TDS nennen mindestens 1,8 MPa Zugfestigkeit und hohe Dehnung; die Lastpfadrechnung setzt für beide nur 0,030 MPa normal und 0,050 MPa Schub an. Zwei 10-mm-Raupen tragen den unteren Primärnachweis allein; die äußere bleibt geschlossen, die innere belüftet den Mittelkanal an acht definierten Stellen. Erst nach vollständiger Durchhärtung schützt eine zugängliche, nichttragende 7×7-mm-Außenkehle die verdeckte Klebung. Acht Seitenschrauben bleiben eine rechnerisch nicht angerechnete Reserve. 522 bleibt Standard, weil Sika den Vorbehandlungsweg namentlich dokumentiert. Carloflex erst einsetzen, wenn der passende Kunststoffprimer prozesssicher festgelegt ist; Produkte innerhalb einer Baugruppe nicht mischen. |
| Vorbehandlung und Glätten der 522-Fugen | Sika Cleaner P, Sika Primer-507, Sika Aktivator-205, Sika Tooling Agent N | Lackfreie ASA-GF-/Belluna-Kunststoffflächen: Cleaner P + Primer-507 als ABS-Analogie. GFK-Gelcoat: Cleaner P + Aktivator-205. Vollständig ausgehärteter Mipa-2K-PUR-Decklack wird nach der aktuellen Sika-STP-Tabelle für 2K-PUR-Lack behandelt. Tooling Agent N ist das festgelegte Glättmittel der sichtbaren Außenkehle; keine Spülmittel-, Alkohol- oder Lösemittellösung. Aktuelle Sika-TDS und Ablüftzeiten beachten. |
| Holzrahmen | SikaForce-710 L35 + SikaForce-010, 1,2-kg-A+B-Set | 2K-PUR-System ausdrücklich für Holz/GFK mit EPS/XPS-Sandwichkernen; kontrollierte Härtung in der geschlossenen Dachfuge. Rechnerisch nur 0,05 MPa und eine GFK/Holz-Fläche angesetzt. |
| Lack-Haftgrund | Mipa 1K-Plastic-Grundierfiller-Spray, Art.-Nr. 213390000 | Füllender Haftvermittler für u. a. ABS, PC/ABS und GFK, mit 2K-Decklack überlackierbar. ASA-GF ist nicht ausdrücklich gelistet; der Lack bleibt nichttragend und wird jährlich kontrolliert. |
| Weißer Decklack | Mipa PUR HS 2K-PUR-Acryl-Fahrzeuglack RAL 9003 Signalweiß glänzend + Mipa 2K-MS-Härter MS 25, 2:1 Volumen | Wetter- und vergilbungsfester Nutzfahrzeuglack mit hoher chemischer/mechanischer Beständigkeit; Weiß reduziert die solare Aufheizung des schwarzen Rohlings. |

Primärquellen, unveränderte lokale Datenblätter und nachvollziehbare
Quellenprotokolle sind im
[`references`-Katalog](../references/README.md) mit Quelle und SHA-256 geordnet.

Abgelöst: WEICON RK-1300. Der MMA-Strukturklebstoff war rechnerisch passend,
hat im realen Fügeversuch am gedruckten ASA-GF aber nicht getragen
(Nutzerbefund 2026-08-14). Sein Aktivatorschritt und die Verarbeitungszeit von
wenigen Minuten machten ihn zusätzlich zu einem schlechten Kandidaten für
Laienmontage. Das Datenblatt liegt weiter unter
`references/datasheets/adhesives/evaluated-not-selected/`.

Epoxid ist dabei nicht gleich Epoxid. Der WEICON Epoxyd-Minutenkleber bleibt
ausgeschlossen: sein TDS nennt nur 2,7 % Bruchdehnung und einen Glasübergang
von 44,7 °C (46,1 °C nach Tempern), also deutlich unter `T_MAX = 85 °C`.
Dieselbe Grenze schließt alle schnellen 5-Minuten-Epoxide aus. Gewählt wurde
deshalb ausdrücklich die langsam härtende Variante mit 90 Minuten Topfzeit und
einer Temperaturbeständigkeit bis +100 °C.

Beim Kauf auf den Zusatz **300** achten. UHU führt für den privaten
Endverbrauch zusätzlich ein umformuliertes „UHU plus endfest 90 min", das ohne
kindersicheren Verschluss verkauft werden darf und niedrigere Festigkeiten
erreicht. Maßgeblich für dieses Projekt ist allein das Merkblatt der 300er
Variante unter `references/datasheets/adhesives/uhu-plus-endfest-300.pdf`.

Zwei Verarbeitungspunkte stehen im Merkblatt und sind für Laien die
wahrscheinlichsten Fehlerquellen. Erstens die Temperatur: unter 18 °C bremst
das Merkblatt die Härtung ausdrücklich und nennt schlechte Bindefestigkeiten.
Zweitens das Entfetten: das Merkblatt nennt Aceton, das aber ASA angreift.
Auf den Druckteilen wird deshalb Isopropanol verwendet, angeschliffen wird mit
Schleifleinen Körnung 100 nach Merkblatt.

## Bildliste (`build/documentation/<hash>/img/`)

| Datei | Inhalt | Markierung |
|---|---|---|
| 01 titel_explosion | Explosion 4 Segmente + Platte/Dichtring/Clips | — |
| 02 teile_uebersicht | Universalteil + Belluna-Platte; Dichtring bereits eingelegt | — |
| 03 fuegeflaechen | Lappenende, Fügeflächen | **grün** (Schulter + Stirn) |
| 04 kleber_auftrag | Zwei Segmente am Stoß getrennt | **grün** (2K-Epoxid auf beide Fügeflächen) |
| 05 m5_montage | Stoß von oben | 1× roter M5-Achsmarker (Senkung) |
| 06 m5_mutter | Stoß von unten | 1× roter M5-Achsmarker (Muttertasche) |
| 07 rahmen_komplett | Gefügter Rahmen | 4× dezent rote M5-Marker |
| 08 maskierung_lack | moderate 20°-Unteransicht | **gelb** (gleichmäßige Doppelraupe, Mittelkanal und 16 Pad-Auflageflächen) |
| 09 dach_holzrahmen | Dach-Halbschnitt | Holzrahmen eindeutig holzfarben, ohne Bauteil-fremden Marker |
| 10 aufsetzen | Rahmen über Dach, Kragen sichtbar | — |
| 11 hybrid_dachinterface | Eingesetzter Rahmen mit transparentem Dach und Holzrahmen | 8× rote Achsen der seitlichen, nicht angerechneten Rückfallschrauben |
| 12 kleberaupe | Unterseite | **grün** (zwei flache Führungsböden; acht Unterbrechungen der inneren Raupe sichtbar) |
| 13 aussenkehle | Eingesetzter Adapter auf dem Dach | **grün** (zugängliche, erst nach Primärhärtung aufgebrachte Schutzkehle) |
| 14 platte_schrauben | Rahmen+Platte (halbtransparent) | 16 mögliche rote ST4,2-Achsmarker; 8 werden gesetzt |
| 15 fertig | Kompletter Stapel | — |

## Texte/Bilder ergänzen oder ändern

- **Text**: `build_pdf.py::build_model()` — `material` (Tabelle) und `steps`
  (Liste von `dict(nr, titel, bild, bilder2, absaetze, warn)`). `warn`-Einträge
  sind `("warn"|"hinweis", "Text")`. Variable Werte über `t["…"]` aus dem
  Manifest ziehen (nicht hartkodieren); `de(x)` formatiert mit Dezimalkomma.
- **Layout/Druck-CSS**: `build_pdf.py::CSS` — A4 mit 14-mm-Seitenrand,
  humanistische Avenir-Next-Typografie, Blau als Leitsystem, Gelb nur für
  Warnungen und Rot nur für echte Freigabesperren. Die zwölf Seiten sind als
  stabile Orientierungseinheiten mit festen Seitenumbrüchen gebaut. Damit
  entstehen keine verwaisten Bilder, Tabellenfortsetzungen oder
  Hinweisboxen.
- **Automatische Abnahme**: `pipeline.checks.validate_manual()` verlangt nach
  jedem `manual`-Lauf genau 15 Bilder in 1500×1125 px, den aktuellen
  Parameterhash und genau zwölf PDF-Seiten. Ein unbeabsichtigter Umbruch ist
  damit ein Pipeline-Fehler statt einer stillen Layoutänderung.
- **Neues Bild**: Geometrie/STL in `build_stls.py`, ggf. Marker/Filtergrößen
  ins Manifest; Renderfunktion `imgNN_*` in `render_steps.py` (Kamera, Material,
  `highlight(obj, farbe, praedikat)`, `marker(p1, p2, radius)`); Bildreferenz
  in den passenden `steps`-Eintrag.

## Konventionen (Blender)

- Cycles, 96 Samples, Denoising, 1500×1125.
- **Kräftiger technischer Studiohintergrund** (sRGB ca. 60/149/195, aus dem
  freigegebenen Referenzbild gemessen); sichtbarer Hintergrund und
  Weltbeleuchtung sind über den Camera-Ray getrennt. Dadurch bleibt der
  Hintergrund ruhig, ohne die Formschatten der hellen Bauteile aufzuhellen.
  Der `Standard`-View-Transform bewahrt die definierten RGB-Werte; AgX wird
  bewusst nicht verwendet, weil dessen Highlight-Rolloff weißes ASA grau und
  Signalfarben pastellig erscheinen ließ. Dunkelgraue technische Konturlinien
  mit 50 % Deckkraft sichern die Lesbarkeit ausschließlich am weißen Adapter.
- Alle vier identischen ASA-GF-Segmente erscheinen didaktisch im finalen
  lackierten RAL-9003-Zustand klar weiß; der reale Rohling ist schwarz. Die
  Belluna-Originalplatte ist deutlich beige. Clips silber-metallisch und in allen Belluna-relevanten Bildern
  sichtbar, Dichtring fast schwarz. Dach mittelgrau, Holzrahmen
  holzfarben, XPS blau-grau.
- Marker: emissive Signalrot-Zylinder (Emission Strength 2.0). Flächen-
  Hervorhebung: zweites emissives Material (grün/blau/gelb) per Polygon-Filter
  nach Position direkt in `montage/render_steps.py`.

## Fallstricke

- **`freecadcmd`**: Multiline nur per Skriptdatei, argv unzuverlässig;
  stdout wird mit `reconfigure(line_buffering=True)` explizit gepuffert.
- **Segment-Basisfarbe vs. Hervorhebung**: In Bild 04 werden beide Segmente
  mit derselben weißen ASA-Basisfarbe geladen. Grün bezeichnet damit
  ausschließlich die beiden Klebstoffflächen.
- **Halbschnitt-Beleuchtung**: Die Schnittfläche eines `y>0`-Schnitts zeigt
  nach +y — Kamera **und** Zusatzlicht auf die +y-Seite, sonst bleibt der
  Schnitt unbeleuchtet (Bild 09).
- **Dach als echtes Sandwich**: Die Kern-Kavität wird aus dem Dach-Vollmaterial
  ausgeschnitten und von Holzrahmen + XPS gefüllt (kein z-Fighting im Schnitt).
- **Zwei nach oben/unten zeigende Fügeflächen** (Bild 04) sind nur gemeinsam
  sichtbar, wenn die obere Stoßhälfte angehoben und die Kamera **zwischen** den
  Schulterhöhen (nahezu horizontaler Blick) positioniert wird.
- **Chrome**: absolute `file://`-Pfade, `--no-pdf-header-footer`,
  `--virtual-time-budget=10000` gegen fehlende Bilder.

## Vorbehalt

Die Titelseite trägt bewusst das rote Banner **VORABVERSION**. Der aktuelle
Status bleibt `PROTOTYPE_ONLY`, bis die in `verification.md` aufgeführten
physischen Nachweise und Fahrzeugmaße geschlossen sind.

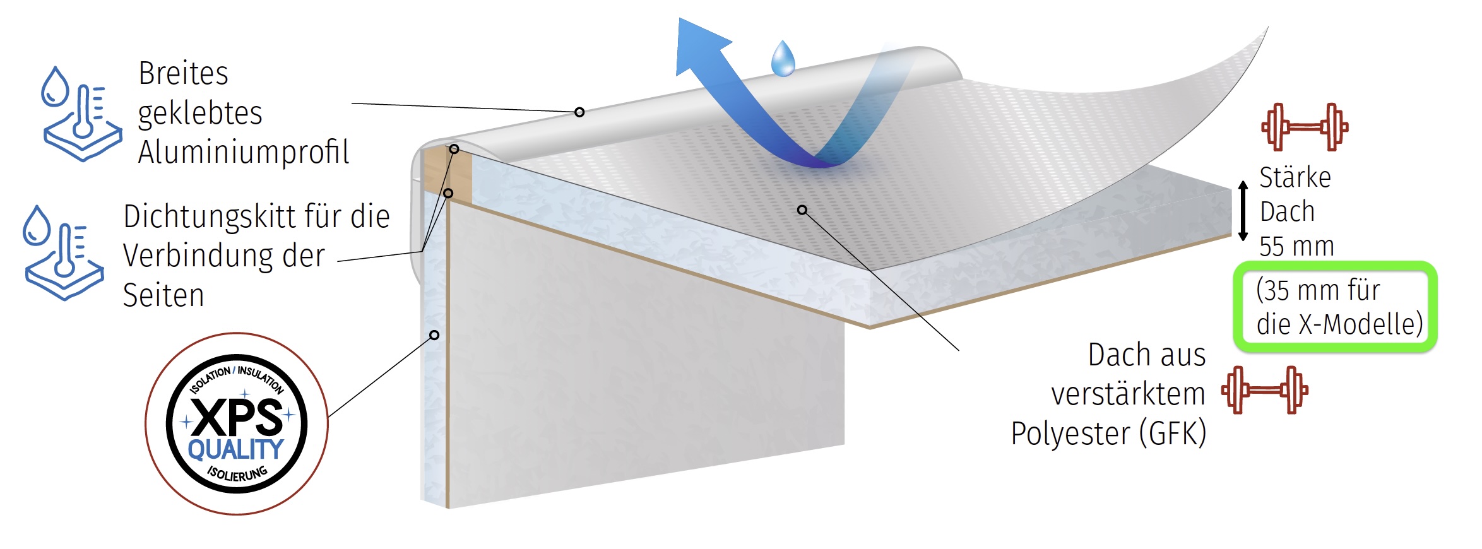
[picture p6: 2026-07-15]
references/vehicle/challenger-x150-roof-construction.jpg

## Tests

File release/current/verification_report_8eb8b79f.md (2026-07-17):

# Verifikationsreport Belluna-Adapterrahmen

Parameterstand: `8eb8b79f` · H_RAISE 28.0 mm · Wandstärke effektiv 63.0 mm · **Vierkantwelle 140 mm**
Material: **Würth ASA GF15, Verkehrsschwarz RAL 9017 ähnlich (Art.-Nr. 4954641200)** · E 3000 MPa · ρ 1100 kg/m³ · HDT/B(0,45 MPa) 99 °C; 1,82-MPa-Wert fehlt

## FEM-Lastfälle
| Lastfall | max vM [MPa] | zulässig | Deckfl.-Verf. [mm] | Status |
|---|---|---|---|---|
| LF1_wind | 0.65 | 11.25 | 0.004 (≤ 0.5) | PASS |
| LF2_schlechtweg | 0.12 | 11.25 | 0.001 (≤ 0.5) | PASS |
| LF3_klemmung | 0.76 | 4.50 | 0.008 (≤ 0.5) | PASS |
| LF4_schnee | 0.06 | 11.25 | 0.001 (≤ 0.5) | PASS |

## Stoß-Submodell
max vM 3.37 MPa ≤ 11.25 MPa → PASS

## Analytische Nachweise
- Haubenfreigang über Dachkante: **OFFEN** — kein Überlapp laut Schätzwerten (EDGE_DIST=250, EDGE_H=55); vor Druckfreigabe messen (Messpunkte B1/B2)
- Elastikfugen-Auslastung (Thermik, LF5; vollständig gefügter 500-mm-Rahmen): 38 % → PASS
- Materialtemperatur: T_MAX 85 °C; Würth nennt nur HDT/B(0,45 MPa) 99 °C, keinen 1,82-MPa-Wert. Weißer RAL-9003-Decklack ist Pflicht; Temperatur-Abminderung 0.50 angewendet
- Stoß analytisch: τ 0.38/5.62 MPa, 1×M5 je 6.98 MPa/11.25 MPa → PASS
- Klebfugen-Schub aus Last: 0.014 ≤ 0.05 N/mm² → PASS
- Seitenschrauben-Auszug: 178 N zulässig ≥ 100 N erforderlich → PASS
- Fertigungslogik: 1 rotationsidentisches Universal-Segment ×4; Belluna-Vollmaterialrippen ±140/±165 auf jeder Seite, 1 M5 je Segmentstoß, Hybrid-Unterkragen
- Belluna-Kragenpassung: nominal 1.5 mm Radialluft mit **gemessenem** A3a=397 mm
- Dachinterface: 2×10-mm-Elastikraupe vollständig über nachzurüstendem Holzrahmen ≥30 mm; 8 seitliche Rückfallschrauben werden rechnerisch nicht angerechnet. X150-Dach ist 35 mm stark; Holzrahmen-Status vor Montage offen

# Gesamtergebnis: **PASS mit Vorbehalt** (offene Mess-/Einbauvoraussetzungen vor Druck und Montage prüfen)

## Datei-Manifest

Git-Commit: `6c5d3517d4e7c1550701f112a8b76b3607c69d5a` · GEOM_REV: `10`

| Datei | SHA256 |
|---|---|
| frame_8eb8b79f.step | `0145b91ee00d65c850f49524f62542607f6f7115cf4381003b1a721431b9481d` |
| universal_segment_x4_8eb8b79f.step | `d48444b3afd927f0b3dbd2dbb8ca766b97bc7aa6afc55df7b21337729d799144` |
| universal_segment_x4_8eb8b79f.stl | `40da5109b71d5772a0f19312ba4cf4c6cc985fa55ae8e95669a2c36519101e60` |
| universal_segment_x4_8eb8b79f.3mf | `c8b41d2fbd7e81b83d3717eb17a9d21da4d2501545db2f133669820d293183b3` |
| montagenotiz_8eb8b79f.md | `e0791de36e661ec4fbf2c24c4342eb9445d97bb0cdd8cc1df8019ddcc76e9ef8` |

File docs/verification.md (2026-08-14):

# Nachweise und Freigabestatus

## Rechnerische Gates

Die rechnerische Gate-Kette prüft vor jeder Release-Paketierung:

1. Parameterkonsistenz und geometrische Invarianten.
2. Wasserdichte, valide B-Reps und vier rotationsidentische Segmente.
3. FDM-Überhänge und definierte massive Schraub-/Stoßzonen.
4. FEM-Lastfälle Fahrtwind, Schlechtweg, Montagehüllkurve und Schnee.
5. Stoß-Submodell, Klebfugenschub und Thermik.
6. Haubenfreigang und Wellenwahl.
7. Digitalen Belluna-Passungscheck als separate `fit`-Stufe.
8. Annahmenbasierten Lastpfadcheck für obere Acht-Schrauben-Gruppe, untere
   2×10-mm-Doppelraupe, den einzelnen M5 je Segmentstoß und
   Holzrahmen–Dachsandwich. Die acht unteren Seitenschrauben werden als
   physische Reserve ausgewiesen, aber nicht als Tragfähigkeit angerechnet.

Der FEM-Ansatz ist bewusst konservativ: Der globale Rahmen wird monolithisch
gerechnet, der Segmentstoß separat. Das ist kein Kontakt-/Ermüdungsmodell der
kompletten Baugruppe. Die beiden Kleberführungsböden werden als starre,
verteilte Lagerflächen angesetzt; die 16 Abstandspads sind nur Montageanschläge
und werden nicht fixiert. Klebstoff- und Dachnachgiebigkeit bleiben dennoch
unaufgelöst. Netz- und Modellgrenzen sind im jeweiligen Report sichtbar zu halten.

Die optionale CFD-Stufe rekonstruiert die äußere Belluna-Hülle aus der
Einbauanleitung. Ihre Ergebnisse sind bis zu Netzkonvergenz, Variantenmatrix
und Korrelation ausdrücklich `INFORMATIONAL_ONLY`. Sie dürfen die bestehende
480-N-Windhülllast nicht reduzieren; ein höherer Wert würde dagegen als
Hinweis für eine Eskalation behandelt.

## Releasezustände

| Zustand | Bedeutung |
|---|---|
| `BLOCKED` | ein rechnerisches Gate ist fehlgeschlagen; kein Paket |
| `PROTOTYPE_ONLY` | rechnerische Gates bestanden, mindestens ein physisches oder gemessenes Gate offen |
| `RELEASED` | rechnerische und dokumentierte physische Gates geschlossen |

Die Release-Pipeline leitet den Status aus dem Engineering-Report ab und
schreibt ihn in `release/current/manifest.json`. Ein Dateiname allein ist
keine Freigabe.

## Aktuelle Ersatzstrategie für nicht verfügbare Werkstoffversuche

Zerstörende, typgeprüfte Druck-, Klebe- und Sandwichcoupons auf
Originalsubstraten stehen derzeit realistisch nicht zur Verfügung. Sie werden deshalb **nicht als angeblich bald
schließbare Voraussetzung behandelt**. Für den Prototypenentscheid gilt
stattdessen die reproduzierbare Abschätzung in [`load-paths.md`](load-paths.md):
stark abgeminderte Grenzflächenwerte, nur eine angerechnete Holz/GFK-Fläche,
1,5-fache Schrauben-Lastkonzentration und keine Addition von Kleber- und
Schraubentragfähigkeit.

Eine benannte Ausnahme entsteht bei der Heki-Demontage: Der ausgebaute
Dachausschnitt ist Originalsubstrat (gealtertes GFK samt Lackaufbau). Er wird
aufbewahrt und für eine einfache Haftprobe genutzt — Sikaflex-522-Raupe nach
Vorbehandlungstabelle applizieren, nach TDS-Durchhärtung von Hand schälen bzw.
mit Kofferwaage abscheren, Bruchbild fotografisch dokumentieren (Adhäsions-
oder Kohäsionsbruch). Das ersetzt keine typgeprüften Coupons, stützt aber
erstmals die Grenzflächenannahmen am realen Substrat; überwiegender
Adhäsionsbruch wäre ein Eskalationssignal **vor** der Verklebung. Dieses
Zeitfenster existiert nur einmal.

Eine zweite, ungeplante Rückmeldung vom realen Bauteil betrifft die
Segmentstöße. WEICON RK-1300 hat dort nicht getragen, ein handelsüblicher
2K-Epoxidklebstoff dagegen schon (Nutzerbefund 2026-08-14). Daraus folgt eine
belastbare Negativaussage und eine schwache Positivaussage: der MMA-Weg ist
ausgeschieden, die Eignung des Epoxidwegs ist gezeigt, aber nicht beziffert.
Der ausgewählte UHU plus endfest 300 ist damit **nicht** quantitativ qualifiziert.
Der Bemessungswert bleibt deshalb bei 0,50 MPa, und der Stoß bleibt so
ausgelegt, dass ein M5 je Stoß die volle 480-N-Hülle auch ohne jede Klebwirkung
trägt.

Am realen Einbau weiterhin unmittelbar prüfbar und deshalb erforderlich sind:

- Ebenheit, Öffnungsmaß und Trockenpassung des realen Segmentsatzes.
- Ein Klebeversuch mit dem tatsächlich gekauften Gebinde an zwei Druckresten
  derselben Charge: K240 anschleifen, verkleben, nach 24 h von Hand brechen und
  das Bruchbild fotografieren. Bricht die Fuge adhäsiv, also blank von der
  Druckoberfläche ab, ist das ein Eskalationssignal **vor** der Rahmenmontage.
- Reales Ausschnittmaß und Zustand des Dachkerns bei Demontage.
- Durchgehender, vollflächig gebundener 30-mm-Rahmen aus Nadelvollholz mit
  ρk ≥ 350 kg/m³ und Faser längs zur jeweiligen Rahmenseite. Beide 10-mm-
  Raupen müssen vollständig über ihm liegen. Die äußere Raupe muss rundum
  geschlossen bleiben; die acht Vents der inneren Raupe und der 4-mm-
  Mittelkanal müssen zur trockenen Öffnungsseite frei bleiben.
- Alle 16 Abstandspads (2,5×20 mm Kontaktmaß) müssen gleichzeitig und ohne
  Kippeln auf dem vom Holzrahmen hinterfütterten GFK aufliegen. Sie
  definieren 3 mm Dachabstand; zusammen mit den 0,6-mm-Führungen entstehen
  3,6 mm Raupenhöhe. Kein Pad darf mit Dichtstoff unterfüttert werden. Keine
  Zwingen, Gurte oder vertikale Verschraubung verwenden: nur gleichmäßig bis
  zum ersten Padkontakt anpressen und danach gegen Verschieben sichern.
- Die acht seitlichen ST4.2×25 mit 3-mm-Vorbohrung und abgedichteten Köpfen;
  sie ersetzen den Klebnachweis nicht und werden rechnerisch nicht angerechnet.
- Vollständige Durchhärtung der unteren Sikaflex-Doppelraupe nach aktuellem
  Produktdatenblatt vor weiterer Montage, Fahrt oder Belastung.
- Erst danach die etwa 7×7 mm große äußere Sikaflex-522-Schutzkehle auf
  trockenem GFK und vollständig ausgehärteter 2K-PUR-Lackflanke herstellen.
  Sie ist zugänglicher, erneuerbarer Wetterschutz und kein angerechneter
  Lastpfad; ausschließlich Sika Tooling Agent N zum Glätten verwenden.
- Flutungstest nach Montage sowie jährliche Sicht-/Handprüfung der äußeren
  Schutzkehle, aller übrigen Nähte,
  der unteren Doppelraupe, der oberen und unteren Schrauben sowie der Lackkanten.
- Setzkontrolle der oberen Schraubgruppe nach den ersten Fahrten
  (Größenordnung 500 km): Kunststoff im Klemmpaket setzt und relaxiert
  (siehe Modellgrenzen in [`load-paths.md`](load-paths.md)); handfest
  kontrollieren, FDM-Gewinde nicht überdrehen.

Ohne Werkstoffversuche bleibt das Ergebnis ehrlich
`PASS_ASSUMPTION_BASED`; den Status `PROTOTYPE_ONLY` halten die offenen
physischen Gates (reale Maße, Einbaukontrollen), nicht die Coupons. Die
Rechnung ist keine Zulassung. Das ist eine benannte Erkenntnisgrenze, kein
verstecktes Versprechen späterer Prüfwerte.

## Günstige Validierungen ohne Gate-Charakter

Geplante Versuche, die zentrale Annahmen zu Messwerten machen, ohne neue
Freigabe-Gates zu erzeugen (Reihenfolge nach Aufwand):

1. **PLA-Passformdruck als FEM-Korrelation**: den ohnehin geplanten
   Passformdruck zusätzlich mit definierter Last prüfen (bekannte Gewichte
   über die Plattenschnittstelle, Messuhr auf Durchbiegung) und mit der
   E-Modul-skalierten FEM-Vorhersage vergleichen. Akzeptanz: Ort und Form der
   Maximalverformung stimmen überein, Betrag innerhalb Faktor 2.
2. **Z-Zugstäbe aus dem realen Druckprozess**: gedruckte Z- und XY-Stäbe
   (gleiches Druckprofil und gleiche Nachbehandlung wie die Serienteile —
   derzeit ungetempert, s. `docs/design.md`) bis zum Bruch belasten
   (Hebel plus Gewichte genügt). Akzeptanz: Z/XY-Verhältnis ≥ dem angesetzten
   `DERATE_Z` 0,5 — bestätigt die Konservativität der Schätzung, die Würth
   mangels FDM-Z-Werten offenlässt. Ersetzt keinen typgeprüften Coupon,
   liefert aber Prozess-Istwerte.
3. **Dachtemperatur-Logging**: IR-/Loggermessung der weiß lackierten
   Dachoberfläche an einem heißen Sommertag. Akzeptanz: Maximum ≤ `T_MAX`
   85 °C; darüber Eskalation (Werkstoff- und Lackentscheid neu bewerten).
4. **Demontage-Haftprobe** auf dem ausgebauten Dachausschnitt (siehe oben):
   Bruchbild dokumentieren; überwiegender Kohäsionsbruch stützt die
   Grenzflächenannahmen.

Der deterministische Toleranz-Sweep (`python3 scripts/toleranz_sweep.py`)
gehört als Planungsschritt **vor** die Messkampagne: Er zeigt je Messfeld, ob
das erwartete Messband ein analytisches Gate oder die Parameter-Validierung
kippen kann, und beziffert die Freigang-Regimegrenzen der B-Messungen.

## Nachvollziehbarkeit

Jeder Engineering-Report enthält Parameter-Hash, GEOM_REV, Git-Revision und
SHA-256 der exportierten Dateien. Der Fit-Report bindet zusätzlich den
Quellcommit und den SHA-256 des verwendeten Belluna-Rekonstruktionsmodells.
`release/current/manifest.json` wiederholt Prüfsummen, Stückzahl und
Orientierung für die tatsächlich ausgelieferten STEP-/STL-Dateien.

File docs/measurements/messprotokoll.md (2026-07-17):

# Messprotokoll — Belluna-Adapterrahmen (Challenger X150)

Datum: __________  ·  Messmittel: Messschieber / Zollstock

## A — Karosseriebefestigungsplatte (am Tisch)

| Nr. | Maß | Default | Gemessen [mm] |
|-----|-----|---|---|
| A1a | Flansch außen, Länge (Fahrtrichtung) | 450 | ______ |
| A1b | Flansch außen, Breite | 450 | ______ |
| A1c | Flanschbreite Seite VORN (Kragen→Außenkante) | 26,5 | ______ |
| A1d | Flanschbreite Seite HINTEN | 26,5 | ______ |
| A1e | Flanschbreite Seite LINKS | 26,5 | ______ |
| A1f | Flanschbreite Seite RECHTS | 26,5 | ______ |
| A2a | Ringklebenut: Abstand außen (Flanschkante→Rippenzone) | — | ______ |
| A2b | Ringklebenut: Breite der Rippenzone | — | ______ |
| A2c | Rippenhöhe (Tiefenmaß) | — | ______ |
| A3a | Kragen Außenmaß (beide Richtungen) | 397 | ____ / ____ |
| A3b | Kragenhöhe | — | ______ |
| A3c | Kragenwandstärke | — | ______ |
| A4a | Gusset-Überstand unter Kleberippen-Ebene | 3 | ______ |
| A4b | Gusset-Reichweite radial ab Kragen | 18 | ______ |
| A5a | Klips-Lochhöhe über Flansch-Unterkante | — | ______ |
| A5b | Klips-Positionen je Seite (Abstände von Ecke) | — | ______ |

Defaults der A-Tabelle aus der vermessenen Rekonstruktion
(`reference_models/belluna.py`, 2026-07-14): Flansch 450 × 450 voll
symmetrisch, Kragen 397 → Maßkette 397 + 2 × 26,5 = 450 muss schließen.
Die 593 × 420 der Einbauanleitung gehören zur Haube, nicht zur Platte.

## B — Fahrzeug (ohne Demontage)

| Nr. | Maß | Default | Gemessen [mm] |
|-----|-----|---|---|
| B1a | Heki-Rahmen-Außenkante hinten → Dachkante | — | ______ |
| B1b | Heki-Rahmenbreite (Öffnungskante→Rahmenaußenkante, innen gemessen) | — | ______ |
| B2  | Höhe Dachkante über Dachebene (am Heck) | 55 | ______ |
| B3  | Dachstärke am Ausschnitt | 35 | ______ |
| B4  | Belluna-Haubenunterkante am Hecküberstand, geschlossen (über Plattenauflage) | 30 | ______ |

## C — bei Mini-Heki-Demontage (später)

| Nr. | Maß | Soll | Gemessen [mm] |
|-----|-----|---|---|
| C1a | Dachausschnitt Länge × Breite | 400 × 400 | ____ / ____ |
| C1b | Eckenradius Ausschnitt | R5 | ______ |
| C2  | Zustand Klebefläche (Notizen) | — | ______________________ |

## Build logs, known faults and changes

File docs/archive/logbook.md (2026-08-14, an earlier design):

# Logbook (repo-lokale Arbeitsnotizen)

> **Archiv:** Chronologisches Arbeitsjournal mit überholten Material-, Pfad-
> und Parameterständen. Für den aktuellen Stand gelten die Dokumente im
> übergeordneten `docs/`-Verzeichnis.

Ergänzt `todo.md` (Follow-up-Register) um eine chronologische Kurzfassung der
Session-Arbeit. Ausführliche Nachweise/Istwerte je Task: `.superpowers/sdd/task-*-report.md`.

## 2026-07-12 — Task 15: Geometrie-Korrektur + parametrische Robustheit

Quelle: `.superpowers/sdd/task-15-brief.md` (Finalreview I3 + Heatmap-Analyse +
User-Auftrag „alles vor der Messkampagne Mögliche"). Ausgangsstand: 7524cda,
45/45 Tests grün, params_hash `9f91735a`.

- Baseline vor Änderung erfasst (Suite 45/45, params_hash `9f91735a`,
  chamber_slot_count=24, dfm_allowed=36788.23, lap_step=4950.0,
  frame_volume=1733843.08 mm³, top_area=60234.49 mm²).
- params.py: `GEOM_REV=2` (Meta, erhöht bei geometrie-wirksamen Code-Änderungen
  ohne Messwert), `NOPPLE_FILLET=1.5` (Kerbentschärfung Noppenfuß, Heatmap
  2026-07-12). validate(p): `NOPPLE_FILLET>=0`,
  `NOPPLE_SPACING >= 3*NOPPLE_R + 2*NOPPLE_FILLET`.
- model/frame.py: Übergangskegel (45°-Flanke, Part.makeCone) am Noppenfuß,
  fused mit dem Zylinder. `_chamber_cell_centers(p, side_w)` seitenspezifisch
  statt global `min(W_TOP)` (Ledger 21/22). k<->Seite-Kanonik aus dem Code
  hergeleitet UND empirisch an der Geometrie verifiziert (Skript-Probe,
  nicht nur Formel-Lesen): k=0 REAR, k=1 RIGHT, k=2 FRONT, k=3 LEFT.
  `chamber_slot_count` jetzt Summe je Seite statt `4*2*n`.
- model/dfm.py: `lap_step = (LAP_L-TOL_JOINT) * Summe(W_TOP)` statt
  `4*(LAP_L-TOL_JOINT)*min(W_TOP)` — bei symmetrischen Defaults exakt
  identisch (4*49.75... eher 4*24.75*50 == 24.75*200 == 4950).
- Symmetrie-Anker bei Defaults NACH der Änderung geprüft (Skript-Probe):
  chamber_slot_count 24 (unverändert), dfm_allowed 36788.23334770628
  (bit-identisch), lap_step 4950.0, top_area 60234.48682836788
  (bit-identisch), chamber_volume_delta 391726.316... (identisch bis auf
  Float-Rauschen). Einzige Abweichung: frame_volume +2163 mm³
  (Noppenkegel-Zusatzvolumen, wie im Brief erwartet). params_hash neu:
  `88bacca5`.
- Neue/geänderte Tests: tests/test_params.py::test_params_frozen (Ledger 3),
  tests/test_frame.py::test_deckflaeche_vorhanden (Ledger 10, Formel statt
  60000 hart), tests/test_analytic.py::test_seitenschrauben_auszug
  (Sollwert-Assertion 266.0 N, Ledger 15), tests/test_segments.py Guard-
  Kommentar (Symmetrie-Voraussetzung), tests/test_asymmetrie.py (neu, 3
  Tests: Frame valide, Segmente valide+überschneidungsfrei+BBox, DFM-Gate) —
  P_ASYM = W_TOP(FRONT 46/REAR 60/LEFT 48/RIGHT 55).
- 1. voller Suite-Lauf: 48/49 bestanden -- 1 Fund: test_loadcases.
  test_face_selektoren (nopple_faces sammelte durch den neuen
  Übergangskegel eine zusätzliche, fälschlich mitselektierte
  Zylinder-Restfläche je Noppe ein, reiner CoM-Toleranzfilter ohne
  Ebenheits-/Normalencheck). Fix: fem/loadcases.py::nopple_faces jetzt wie
  top_faces() exakt auf Part.Plane + Normale gefiltert; ungenutzte
  _planar_faces() entfernt. Reduziert Regressionsrisiko (selektiert wieder
  exakt dieselben Flächen wie vor Task 15).
- 2. voller Suite-Lauf (final): 49/49 bestanden (out/run_tests_t15_v2.log).
- Produktionslauf `bin/fc run_all.py` (Hintergrund, out/run_all_t15.log):
  129 s (alt 128 s), params_hash 88bacca5, alle LF + Stoß PASS. LF1 0.79
  (alt 0.85, −7 %), LF2 0.43 (alt 0.44), LF3 2.24/3.36 (alt 2.13/3.36,
  +5 %, weiterhin engster Fall aber unkritisch), LF4 0.19 (alt 0.18),
  Stoß 3.37 (unverändert). Kein Delta > 15 % -> test_regression.py-
  Referenzwerte unverändert gelassen. PASS mit Vorbehalt (Haubenfreigang,
  unverändert vorbestehend, nicht Task-15-Scope).
- todo.md abgehakt: I3, Ledger 10, Ledger 21/22, Noppenfuß-Radius-Punkt,
  Ledger 3/15 (im Kleinkram-Eintrag vermerkt).
- Vollständiger Nachweis: `.superpowers/sdd/task-15-report.md`.

## 2026-07-12 — Task 15 Nachbesserung: Review-Critical Achsen-Fehlbezug (Stand 24f6fe1)

Befund (Final-Review nach Task 15): `_chamber_cell_centers` nutzte für die
u-Bandlänge (Zellposition entlang einer Seite) die EIGENE W_TOP der Seite
statt der beiden SENKRECHTEN Nachbarseiten, die die Bandlänge physisch
begrenzen. Bei symmetrischen Defaults unsichtbar (eigene W_TOP == Nachbar-
W_TOP), bei Asymmetrie (z. B. W_TOP_REAR=90, Rest 50) erodiert das
SOLID_CORNER bzw. erzeugt Phantom-Slots jenseits des Rahmenrandes.

- Kanonik verifiziert (Rotations-Mapping `(x,y)->(-y,x)` je 90°-Schritt,
  hergeleitet UND per Skript-Probe an echter Geometrie bestätigt, siehe
  `model/frame.py::_side_neighbor_bounds`-Docstring): k=0 REAR (+u←RIGHT,
  -u←LEFT), k=1 RIGHT (+u←FRONT, -u←REAR), k=2 FRONT (+u←LEFT, -u←RIGHT),
  k=3 LEFT (+u←REAR, -u←FRONT).
- `model/frame.py`: `_chamber_cell_centers(p, limit_w)` unverändert in der
  Formel, aber `limit_w` jetzt explizit als Nachbargrenze dokumentiert;
  neue `_side_neighbor_bounds(p)` kapselt die Kanonik; `_chamber_cuts`/
  `chamber_slot_count` bauen +u-/-u-Hälfte jetzt UNABHÄNGIG mit ihrer
  jeweiligen Nachbargrenze (vorher: `[-c for c in half]` derselben Liste).
- Symmetrie-Anker bei Defaults bitidentisch zu 24f6fe1: chamber_slot_count
  24, dfm._allowed_bridge_area 36788.23334770628, frame.Volume
  1736006.070242394, params_hash unverändert 88bacca5 (nur Code geändert,
  keine Parameterwerte).
- Neue Tests `tests/test_asymmetrie.py` (P_CORNER = W_TOP_REAR=90, Rest
  Default): REAR-Band bleibt ≤ 205 (Nachbargrenze LEFT/RIGHT=50, nicht
  REARs eigene 90); chamber_slot_count konsistent zu `len(_chamber_cuts)/4`;
  geometrische Eck-Probe (Prüfquader, common==Quadervolumen).
- Entdeckung bei der Eck-Probe: der im Befund vorgeschlagene Prüfquader
  (x/y 210..240) liegt legitim im Reichweitenbereich der reziprok
  mitwachsenden RIGHT-Seite (RIGHTs -u-Grenze ist laut derselben Kanonik
  W_TOP_REAR) — RIGHT wird durch REAR=90 physisch länger und bekommt dort
  KORREKT eine zusätzliche Zelle, keine Erosion. Skript-Beweis: an dieser
  Box weicht common-Volumen um 6626 mm³ vom Quadervolumen ab, OBWOHL die
  Formel exakt der Review-Vorgabe (Punkt 1) entspricht. Test verwendet
  stattdessen einen per Skript verifizierten, isolierten Prüfquader
  (x 210..240, y 193..199, z 6..18): trennt REARs eigenen (vormals
  fehlerhaften) Beitrag von RIGHTs legitimer reziproker Zelle. Beleg: unter
  der alten (eigene-W_TOP-)Formel wäre dieselbe Box um 1463.5 mm³ hohl
  gewesen (Regressionsnachweis), unter der neuen Formel exakt massiv (diff
  0.0000 mm³).
- Tests: `TEST_FILTER=asymmetrie` 6/6 grün (3 alt + 3 neu). Volle Suite
  56/56 grün, 0 fehlgeschlagen (davon 4 aus unbeteiligten, ungetrackten
  Testdateien eines parallelen Arbeitsstands im selben Repo — eigener
  Tracked-Beitrag 49 Basis + 3 neu = 52).
- Commit: gemäß CLAUDE.md-Vorgabe ("nie automatisch committen, erst nach
  Freigabe") NICHT automatisch erstellt — Änderungen liegen bereit
  (`model/frame.py`, `tests/test_asymmetrie.py`), Commit-Message im Report
  hinterlegt.
- Vollständiger Nachweis: `.superpowers/sdd/task-15-report.md`
  (Abschnitt „Review-Nachbesserung: Achsen-Fehlbezug").

## 2026-07-12 — Task 17: Eckkammern (parametrisierbar, Default AUS)

Quelle: `.superpowers/sdd/task-17-brief.md` (Herstellbarkeits-Paket,
todo.md). Ausgangsstand: d348e91, 60/60 Tests grün.

- params.py: `CORNER_CHAMBERS: bool = False` (Default AUS, verifizierter
  Stand bleibt geometrisch unverändert), `CORNER_ANGLE_MARGIN: float = 18.0`
  (Grad Randabstand des 90°-Sektors je Seite). validate(p): neuer Block
  `if p.CORNER_CHAMBERS` — (a) CHAMBERS-Voraussetzung, (b)
  0<CORNER_ANGLE_MARGIN<45, (c) Kollisions-Ungleichung Ecksektor <-> gerade
  Zellbänder (`sektor_extreme = off + r_out2_rel*sin(radians(margin))` muss
  >= größter vorkommender `band_end + 3mm` sein; bei Defaults 209.524 >= 208,
  PASS).
- model/frame.py: `_ring_radii(p)` als DRY-Helfer aus `_chamber_cuts`
  extrahiert (auch von der neuen Funktion genutzt). Neue
  `_corner_chamber_cuts(p)`: kanonisches Pentagon-Profil (identisch
  `_chamber_profile_face`) in der Ebene y=0 gebaut, um CORNER_ANGLE_MARGIN
  vorrotiert, `Part.Face.revolve(Ursprung, (0,0,1), 90-2*margin)` -> Solid,
  danach auf das Eckzentrum (CUTOUT_W/2-CUTOUT_R, dito) verschoben, dann per
  `_rot(shape,k)` (Rotation um den GLOBALEN Ursprung) auf alle 4 Ecken
  verteilt — KEINE Spiegelung nötig (kanonischer Sektor liegt symmetrisch
  zur 45°-Diagonale). Je Ecke 2 Diagonal-Vents (analog den Seiten-Vents).
  `_chamber_cuts` hängt die Eckkammer-Werkzeuge an dieselbe tools-Liste an
  (ein gemeinsamer cut()+removeSplitter() in build_frame, wie im Brief
  gefordert).
- model/dfm.py: `_allowed_bridge_area` Zone 6 (8 Eck-Vents, Formel wie
  Brief, Faktor 2 zusätzlich wegen diagonaler statt achsparalleler Kanäle,
  nur wenn CORNER_CHAMBERS) — dokumentiert, warum die Chevron-Sektorböden
  selbst keinen eigenen Term brauchen (>45° in jeder Radialebene, wie
  Zone 5).
- Geometrie-Beleg (Skript-Probe, siehe Report): Default-Volumen unverändert
  1736006.070242394 mm³ (Symmetrie-Anker aus Task-15-Ledger, bitidentisch).
  EIN-Variante (P_ECK = CORNER_CHAMBERS=True): Volumen 1694758.49 mm³,
  Delta 41247.58 mm³ (Band 2.5e4..7e4 laut Brief). Restwand an der
  45°-Diagonale zur Außenkontur: 25.81 mm (Brief-Schätzung „≈26mm"
  bestätigt). params_hash(P)=`eccafbc1` (ändert sich zwangsläufig durch die
  2 neuen Felder, GEOM_REV bleibt 2), params_hash(P_ECK)=`177d6901`.
- Neue Tests `tests/test_eckkammern.py` (6): Frame valide+1 Shell, Volumen-
  delta-Band, Segmente valide+überschneidungsfrei, DFM-Gate, validate()
  wirft ValueError ohne CHAMBERS, Default-Anker (Volumen + Hash-Diff-Nach-
  weis). Alle 6 grün; volle Suite 66/66 grün, 0 fehlgeschlagen.
- Rendering-Beleg: Wegwerf-Skripte (render/make_views_stl.py kann
  params.P nicht per Parameter überschreiben) bauen P_ECK, schneiden bei
  z=14 horizontal (wie render/make_views_stl.py::ZCUT) und rendern eine
  Top-Down-Orthoansicht: `out/render/task17_eck/v_schnitt_horizontal.png`
  — zeigt alle 4 Eck-Sektoren (Ring 1 + Ring 2, mit sichtbarem
  Margin-Abstand zu den geraden Zellbändern) klar von den geraden
  Kammerzellen abgesetzt.
- Vollständiger Nachweis: `.superpowers/sdd/task-17-report.md`.

## 2026-07-12 — Task 17 Review-Critical-Fix: falscher Referenzradius in validate()

Ausgangsstand: `80c6fbb`, 66/66 grün. Befund: die `validate()`-Kollisions-
ungleichung verglich den Sektor-Außenradius (`r_out2`) mit der Zellband-
grenze — der kritische Punkt liegt aber am Innenradius `r_in1` (entlang
des margin-Strahls `y(x)=off+tan(margin)*(x-off)` wächst `y` monoton mit
`x`). Vor jeder Code-Änderung per Skript reproduziert:
`Params(CORNER_CHAMBERS=True, CELL_L=53.0)` — `validate()` PASS,
`build_frame().isValid()` `True` (1 Shell), aber reale Überschneidung
letzte-Ring1-Zelle/Ecksektor = **516.2968692898736 mm³** (Boolean-Probe).

- model/frame.py: neue Funktion `_corner_keepout(p)` (`off +
  tan(radians(CORNER_ANGLE_MARGIN))*(r_in1-off) - CORNER_GAP`, Defaults
  196.223956 mm). `_chamber_cell_centers` wendet sie als **Filter NACH**
  der bestehenden Zentrierung an. Wichtig: ein direktes `band_end =
  min(band_end, corner_keepout)` VOR der Margin-Berechnung wurde erst
  probiert und dann verworfen, weil es bei Defaults ALLE Zellzentren
  verschoben hätte (letzte Zelle 193→188.6 mm, numerisch nachgerechnet) —
  das hätte den unveränderlichen Default-Volumen-Anker gebrochen, obwohl
  das natürliche Raster den Keepout ohnehin schon einhält.
- params.py: neuer Parameter `CORNER_GAP: float = 3.0`. `validate()`:
  die widerlegte `sektor_extreme`-Ungleichung entfernt, ersetzt durch
  Kohärenzprüfung `corner_keepout > SOLID_JOINT_HALF` + `CORNER_GAP >=
  1.0`.
- Docstrings korrigiert (`model/frame.py::_corner_chamber_cuts` §
  „Kollisionsfreiheit", `params.py::validate`): r_in1 statt r_out2,
  Herleitung y(x) monoton in x. Klarstellung zum alten Minor-Fund („Brief
  widerspricht Zahlenbeispiel", Report §10): der Fehlbezug betraf sowohl
  Richtung als auch Referenzradius.
- 2 neue Tests `tests/test_eckkammern.py` (jetzt 8 statt 6):
  Regressionsprobe (`CELL_L=53`: gefiltertes Raster `[66.5,122.5]` statt
  `[66.5,122.5,178.5]`, Summen-Overlap aller Zell- vs. Sektor-Kavitäten
  < 1e-6 mm³, `build_frame` weiter valide) + exakter P_ECK-Volumen-/Delta-
  /Keepout-Anker.
- Anker bitidentisch: `build_frame(PRM.P).Volume`=1736006.070242394 mm³,
  `build_frame(P_ECK).Volume`=1694758.489540970 mm³, Delta=41247.580701424
  mm³ — alle Diffs 0.0. `params_hash` ändert sich zwangsläufig durch das
  neue Feld: `P`=`da0d8553` (vorher `eccafbc1`), `P_ECK`=`d1eee427`
  (vorher `177d6901`).
- Volle Suite: `timeout 700 bin/fc tests/run_tests.py` → **68 bestanden,
  0 fehlgeschlagen**.
- Vollständiger Nachweis: `.superpowers/sdd/task-17-report.md` §11.

## 2026-07-12 — Task 16: Gate-Härtung + Konsolidierung (Abschluss Vor-Messkampagnen-Paket)

Ausgangsstand: `ff14e9a`, 68/68 grün, `params_hash` `da0d8553`. Quelle:
`.superpowers/sdd/task-16-brief.md` (7 Blöcke, Reihenfolge 6→4→1→2→3→5→7).
Reine Härtung/Refaktorierung + 2 neue Features (Manifest, DFM-Gate) — keine
Params-Feldänderung, Hash bleibt zwangsläufig unverändert.

- Block 6 (Kleinkram): `FREECAD_BUNDLE`-Env-Override in `bin/fc` +
  `fem/run_fem.py`; `scripts/{render,heatmap}.sh` → `set -euo pipefail` +
  `BLENDER_BIN=${BLENDER_BIN:-$(command -v blender)}`; `encoding="utf-8"`
  in report/export/messkampagne; `params.RHO_AIR=1.2` statt Magic Number;
  `test_toolchain.py` try/finally um `closeDocument`; `fem/analytic.py`
  ungenutztes `sig_lang` entfernt; `test_export.py` alle 3 Tests
  Reihenfolge-unabhängig.
- Block 4: `fem/run_fem.py::run_case` wirft `RuntimeError` statt
  `IndexError` bei leerer Ergebnisliste (inkl. ccx-Arbeitsverzeichnis) und
  prüft `fea.run()` explizit (`rc is not True` — reale FreeCAD-1.1.1-API
  liefert Bool, nicht den im Brief unterstellten Fehlstring, im Quellcode
  von `femtools/ccxtools.py` verifiziert). Neues Feld
  `defl_top_is_fallback` (True im Submodell ohne echte Deckflächen-Knoten);
  `fem/report.py` druckt „(Fallback)" dahinter.
- Block 1 (Ledger 42 + M7): `write_report(...) -> tuple[bool, bool]`
  (ok, vorbehalt) statt Text-Matching; `run_all.py` gated direkt darauf,
  kein Grep im Reporttext mehr; leeres `fem_results` → `ValueError`.
  `tests/test_report.py`: 5 Tests (3 umgestellt + 2 neu).
- Block 2 (Finalreview I1): neu `export/manifest.py::append_manifest`
  hängt SHA256-Manifest + Git-Commit + GEOM_REV an den Report;
  `run_all.py` ruft es nach `export_all` mit `git rev-parse HEAD` auf.
  `tests/test_manifest.py` (3 neu).
- Block 3 (Finalreview I2 + M4): `export/export.py::export_all(p, out_dir,
  frame=None, segments=None)` — rückwärtskompatibel. `run_all.py` baut
  `frame`+`segments` je einmal, DFM-Gate je Segment (`overhang_area` gegen
  `allowed*1.2+200`) VOR den FEM-Läufen (fail-fast) und VOR dem Export
  (Exit 1 bei Verletzung), reicht beide Shapes an `export_all` durch.
- Block 5 (heikelster Block, M1/Ledger 23/30/33): `params.py` neu
  `min_band`/`lap_height`/`groove_centerline_len`; Verbraucher
  `fem/analytic.py` (joint_checks, glue_load_shear), `fem/joint_check.py`,
  `export/export.py` umgestellt; `validate()` nutzt `min_band` selbst.
  `model/dfm.py` BEWUSST NICHT angefasst (Brief listet es, aber die dortige
  Summenformel ist der Ledger-21/22-Fix aus Task 15 — ein `min_band` dort
  wäre eine Regression, dokumentiert statt blind befolgt).
  `model/features.py::rotz(shape, k)` ersetzt die identischen `_rot()`-
  Kopien in `frame.py`/`segments.py` (Wrapper entfernt, `test_eckkammern.py`
  mitgezogen). `test_toolchain.py` importiert `_ensure_binary_paths` jetzt
  aus `fem.run_fem`. Anker bitidentisch geprüft: `frame.Volume`
  1736006.070242394, `dfm_allowed` 36788.23334770628, τ 0.384, Lochleibung
  6.98, `wind_force` 480.0 — alle 0 Diff.
- Block 7 (Task-17-Re-Review Minor 2): 2 neue Tests in
  `test_eckkammern.py` — explizite Werkzeugzahl-Konsistenz
  `len(_chamber_cuts) == 4*chamber_slot_count + 16` bei
  `CORNER_CHAMBERS=True, CELL_L=53` + Gegenprobe ohne Eckkammern.
- Volle Suite ZWEIMAL grün: **75 bestanden, 0 fehlgeschlagen** (68 + 7 neu:
  3 Manifest, 2 Report, 2 Eckkammern). Zweiter Lauf nach einer kosmetischen
  Manifest-Formatkorrektur, identisches Ergebnis.
- Produktionslauf `bin/fc run_all.py` (Hintergrund+Poll): DFM-Gate-Zeilen
  im Log (alle 4 Segmente PASS, 8909/44346 mm² Überhang), Manifest im
  Report (14 Dateien, 64-hex-SHA256 je Datei, Git-Commit, GEOM_REV=2),
  FEM-Istwerte 0.81/0.43/2.25/0.19/3.37 MPa (≤0.02 MPa Netz-Rauschen vs.
  Task-15-Referenz 0.79/0.43/2.24/0.19/3.37) — PASS mit Vorbehalt wie
  erwartet. Hash bleibt `da0d8553` (Brief-Erwartung „eccafbc1" war bereits
  vor Task 16 überholt, siehe task-17-report.md Zeile 373f. — nicht
  Task-16-Ursache). Laufzeit Gesamtpipeline 127 s (alt 129 s, verrauscht
  durch FEM-Nichtdeterminismus) — isolierte `export_all`-Messung zeigt den
  echten M4-Effekt sauber: 3.86 s (Neubau) → 0.43 s (durchgereicht),
  **~3.4 s gespart** — deutlich weniger als die im Brief geschätzten
  „20-30 s", ehrlich als Diskrepanz dokumentiert statt schöngerechnet.
- Vollständiger Nachweis: `.superpowers/sdd/task-16-report.md`.

## 2026-07-12 — Task 19: Materialwechsel Default → Bambu ASA-CF

Quelle: `.superpowers/sdd/task-19-brief.md` (User-Entscheidung, TDS V1.0 liegt
vor). Ausgangsstand: `32e0a6c`, 75/75 grün, params_hash `da0d8553`.

- params.py Materialkarte (geometriefrei, nur Materialfelder): E_BASE 4200
  (Zug-E XY; Z 2290), SIGMA_BASE 34 (XY; Z 30), RHO 1020, CTE_ASA 60e-6
  (konservative OBERGRENZE — TDS nennt keinen CTE; bewusst NICHT die
  optimistischeren ~40e-6, Gate-Muting-Lehre), DERATE_TEMP 0.5 (85 °C vs.
  HDT 102/Vicat 108), DERATE_Z 0.8 (GEMESSEN Z/XY=0.88, konservativ
  gerundet), DERATE_CREEP 0.4 unverändert (keine CF-Kriechdaten). NU 0.35
  unverändert. Preset-Vergleichstabelle (Standard-ASA, CR3D FibCR20) NUR
  als Kommentar. GEOM_REV bleibt 2 (keine Geometrieänderung).
- Abgeleitete Zahlen nachgerechnet (alle Brief-Werte bestätigt, nur
  Rundungsartefakte dokumentiert): allowables lang/kurz 5.44/13.60;
  Fugenauslastung u=0.208542 (~21 %, Brief 0.2086 = Zwischenrundung);
  side_screw_pullout 430.6747 N (Brief 430.6); τ_zul 6.80,
  Lochleibung_zul 13.60. M5 bleibt (M4 ginge rechnerisch wieder:
  Lochleibung mit M4-Durchgang 4.5 mm = 480/(4.5·12.5) = 8.53 MPa — vorher
  über 8.40 zulässig [durchgefallen], jetzt klar unter 13.60 — aber KEINE
  Geometrieänderung in diesem Task).
- Tests (Erwartungswerte geändert, KEINE Toleranz-Aufweichung):
  test_zulaessigkeiten 5.44/13.60 (±0.01), test_fugenauslastung
  0.15<u<0.30 (mit Rechnung im Kommentar), test_seitenschrauben_auszug
  430.6±5, test_materialkarte "4200.0 MPa" (im Brief nicht gelistet, aber
  zwingend: fem/material.py liest E_BASE), test_export +"ASA-CF"/"250"/
  "Kammer". RED je Block vor Anpassung nachgewiesen (alte Erwartungen
  scheitern an neuen params; Suite-Lauf 1: 74/75 mit exakt dem erwarteten
  einen FAIL vor dem test_materialkarte-Fix).
- Montagenotiz: Bambu ASA-CF (TDS V1.0), Düse 250–280 °C, Bett 80–100 °C
  texturiertes PEI, Kammer 45–60 °C, Trocknung 8 h/80 °C VOR Druck,
  Tempern 80–90 °C/6–12 h (statt 80 °C/4 h), Verzugs-Pflichtblock auf
  CF-Formulierung („dimensional stability", Maßnahmen bleiben PFLICHT),
  Brücken-Hinweis: Stoßstufen-Brücke ~25 mm < 40 mm TDS-Maximum.
- Spec §3.5 (Bambu ASA-CF Default + Datenblatt + DA-3-Begründung + Presets
  + CTE-Vorbehalt), §4 Thermik (60e-6 → ~1,84 mm statt 3,4 mm), §6
  Materialkette (34/4200, 0.5·0.8·0.4 → 5.44/13.60, DERATE_Z gemessen).
  todo.md: neuer offener Punkt CTE-Herstellerwert anfragen.
- Volle Suite: **75 bestanden, 0 fehlgeschlagen** (Lauf 2, nach
  test_materialkarte-Fix). Geometrie-Anker unverändert grün
  (test_eckkammern_default_anker_unveraendert: Volumen 1736006.070242394).
- Produktionslauf `bin/fc run_all.py` (Hintergrund+Poll): params_hash neu
  **`5f063cc3`** (vorher da0d8553). DFM 4x PASS (8909/44346 mm²). FEM:
  LF1 0.80/13.60 (5.9 %), LF2 0.41/13.60 (3.0 %), LF3 2.27/5.44 (41.7 %,
  Brief-Erwartung ~41 % getroffen; vM-Istwert 2.27 vs. 2.25 Task 16 =
  Netz-Rauschen), LF4 0.19/13.60 (1.4 %), Stoß 3.40/13.60 (25.0 %).
  Fugenauslastung 21 % (vorher 39 %). „PASS mit Vorbehalt" (Freigang
  OFFEN, Messkampagne 7) unverändert korrekt, !-Banner im Log, Manifest
  14 Dateien + Git-Rev + GEOM_REV=2, FERTIG nach 127 s.
- Vollständiger Nachweis: `.superpowers/sdd/task-19-report.md`.

## 2026-07-12 — Task 20: Eckkammern als Default aktivieren (Stand 3be4b64)

- params.py: `CORNER_CHAMBERS: bool = True` (User-Entscheidung 2026-07-12;
  Verzugs-/Gewichtsnutzen, FEM-verifiziert Task 17). GEOM_REV bleibt 2 —
  reine Parameter-, keine Code-Änderung; params_hash wechselt über das
  Feld selbst: Default neu **5ba1ea4b**, die AUS-Variante
  (`Params(CORNER_CHAMBERS=False)`) hasht exakt auf den alten Stand
  **5f063cc3** (Beweis der Rückführbarkeit).
- RED nachgewiesen (Suite-Lauf 1 nach Flip, 70/75): exakt die im Brief
  erwarteten 5 Fälle — test_kammern_wirken (ValueError CHAMBERS=False ohne
  CORNER_CHAMBERS=False), 3× test_eckkammern (Anker/Delta gedreht),
  test_asym_chamber_slot_count (P_CORNER erbt die 16 fixen Eck-Werkzeuge).
- Tests angepasst (KEINE Toleranz-Aufweichung, jede Band-Änderung
  nachgerechnet und im Testkommentar dokumentiert):
  - test_kammern_wirken: Solid-Referenz `Params(CHAMBERS=False,
    CORNER_CHAMBERS=False)`; Band (3.0e5, 5.5e5) statt (2.5e5, 5.0e5) —
    Rechnung: v_solid 2127732.386711353, v_default 1694758.489540970,
    Delta 432973.897170383 = 391726.316 (Seitenkammern) + 41247.581
    (Eckkammern); Bandbreite unverändert 2.5e5.
  - test_eckkammern.py: Semantik gedreht — Default-Anker jetzt EIN
    (1694758.489540970), NEU test_eckkammern_ausschalt_anker
    (1736006.070242394, alter Default bleibt beweisbar); P_ECK-Caches
    durch PRM.P/P_AUS ersetzt (kein Doppel-Bauen äquivalenter Frames);
    test_eckkammern_p_eck_volumen_exakt_unveraendert →
    test_eckkammern_delta_und_keepout_exakt (Delta 41247.580701424 exakt,
    corner_keepout 196.223956).
  - test_asymmetrie.py: Werkzeugbilanz len(tools) == 4*slots + 16
    (16 fixe Eck-Werkzeuge: 8 Sektor-Kavitäten + 8 Diagonal-Vents,
    unabhängig von CELL_L/W_TOP; Istfall P_CORNER 112 = 4*24 + 16).
    Übrige Asym-Tests halten formelbasiert unverändert (RED-Beleg).
- Volle Suite: **76 bestanden, 0 fehlgeschlagen** (75 Bestand + 1 neuer
  Ausschalt-Anker-Test).
- Produktionslauf `bin/fc run_all.py` (Hintergrund+Poll): Hash
  **5ba1ea4b**. DFM 4× PASS (8972 bzw. 8959/44828 mm² — Zone 6 aktiv,
  Allowance +482 durch die 8 Eck-Vents). FEM: LF1 0.78/13.60 (5.7 %),
  LF2 0.42/13.60 (3.1 %), LF3 2.29/5.44 (42.1 %, vorher 2.27 = minimal
  höher, Eckmaterial fehlt — Brief-Erwartung getroffen), LF4 0.19/13.60
  (1.4 %), Stoß 3.40/13.60 (25.0 %). „PASS mit Vorbehalt" (Freigang
  OFFEN, Messkampagne 7) unverändert, !-Banner im Log, Manifest 14
  Dateien + Git-Rev + GEOM_REV=2, FERTIG nach 146 s.
- Kosten-STL: `out/adapterrahmen_segment_5ba1ea4b.stl` (Kopie seg0);
  Segmentgewicht 430.7 g (V=422235.2 mm³ × RHO 1020) — vorher ~441 g,
  ~10.5 g je Segment gespart.
- Doku: Spec §4 Innenleben (Eckkammern seit 2026-07-12 Default EIN),
  todo.md Eckkammern-Punkt als aktiviert markiert.
- Vollständiger Nachweis: `.superpowers/sdd/task-20-report.md`.

## 2026-07-13 — Task 21: Materialwechsel Default -> Würth ASA GF15 (Stand b3123da)

- params.py: Materialkarte Würth ASA GF15 (Art. 4954641201, Signalweiß
  RAL 9003, Blatt-Stand 05.03.2026). KERNPUNKT Datenlage: das Blatt
  deklariert explizit HALBZEUG-Werte (Spritzguss: Zug 91,2/E 3520/
  Biegemodul 3500 MPa) — E_BASE=3000/SIGMA_BASE=45 sind deshalb
  DOKUMENTIERTE DRUCKWERT-ANNAHMEN (Vorbehalts-Kette wie CTE_ASA seit
  Task 19; SIGMA aus gedruckten GF-ASA-Analoga Phaetus GF10 40-46 XY,
  Halbzeug 91,2 bewusst NICHT verwendet). RHO 1100 (Blattwert),
  DERATE_TEMP 0.5 (Vicat 101/HDT-B 99; Bauteil WEISS -> reale
  Dachtemperatur niedriger als bei schwarzem CF), DERATE_Z 0.5
  (GESCHÄTZT, keine Z-Daten — strenger als Bambus gemessene 0.8),
  DERATE_CREEP 0.4 und CTE_ASA 60e-6 unverändert (gleiche Blatt-Lücke).
  Preset-Tabelle: Würth* / Bambu ASA-CF (NRND) / Standard-ASA mit
  (A.)-Kennzeichnung; Fiberon ASA-CF08, CR3D FibCR20, Extrudr DuraPro
  ASA GF als unbelegte Alternativen OHNE Zahlen (Gate-Muting-Lehre).
- Abgeleitete Werte alle unabhängig nachgerechnet: allowables
  4.50/11.25 (45*0.5*0.5[*0.4]); Auszug 356.2566 N (pi*4.2*12*0.5*4.50);
  tau_zul 5.625; Lochleibung-Ist 6.98 < 11.25; Fugenauslastung
  0.208542 UNVERÄNDERT (CTE gleich); Gewicht 422235.2 mm³ * 1.10 =
  464.46 g/Segment, 4 Segmente 1857.8 g -> 4x 750-g-Spule.
- RED skriptbasiert nachgewiesen (drei alte Erwartungen AssertionError
  gegen neue params: 5.44/13.60, "4200.0 MPa", 430.6±5); Fugen-Intervall
  korrekt weiter GREEN. Tests: test_zulaessigkeiten 4.50/11.25,
  test_materialkarte "3000.0 MPa", test_seitenschrauben_auszug 356.26±5,
  test_export +"ASA GF15"/"RAL 9003"/"12 mm³/s"/"Würth" (ersetzt
  "ASA-CF"; "250"/"Kammer" bleiben). KEINE Toleranz aufgeweicht.
- Montagenotiz: Würth-Profil (Düse 250-270 gehärtet PFLICHT, max.
  12 mm³/s, Bett 100-110 PEI + Haftmittel, geschlossener Bauraum
  PFLICHT, Trocknung 80 °C 4-6 h, Tempern 80 °C/4 h als ANNAHME
  gekennzeichnet, Schrumpf 0,3 % lt. Blatt, Spulenlogistik 4x 750 g).
- Volle Suite: **76 bestanden, 0 fehlgeschlagen** (out/run_tests_task21.log).
- Produktionslauf run_all (Hintergrund+Poll): Hash **12ffab2a** (vorher
  5ba1ea4b), FERTIG nach 142 s. DFM 4x PASS (8972 bzw. 8959/44828 —
  identisch Task 20). FEM: LF1 0.80/11.25 (7.1 %), LF2 0.41/11.25
  (3.6 %), LF3 2.25/4.50 (50.0 %; Brief ~51 % mit vM 2.29 — Ist 2.25 =
  übliches Netz-Rauschen, kraftgesteuert E-unabhängig), LF4 0.19/11.25
  (1.7 %), Stoß 3.37/11.25 (30.0 %). Fugen 21 % unverändert. „PASS mit
  Vorbehalt" (Freigang OFFEN, Messkampagne 7) unverändert, !-Banner
  vorhanden, Manifest 14 Dateien + Git b3123da + GEOM_REV 2.
- Geometrie-Anker bitidentisch: seg0_12ffab2a.stl SHA256 == seg0_5ba1ea4b.stl
  (276a88b7…) — Materialwechsel nachweislich geometriefrei; das
  5ba1ea4b-STL bleibt geometrisch gleichwertig.
- Kosten-STL: out/adapterrahmen_segment_12ffab2a.stl (Kopie seg0);
  Segmentgewicht 464.46 g (V=422235.2 mm³ x RHO 1100).
- Doku: Spec §3.5 (Würth-Default, Halbzeug-Vorbehalt, NRND-Bambu,
  5 Alternativen), §4 Thermik, §6 Kette 45*0.5*0.5[*0.4]=11.25/4.50,
  §9/§10 nachgezogen; todo.md CTE-Punkt -> Würth/OEM-Anfrage (XY+Z+CTE).
- Vollständiger Nachweis: .superpowers/sdd/task-21-report.md.

## 2026-07-14 — Task 22: Belluna-Schnittstellen und Standard-ASA (GEOM_REV 5)

- Belluna-Anleitung vollständig gegen das reale 3/2/3/2-Lochbild und den
  Lieferumfang abgeglichen. Die 16 ST4.2x25 sind jetzt vollständig und ohne
  Zusatzschrauben zugeordnet: 8x Belluna-Platte→Adapter und 8x
  Adapter-Unterkragen→nachgerüsteter Holzrahmen. Die zwei Mittellöcher der
  Platte an den Segmentstößen bleiben frei; PT4.0x12 und 0,7 Nm für das
  Lüfter-Hauptelement bleiben unverändert.
- X150-Dach: 35 mm Gesamtstärke, Bestand ohne tragenden Rahmen. Montage setzt
  deshalb einen wasserfest verleimten, mit PU-Leim eingesetzten Holzrahmen im
  XPS-Rand voraus (Breite mindestens 30 mm, Höhe = reale Kernstärke). Der
  gedruckte Kragen wird nicht gegen XPS als Schraubgrund gerechnet.
- Geometrie: Unterkragen mit acht seitenspezifischen Löchern bei ±140/±165,
  2,5 mm axialer Kragenluft, volle 25-mm-Materialpfade unter den acht oberen
  Schrauben, vier beschriftete statt vermeintlich identische Segmente. Die
  freie Außenkante entwässert über eine supportfreie 47°-Fase; Kammerdecken
  folgen der Fase. M5-Stoßschrauben radial auf 30 mm verschoben und
  Kopftaschen auf 6 mm vertieft; Taschen nach Montage bündig mit Epoxid
  versiegeln.
- Materialkarte auf lokales, unverstärktes Standard-ASA umgestellt:
  E=1726 MPa, Zug=40 MPa, rho=1070 kg/m³, HDT 96/86 °C. Wegen nur 1 K Abstand
  zwischen HDT(1,82 MPa) und T_MAX=85 °C gilt weiß/hell als Voraussetzung;
  Temperaturfaktor 0,35 und Z-Faktor 0,6 bleiben konservativ. CTE=90e-6/K
  ist mangels Chargenwert eine Annahme. PC/ABS bleibt wegen schwarzer Farbe,
  6 % Bruchdehnung und fehlender expliziter UV-Angabe nur Rückfalloption.
- Thermik auf die reale, vollständig epoxid-/M5-gefügte 500-mm-Baugruppe
  korrigiert: Elastikfugen-Auslastung 70 % (PASS), nicht mehr künstlich auf
  eine Segmentlänge reduziert.
- Export: STEP bleibt in Einbaulage; STL/3MF wird automatisch 180° gedreht
  und mit der Deckfläche auf Z=0 gelegt. Ein Regressionstest prüft alle vier
  STL-Boundingboxen und die Druckhöhe von 47 mm.
- Volle Suite: **88 bestanden, 0 fehlgeschlagen**. Produktionslauf Hash
  **ec28c9f3**: DFM 4x PASS (Segment 0: 2872/8351 mm², Segmente 1–3:
  2859/8351 mm²); FEM LF1 0,75/8,40, LF2 0,37/8,40,
  LF3 1,35/3,36, LF4 0,11/8,40 MPa, jeweils PASS. Gesamtstatus bewusst
  **PASS mit Vorbehalt, keine Druckfreigabe**: A3a/reales Kragenmaß,
  Ausschnittmaß nach Demontage, heller Farbton und ein ASA-Probedruck mit
  Trocken-Fit bleiben physische Gates.

## 2026-07-14 — Task 23: Ein Universal-Segment ×4 (GEOM_REV 6)

- Vier seitenspezifische Dateien wieder auf ein rotationsidentisches
  Universalteil zurückgeführt, ohne das reale Belluna-Lochbild zu verändern:
  Dachinterface umlaufend 2× ±140 mm je Seite; Platteninterface hält auf jeder
  Seite geschlossene Vollmaterialpfade für ±140 und ±165 mm vor. Nur die acht
  realen Belluna-Außenlöcher werden durch die Platte gebohrt; die acht
  ungenutzten Pfade sind massive Rippen, keine offenen Vorratslöcher.
- Die frühere, grobe Lösung ließ an Schraubpositionen komplette 43-mm-
  Kammerzellen aus. REV 6 erhält alle Zellen und fust nur 10 mm breite,
  25 mm lange Rippen zurück. Die Rippen wachsen in Druckorientierung von der
  Deckplatte mit 45°-Unterseite supportfrei auf. Nahe ±165 mm werden die
  Ø4-Ventkanäle innerhalb ihrer Zelle um 4,5 mm verschoben; 1 mm Luft zur
  Rippe und der offene Kanal im fertigen Boolean-Körper sind getestet.
- Rotationsidentität wird geometrisch bewiesen: alle vier Montage-Shapes
  werden um −k×90° zurückgedreht, die symmetrische Differenz zum Referenzteil
  bleibt <1 mm³. Montage nur drehen, nie spiegeln/umdrehen.
- Export erzeugt genau fünf Artefakte: Gesamt-STEP, Universal-STEP,
  Universal-STL, Universal-3MF und Montagenotiz. Hash `081422f2`; die eine
  Datei heißt `universal_segment_x4_081422f2.*`.
- Stückvolumen 461842,87 mm³, bei ρ=1,07 g/cm³ rund 494,17 g; vier Teile
  rund 1,977 kg. Gegen REV 5 sinkt die Druckmasse um rund 100,3 g, obwohl nun
  jede Seite beide Belluna-Rippenvarianten trägt.
- Volle Suite: **92 bestanden, 0 fehlgeschlagen**. Produktionslauf 190 s:
  DFM 4× PASS (2948/8834, danach 2935/8834 mm²); FEM LF1 0,75/8,40,
  LF2 0,37/8,40, LF3 1,35/3,36, LF4 0,11/8,40 MPa; Stoß
  3,38/8,40 MPa, alles PASS. Gesamtstatus weiterhin bewusst **PASS mit
  Vorbehalt, keine Druckfreigabe** bis A3a/Ausschnitt/Holzrahmen real geprüft
  und ein helles ASA-Segment als Ebenheits-/Trocken-Fit-Probedruck vorliegt.

## 2026-08-14 — Klebstoffwechsel Segmentstöße: RK-1300 raus, 2K-Epoxid rein

Auslöser: Nutzerbefund aus der realen Montage. WEICON RK-1300 hat die
Segmentstöße nicht verklebt, ein handelsüblicher 2K-Epoxidklebstoff dagegen
schon. Auftrag war, ein für Laien handhabbares Produkt auszuwählen und die
Anleitung darauf umzustellen.

- Ausgewählt: **UHU plus endfest**, 2K-Epoxid mit 90 min Topfzeit,
  Doppelkammerspritze mit Mischdüse, 1:1, −40 bis +100 °C, rund 19 MPa auf
  Aluminium, rund 35.000 mPa·s. Quellenprotokoll unter
  `references/datasheets/adhesives/uhu-plus-endfest-source.md`.
- Auswahlgrund Laienmontage: die Mischdüse dosiert selbst, es entfallen Waage,
  Aktivator und Ablüftzeit. 90 min Topfzeit statt weniger Minuten decken die
  dreistufige Rahmenmontage ab. Das war die eigentliche Schwachstelle des
  RK-1300 neben der fehlenden Haftung.
- Wichtige Abgrenzung: Der WEICON Epoxyd-Minutenkleber bleibt verworfen
  (Tg 44,7 °C). Dieselbe Grenze schließt alle 5-Minuten-Epoxide aus. Der
  Wechsel gilt ausdrücklich nur für die langsam härtende Variante.
- Namensfalle dokumentiert: Der frühere „endfest 300" hat eine andere
  Härterrezeptur und ist nicht mehr dasselbe Produkt.
- Rechnung: Bemessungswert bleibt bei **0,50 MPa**, jetzt als Faktor 38 auf den
  Aluminiumwert statt Faktor 12 auf den ABS-Wert. Der Klebstoffwechsel soll die
  Nachweiskette nicht entlasten. Auslastung unverändert 77 %, Stoß weiterhin
  PASS. JSON-Schlüssel `rk1300_*` → `segment_bond_*` samt neuem
  `segment_bond_product`.
- Geometrie unverändert: `TOL_JOINT` = 0,25 mm liegt im gut verklebbaren
  Bereich des Epoxids, deshalb **kein** `GEOM_REV`-Schritt.
- Bild 04 heißt jetzt `04_kleber_auftrag.png`. Der Aktivatorschritt entfällt,
  beide Fügeflächen sind grün. `COL_BLUE` wurde ersatzlos entfernt.
- RK-1300-Datenblatt nach `evaluated-not-selected/` verschoben, neuer
  Katalogstatus `evaluated_field_failure` für am Bauteil gescheiterte Produkte.
- `docs/verification.md`: der Feldbefund ist als belastbare Negativaussage und
  schwache Positivaussage eingeordnet. Neues Gate ist ein Klebeversuch mit dem
  tatsächlich gekauften Gebinde an zwei Druckresten.
- Testlage in dieser Umgebung: `load_paths`, `tools_toleranz` und
  `reference_catalog` laufen grün. FreeCAD, Blender und Chrome fehlen hier,
  deshalb sind `test_export` und der Seitenzahl-Check des Montage-PDFs
  **offen**. `python3 -m pipeline manual` muss die zwölf Seiten bestätigen.

## 2026-08-14 — Nachtrag: echtes UHU-Merkblatt ersetzt die Recherchewerte

Der Nutzer hat das technische Merkblatt nachgereicht (UHU PLUS ENDFEST 300,
Doppelkammerkartusche 50 ml). Es liegt jetzt unverändert unter
`references/datasheets/adhesives/uhu-plus-endfest-300.pdf` im Katalog. Das
vorher angelegte Quellenprotokoll ist entfallen, weil das Original vorliegt.

Korrekturen gegenüber dem Recherchestand von heute Vormittag:

- **Produkt ist die 300er Variante**, nicht die 90-min-Konsumentenvariante.
  Beide existieren nebeneinander. Die 300 gibt es weiter als Kartusche,
  Doppelkammerspritze mit statischem Mischer, Tuben und Dosen. Die Anleitung
  weist jetzt ausdrücklich auf den Zusatz „300" beim Kauf hin.
- **Zugscherfestigkeit 16,5 N/mm² nach 24 h** und 17,5 nach einem Monat
  (DIN EN 1465, gestrahltes AlCuMg1, 0,2 mm Klebstoffdicke) statt der aus der
  Websuche übernommenen 19 N/mm². Abminderungsfaktor damit 33 statt 38, der
  Bemessungswert bleibt 0,50 MPa und die Auslastung 77 %.
- **Zwei laienkritische Punkte neu in der Anleitung.** Erstens: unter 18 °C
  bremst das Merkblatt die Härtung ausdrücklich und nennt schlechte
  Bindefestigkeiten. Das ist ein plausibler Kandidat für gescheiterte
  Verklebungen und stand vorher nirgends. Zweitens: das Merkblatt nennt Aceton
  zum Entfetten, was ASA angreift. Auf den Druckteilen gilt jetzt Isopropanol,
  und die Warnung sagt das ausdrücklich gegen das Merkblatt.
- **Schleifkörnung 100** statt K240 an den Fügeflächen, wie im Merkblatt für
  Kunststoffe angegeben. K240 war eine Projektannahme ohne Quelle.
- Härtungsstufen ergänzt: handfest 6 h, funktionsfest 12 h, endfest 24 h.
- Mischerhinweis wörtlich nach Merkblatt: erst auspressen, bis aus beiden
  Kammern Material austritt, dann die Mischdüse aufsetzen.
- Bewusst nicht genutzt: die im Merkblatt beschriebene Warmhärtung zwischen
  70 und 180 °C mit bis zu 30 N/mm². Für ASA-GF ist kein pauschales Tempern
  freigegeben, deshalb bleibt es bei Raumtemperaturhärtung.
- Bewusst dokumentiert: die geprüften Klebstoffdicken liegen bei 0,1 und
  0,2 mm, also unter der Passungsluft von 0,25 mm je Fügefläche. Das ist in
  der Abminderung mit abgedeckt.
- Die Temperaturabhängigkeit auf Seite 3 des Merkblatts ist ein Diagramm und
  in dieser Umgebung nicht auswertbar. Angesetzt bleibt allein der genannte
  Bereich −40 bis +100 °C.

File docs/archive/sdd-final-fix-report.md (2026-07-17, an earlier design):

# Final-Fix-Report — Pre-Merge-Nachbesserung (Whole-Branch-Review)

Datum: 2026-07-12
Umfang: Fix 1 (Critical C1), Fix 2 (Ledger 13), Fix 3 (Ledger 14), Fix 4 (Ledger 35) — ein Commit.

## Fix 1 — `params.validate(p)` gegen stille Geometriebrecher

Neue Funktion `validate()` in `params.py`, verdrahtet als erste Zeile in
`model/frame.py::build_frame()` und direkt nach `import params as PRM` in
`run_all.py`.

### Nachrechnung der Default-Ungleichungen (P = Params())

| Prüfung | Rechnung | Schwelle | Ergebnis |
|---|---|---|---|
| Außenwand hinter Kammerring 2 | `w_min(50) - (INNER_WALL 8 + 2*CHAMBER_W 15 + CHAMBER_RIB 4)` = 50 − 42 = **8.0 mm** | ≥ 2.4 | OK |
| Deckplatten-Rest über Kammern | `DECK_T 5 - REC_GUSSET_D 3` = **2.0 mm** (exakter Grenzfall) | ≥ 2.0 (Prüfcode: `< 2.0` löst nicht aus) | OK, kein Fehlalarm |
| Chevron-Apex vs. Kammerdecke | `kammerdecke = (28-3)-5 = 20`; `apex = 4 + tan(47°)*15/2 ≈ 12.0428` | `apex ≤ kammerdecke-1.0 = 19` | OK (12.04 ≤ 19) |
| VENT_Z-Band | Band = `[apex+VENT_D/2+0.5, kammerdecke-VENT_D/2-0.5]` = `[14.54, 17.5]`; `VENT_Z=17` | innerhalb | OK |
| M5-Kopfsenkung vs. Außenwand | `JOINT_BOLT_OFF 35 + JOINT_CB_D/2 5 = 40` | ≤ `w_min-2.4 = 47.6` | OK |
| GLUE_GAP | 3.0 | ≥ 2.0 | OK |
| Noppenabstand | `NOPPLE_SPACING 60` | ≥ `3*NOPPLE_R = 12` | OK |

Ergebnis: **alle sieben Default-Ungleichungen bestehen ohne Schwellen-Anpassung.**
Der einzige Grenzfall ist der Deckplatten-Rest (exakt 2.0 mm bei den Defaults);
die Spezifikation `if deck_rest < 2.0` (strikt `<`, nicht `<=`) behandelt ihn
korrekt als bestanden — keine Änderung an Defaults oder Schwellen nötig, kein
Anpassungsbedarf gegenüber der Vorgabe.

### Test-Fänge (Messkampagnen-Brecher, alle lösen `ValueError`)

- `W_TOP_*=40` (statt 50) → Außenwand `40-42 = -2.0 < 2.4` → fängt.
- `REC_GUSSET_D=6.0` → Deckplatten-Rest `5-6 = -1.0 < 2.0` → fängt.
- `VENT_Z=24.0` → außerhalb Band `[14.54, 17.5]` → fängt.
- `GLUE_GAP=1.0` → `< 2.0` → fängt.

Neue Tests: `tests/test_params.py::test_validate_defaults_ok`,
`tests/test_params.py::test_validate_faengt_messkampagnen_brecher`.

## Fix 2 — `fem/analytic.py`

Kommentar in `joint_checks()` korrigiert: „Lochleibung der M4-Schraube im
ASA“ → „Lochleibung der M5-Schraube im ASA“ (der Code selbst nutzte bereits
`JOINT_BOLT_D` = 5.5 mm / M5-Durchgang; nur der Kommentar war veraltet, vgl.
`params.py` Zeile zu `JOINT_BOLT_D`: „M5-Durchgang (M4 fiel bei 480 N
Lochleibungs-Nachweis durch)“).

## Fix 3 — `tests/test_analytic.py`

Kommentar in `test_haubenfreigang_default_kein_ueberlapp()` korrigiert:
„Haube ragt 130 mm über den Ausschnitt“ → „Haube ragt 179 mm
(MaxxFan-Maßblatt) über den Ausschnitt“ — deckt sich mit
`params.HOOD_TIP_REACH = 179.0`.

## Fix 4 — `export/export.py`: DIN-912-Normlänge für M5

Inline-Formel `int(p.H_RAISE - p.GLUE_GAP + p.JOINT_NUT_T + 2)` ersetzt durch
Helper `_m5_bolt_length(p)`, der die rohe Klemmlänge (Klemmlänge + Muttertasche
+ Überstand) auf die nächste DIN-912-Normlänge aus
`(20, 25, 30, 35, 40, 45, 50)` aufrundet.

Default-Rechnung: `28 - 3 + 4 + 2 = 31` → aufgerundet auf **35**.

Beleg aus der generierten Montagenotiz (`out/test_export/montagenotiz_*.md`,
`rg -o "M5x[0-9]+"`):

```
M5x35
```

## Testausgaben

```
$ TEST_FILTER=params bin/fc tests/run_tests.py
...
7 bestanden, 0 fehlgeschlagen

$ TEST_FILTER=export timeout 570 bin/fc tests/run_tests.py
PASS test_export.test_export_erzeugt_alle_dateien
PASS test_export.test_montagenotiz_inhalt
PASS test_export.test_step_reimport_volumen
3 bestanden, 0 fehlgeschlagen

$ timeout 570 bin/fc tests/run_tests.py
...
45 bestanden, 0 fehlgeschlagen
```

## Grenzfall-Anmerkungen

- Deckplatten-Rest bei Defaults liegt exakt auf der Schwelle (2.0 mm); der
  strikte `<`-Vergleich in `validate()` verhindert einen Fehlalarm, wie in der
  Vorgabe gefordert. Keine Schwellen- oder Default-Änderung vorgenommen.
- Alle übrigen Ungleichungen liegen mit spürbarem Abstand innerhalb der
  Toleranz — keine weiteren Grenzfälle.
- `run_all.py` ruft `PRM.validate()` direkt nach `import params as PRM` auf,
  vor den übrigen (FreeCAD-lastigen) Modul-Importen — mit Default-Parametern
  ist das ein No-Op, wie von der Aufgabenstellung gefordert (kein
  Produktionslauf nötig, da Parameterstand unverändert).

## Verifizierte Dateien

- `/Users/jihlenburg/maxx150/params.py`
- `/Users/jihlenburg/maxx150/model/frame.py`
- `/Users/jihlenburg/maxx150/run_all.py`
- `/Users/jihlenburg/maxx150/fem/analytic.py`
- `/Users/jihlenburg/maxx150/tests/test_analytic.py`
- `/Users/jihlenburg/maxx150/tests/test_params.py`
- `/Users/jihlenburg/maxx150/export/export.py`

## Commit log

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2026-07-12 feat: Projektgerüst mit params.py und Testrunner
    - bin/fc: FreeCAD-Wrapper-Skript für headless-Betrieb
    - params.py: Zentrale Parameterdatei mit frozen Dataclass Params und 6 Hilfsfunktionen
    - tests/run_tests.py: Minimaler Testrunner für FreeCAD-Python (kein pytest)
    - tests/test_params.py: 5 Testfunktionen für Parametrisierung und Wellen-/Windlast-Berechnungen
    - .gitignore: Ausschluss von out/, __pycache__/, *.FCStd1
    Alle Tests bestanden (5/5), Exit-Code 0.
    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
2026-07-12 feat: Lastannahmen aus MaxxFan-Deluxe-Maßblatt (User-Messdaten)
    A_HOOD 0.10->0.108 m² (408 x (236+28) mm projiziert, Haube offen),
    HOOD_TIP_REACH 130->179 mm ab Dachausschnitt. Windlast damit 480 N
    statt 444 N; Spec §2/§6 und Plan-Kennzahlen nachgezogen. Tests grün (6/6).
    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
2026-07-12 feat: Monolith-Adapterrahmen (build_frame)
    Ring 500x500/400x400 R5, Gusset-Freistellung, Kleberille, Aussenfase,
    68 Klebespalt-Noppen. Zwei Planfehler im Test korrigiert: Prüfkörper der
    Öffnung braucht R5.5-Ecken (scharfer Quader schneidet die R5-Fillets),
    BoundBox-API heißt XLength/YLength statt XLen/YLen.
    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
2026-07-12 feat: analytische Nachweise (Freigang, Thermikfuge, Stoß)
    Implementiert fem/analytic.py mit:
    - hood_clearance: Vertikaler Freigang Haubenunterkante
    - glue_shear_utilization: Auslastung Elastikfuge durch CTE-Differenz
    - glue_load_shear: lastinduzierter Klebfugen-Schub (Spec §3)
    - side_screw_pullout: Auszugstragfähigkeit Seitenschrauben (Spec §4)
    - joint_checks: konservativer Stoßnachweis (Schub/Lochleibung)
    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
2026-07-12 feat: Segmentierung in 4 L-Segmente mit Halbüberlappungsstoß
    build_segments() zerlegt den Monolithen (model/frame.py) in 4 identische
    L-Ecksegmente mit Halbüberlappungsstoß und je 1 M5-Stoßbolzen (Senkung oben,
    Sechskant-Muttertasche unten, TOL_JOINT Luftspalt je Fügefläche).
    Zwei Geometriefixes gegenüber dem Erstentwurf:
    - lap_cut endete bei z=lap_h-0.5 statt z=lap_h -> 0.25 mm Überschneidung
    zwischen gebendem und nehmendem Segment statt Passungsluft.
    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
2026-07-12 feat: DFM-Überhangprüfung in Druckorientierung
    overhang_area() spiegelt das Segment in Druckorientierung (Deckfläche nach
    unten, 180° um x), vermischt aus MeshPart-Facetten Fläche mit Normale
    steiler als 45° nach unten außerhalb des Bett-Kontakts, und zieht bewusst
    zugelassene Brückenzonen (Gusset-Freistellungsring, Kopfsenkungen,
    Muttertaschen) als Erlaubnisgrenze ab.
    Alle 4 Segmente: 8681.69 mm² Überhang gegen 30631.86 mm² erlaubt (28.3 %,
    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
2026-07-12 fix: Stoßstufe als dokumentierte Brückenzone im DFM-Check (Review-Befund)
    Ergänze _allowed_bridge_area(p) um vierte zugelassene Brückenzone:
    - Stoßstufen des Halbüberlappungsstoßes (4 Instanzen)
    - Berechnung: lap_step = 4 * (LAP_L−TOL_JOINT) * minimale Bandbreite
    - Entferne ungenutzten Import top_z aus model.frame
    - Ergänze defensiven Test für _facet_area Kreuzprodukt-Fallback
    Tests: 28 bestanden, 0 fehlgeschlagen.
    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
2026-07-12 feat: Rippenkammern statt Slicer-Infill in build_frame (Task 14)
    Ersetzt den massiven Monolithen durch geschlossene Rippenkammern (2
    konzentrische Ringe je Seite, Chevron-Boden 47°, Vent-Bohrungen Ø4 je
    Zelle) — Festigkeit ist jetzt geometrie- statt slicer-definiert.
    chamber_cell_count(p) exportiert für die DFM-Vent-Allowance.
    INFILL_FACTOR 0.5 -> 1.0 (Kammern übernehmen die Gewichtsreduktion).
    29/29 Tests grün (Segmente/DFM unverändert, DFM._allowed_bridge_area um
    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
2026-07-12 feat: FEM-Materialkarte und Lastfälle LF1-LF4
    - fem/material.py: Homogenisierte ASA-Materialkarte mit E_BASE*INFILL_FACTOR
    - fem/loadcases.py: Lastfälle (Wind, Schlechtweg, Klemmung, Schnee) mit Face-Selektoren
    - tests/test_loadcases.py: 5 Tests (Materialkarte, Face-Selektoren, LF-Vollständigkeit, LF1-Zahlen, LF2-Zahlen)
    - Adaptive Face-Toleranzen (1mm statt 1e-4mm) für FreeCAD-Boolesche Operationen
    - Couple-Force basiert auf Moment-Gleichgewicht mit Flächenschwerpunkten
    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
2026-07-12 docs: DA-Review-Konsequenzen (Versiegelung Pflicht, Zyklik/Relaxation als Restrisiko, exakte Zulässigkeiten in §6, Freigang-Gate-Vorbehalt, PLA-Probedruck vor ASA)
    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
2026-07-12 feat: skriptierter CalculiX-Lauf je Lastfall
    run_case(): kompletter Gmsh+ccx-Lauf (Analysis, Material, ConstraintFixed
    auf Noppen, ConstraintForce mit Kantenreferenz-Richtung, 2nd-Order-Netz)
    mit Ergebnis-Dict vm_max/defl_max/defl_top/allowable/PASS; run_all_cases()
    ueber alle LF1-LF4. Zwei Root-Cause-Fixes gegenueber dem Brief-Entwurf:
    - SecondOrderLinear=True: ohne gerade Zwischenknoten erzeugt Gmsh an den
    kleinradiigen Details (Noppen R4, Vent-Bohrungen D4, Fase 4 mm) beim
    Grobnetz umgeschlagene quadratische Tets -> ccx-Fehler 201
    (nonpositive jacobian, 15 Elemente).
    - FemMesh.Nodes-Zugriff aus der Knotenschleife herausgezogen: die
    C++-Property baut das komplette Knoten-Dict bei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
2026-07-12 feat: FEM-Submodell des Segmentstoßes
    Implementiert FEM-Submodell zur Validierung des Halbüberlappungsstoßes als
    Kragarm unter horizontaler Stoßlast. Lappe (25×50×12.5 mm) wird mit voller
    Windlast (480 N) belastet und eingespannt am Übergang zum Segmentkern.
    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
2026-07-12 feat: Export von STEP/STL/3MF und Montagenotiz
    Implementiert export_all() mit automatischer Montagenotiz-Generierung (Spec §7).
    Exportiert Frame und 4 Segmente in STEP/STL/3MF-Formaten mit Parameterhash.
    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
2026-07-12 fix: Noppenfuß-Kerbentschärfung + seitenspezifische W_TOP-Kopplungen (Task 15)
    Heatmap 2026-07-12 zeigte alle LF-Hotspots am Noppenfuß des äußeren Rings ->
    NOPPLE_FILLET (45°-Übergangskegel) entschärft die Kerbe, GEOM_REV=2 hält den
    params_hash eindeutig. Ledger 21/22: Kammerraster (_chamber_cell_centers) und
    DFM lap_step koppeln jetzt an die W_TOP-Breite JEDER Seite statt am globalen
    min(W_TOP) — k<->Seite-Kanonik aus dem Code hergeleitet und per Geometrie-
    Probe verifiziert (k=0 REAR, k=1 RIGHT, k=2 FRONT, k=3 LEFT). Symmetrie-Anker
    bei Defaults bestätigt: chamber_slot_count/DFM-allowed/lap_step/top_area
    bitidentisch zu vorher, einziges Delta ist das erwartete Noppenkegel-Volum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
2026-07-12 fix: Zellenraster-Grenzen aus den senkrechten Nachbarseiten (Review-Critical)
    _side_neighbor_bounds(p): +u/-u-Hälfte je Seite mit eigener Nachbargrenze
    (k=0 REAR: RIGHT/LEFT usw., am Rotations-Mapping hergeleitet und per
    Isolations-Skriptprobe bewiesen). Symmetrie-Anker bitidentisch (hash 88bacca5,
    slots 24, allowed 36788.23, Volumen 1736006.07). Neue Wächter-Tests:
    Zentren-Grenzen bei W_TOP_REAR=90 + isolierte Eck-Massivprobe (alt 1463 mm³
    hohl -> neu 0.0).
    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
2026-07-12 fix: Ecksektor-Keepout klemmt das Zellraster (Review-Critical: falscher Referenzradius)
    Kritischer Punkt am Innenradius r_in1 (y(x)-Strahl), nicht r_out2. Keepout als
    Post-Zentrierungs-Filter (Pre-Clamp hätte das Default-Raster verschoben —
    numerisch belegt); Defaults bitidentisch (P_ECK 1694758.489540970), CELL_L=53-
    Kollision 516.30 -> 0.0 mm³. validate(): Kohärenzprüfung + CORNER_GAP.
    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
2026-07-12 docs: Spec-§9/§10-Drift nach Materialwechsel bereinigt (Z-Knockdown 0,8, ASA-CF, 5,44 MPa; todo-Altpunkt)
    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
2026-07-14 Review-Fixes (extern, 2026-07-14): Importer-Brecher, ehrliche Freigabe-Sprache, Manifest/Tempdir/Spec
    Adjudikation des externen Reviews -- alle Funde verifiziert, 6 gefixt:
    - scripts/messkampagne.py: A1c-f->W_TOP- und A4->REC_GUSSET-Mappings
    entfernt (durch Design-Entscheidungen 2026-07-13 ueberholt; haetten
    beim B-Lauf W_TOP=26 / REC_GUSSET_D=19.5 = validate-Brecher
    vorgeschlagen). Gelieferte Werte werden explizit als "BEWUSST NICHT
    uebernommen" gemeldet. NEU: Waechtertest mit der ECHTEN messwerte.json
    als Fixture inkl. validate() auf dem gepatchten Stand.
    - run_all.py: Schlusszeile konditional -- bei PASS MIT VORBEHALT heisst
    es jetzt "KEINE Druckfreigabe" statt "verifiziert f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
2026-07-14 Dach-Klaerung: B3=35 (gesamt), 140er-Welle bestaetigt, Holzrahmen-Einbauschritt
    - messwerte.json: B3=35 (User-Angabe 2026-07-14, Dach GESAMT -- deckt sich
    mit Challenger-Diagramm; Importer-Dry-Run: ROOF_T No-Op). XPS-Fehl-
    interpretation in DACH_VORAB korrigiert; JSON-Syntaxfehler (fehlendes
    Komma) gefixt. Wellenwahl 140 bestaetigt (effektiv 63 im Band 48-67).
    - Montagenotiz: Substrat-Vorbehalt der 12 Dachschrauben durch EINBAUSCHRITT
    ersetzt (User-Entscheid: Holzrahmen um den Ausschnitt ins XPS einleimen,
    Bestand ist nur geklebt ohne Holz) -> Schrauben greifen ins Holz und sind
    wieder tragende Redundanz; Ausschnitt vor dem Einsetzen messen (C1a),
    XPS-Schnittkanten versiegeln.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
2026-07-15 refactor: consolidate engineering and documentation pipelines
    [belluna_baugruppe.step, belluna_baugruppe.stl, belluna_dichtring.step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]
2026-07-15 release: package universal adapter 83aeba39
    [Belluna_Adapter_Universal_x4_83aeba39.step, Belluna_Adapter_Universal_x4_PRINT_83aeba39.stl]
2026-07-16 feat: replace roof screws with bonded interface
2026-07-16 release: publish adapter geometry 78f560c8
    [Belluna_Adapter_Universal_x4_78f560c8.step, Belluna_Adapter_Universal_x4_83aeba39.step, Belluna_Adapter_Universal_x4_PRINT_78f560c8.stl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]
2026-07-16 release: publish golden adapter 8029252d
    [Belluna_Adapter_Universal_x4_78f560c8.step, Belluna_Adapter_Universal_x4_8029252d.step, Belluna_Adapter_Universal_x4_PRINT_78f560c8.stl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]
2026-07-16 fix: enlarge roof spacer pads
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2026-07-16 release: publish golden adapter 8eb8b79f
    [Belluna_Adapter_Universal_x4_8eb8b79f.step, Belluna_Adapter_Universal_x4_PRINT_8029252d.stl, Belluna_Adapter_Universal_x4_PRINT_8eb8b79f.stl]
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2026-07-17 Toleranz-Sweep der Messkampagne + Validierungsplan ohne Gate-Charakter
    Neu: scripts/toleranz_sweep.py -- deterministischer Sweep (One-at-a-time +
    alle 1024 Toleranzband-Ecken + Freigang-Regime-Analyse) der zehn
    Messkampagnen-Parameter durch Parameter-Validierung, Haubenfreigang,
    Thermikfuge, Stossnachweis und Lastpfadcheck; reines Python3, Markdown auf
    stdout, optional JSON, Exit 1 bei Fail-Ecken. Drei Suite-Tests mit bewusst
    nur strukturellen Zusicherungen (die echte Messwertuebernahme bricht sie
    nicht).
    Kernbefunde des Erstlaufs, in Doku und Skill verankert: W_TOP hat beim
    aktuellen Parameterstand nach unten null Toleranz (50,0 mm = exakt die
    2-mm-Mindestbreite der Entwaesserungsfase; Mes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
2026-07-17 docs: Trains-of-thought-Audit -- 22 Drift-Fixes + praezise Gate-Metrik im Toleranz-Sweep
    Zwei-Pass-Audit der normativen Doku (typisiertes Register + gerichteter
    Lesedurchgang, Verifikations-Gate mit woertlichen Doppelzitaten; Autoritaet:
    params.py/Code/vermessene Rekonstruktion). 24 deduplizierte Kandidaten,
    22 bestaetigt und behoben, 2 verworfen (5,625 MPa = ASA-Substratschub,
    eigene Pruefung neben RK-1300; CFD-Transferfall ist die Eskalationsbehandlung).
    Wichtigste Fixes:
    - Toleranz-Sweep: _max_utilization spiegelt jetzt exakt die system_PASS-
    Komposition von assess() (explizite Pfade, KeyError bei Schema-Drift);
    die alte schluesselnamensbasierte Suche uebersah rk1300_utilization und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
